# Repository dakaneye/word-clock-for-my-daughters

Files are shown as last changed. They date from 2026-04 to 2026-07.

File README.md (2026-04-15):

# word-clock-for-my-daughters

Two word clocks, one for each daughter, to be delivered around their 7th birthdays.

- **Emory** — Oct 6, 2030
- **Nora** — Mar 19, 2032

Shared ESP32 + WS2812B platform, per-kid configuration (name, birthday, wood species, lullaby, hidden birthdate acrostic).

See [`docs/superpowers/specs/2026-04-14-daughters-clocks-design.md`](docs/superpowers/specs/2026-04-14-daughters-clocks-design.md) for the full design.

## Lineage

Follows the original word clock for my wife Chelsea, built 2015 and revived 2026, at [`dakaneye/word-clock`](https://github.com/dakaneye/word-clock). Same family, newer generation.

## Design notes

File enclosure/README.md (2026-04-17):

# Enclosure

Laser-cut SVG files for the daughters' word clocks (Ponoko-ready) plus the
generators that produce them. See `docs/superpowers/specs/2026-04-15-laser-cut-face-design.md`
for the design spec.

## Files

| File | Description | Material |
|---|---|---|
| `emory-face.svg` | Emory's face — 192×192 mm, Jost Bold letters | Maple Hardwood 3.20 mm |
| `nora-face.svg` | Nora's face — 192×192 mm, Fraunces Medium letters | Walnut Hardwood 3.20 mm |
| `frame.svg` | 4 frame strips with box joints (geometry is kid-agnostic — same file used for both clocks, different material) | Maple 6.40 mm (Emory) or Walnut 6.40 mm (Nora) |

## Regenerating

```bash
cd enclosure/scripts
pip install -r requirements.txt
python build.py
```

Outputs all SVGs to `enclosure/`. Idempotent.

## Tests

```bash
cd enclosure/scripts
pytest
```

---

## Current state (continuing later)

Last commit: `fix(enclosure): aspect filter for Jost B + simplify for Fraunces serifs`

**What's working:**
- 43 pytest tests passing
- Build script generates clean `emory-face.svg`, `nora-face.svg`, `frame.svg`
- `frame.svg` already verified in Ponoko's design checker, dimensions correct (192 × 207 mm)
- Both face SVGs include closed-counter struts (1mm width, asymmetric bridges)
- Self-review workflow: cairosvg-based rendering of SVGs to PNG at `/tmp/svg_review/` for visual inspection without round-tripping through Ponoko

**Latest renders** (saved locally — reviewed before committing):
- `/tmp/svg_review/zoom_jost_v21.png` — Jost Bold closed letters with struts, zoom
- `/tmp/svg_review/zoom_fraunces_v21.png` — Fraunces Medium closed letters, zoom
- `/tmp/svg_review/full_emory_v21.png` — full Emory face
- `/tmp/svg_review/full_nora_v21.png` — full Nora face

**Strut rules** (in `enclosure/scripts/path_ops.py::BRIDGE_RULES`):
- `O Q 0`: 2 vertical struts at 12 + 6 o'clock
- `R P D B`: 1 horizontal strut on left stem (B: per counter = 2 total)
- `A`: 1 horizontal strut on left diagonal
- `G 6 9`: 1 horizontal strut on left

**Strut geometry** (`path_ops.py::_apply_bridges`):
- Width: 1 mm (Chelsea's clock precedent — below Ponoko's published 3mm min; user confirmed 1mm works on their laser)
- Asymmetric bridge: `body_margin = 3mm` (punches through thick strokes) + `counter_margin = 1.5mm` (just visible inside counter, avoids hitting interior features)
- Filters: skip holes where `min(w,h) < strut_width` OR aspect > 2.0 (sliver/crossbar artifacts from overlapping primitives)
- Post-union cleanup: `buffer(0)` + `simplify(0.05 × strut_width)` to remove sub-laser-precision spikes

## Known remaining issues / open questions

1. **Fraunces letters at full-face scale may still show fine artifacts.** User reported "splash effect on almost every letter" on Fraunces non-strut letters in earlier renders. Changes since then:
   - `opsz` 14 → 72 (display variant, cleaner outlines)
   - Bezier flattening 16 → 64 steps
   - `simplify()` pass after union
   
   Still needs user confirmation that current render (v21) actually resolves the splash on non-strut Fraunces letters (T, I, H, etc.). If splash persists:
   - Try different weight (500 → 700 Bold → might render cleaner)
   - Tune `simplify` tolerance larger (trade: more smoothing vs letter fidelity)
   - Investigate if specific Fraunces axes (SOFT, WONK) need different settings despite being set to 0

2. **Jost B visual density.** B with 2 horizontal struts on left stem looks like "E with a bowl" at zoom. At actual face scale (10mm letter), the 1mm notches are only ~10% of letter height each → 2 struts = 20% notched → acceptable. User can confirm when reviewing full-face render.

3. **Ponoko design-checker verification for face SVGs.** Frame.svg is verified. Face SVGs haven't been re-uploaded since the strut fixes started. Once v21 passes user review, re-upload for final geometry check before ordering.

## How to pick up

1. `git log --oneline -20` for recent changes.
2. `cd enclosure/scripts && pytest` — should be 43/43.
3. Review latest renders:
   ```bash
   PY=/Library/Developer/CommandLineTools/usr/bin/python3
   DYLD_FALLBACK_LIBRARY_PATH=/opt/homebrew/lib $PY <<'PYEOF'
   import re, sys, shutil
   sys.path.insert(0, '.')
   import cairosvg
   from pathlib import Path
   OUT = Path("/tmp/svg_review")
   OUT.mkdir(exist_ok=True)
   for name, src, fill, bg in [
       ("emory", Path("enclosure/emory-face.svg"), "#1a1208", "#dcc09a"),
       ("nora", Path("enclosure/nora-face.svg"), "#f0e0c0", "#3d2817"),
   ]:
       txt = src.read_text()
       txt = txt.replace('fill="none" stroke="#0000FF" stroke-width="0.01"', f'fill="{fill}"')
       txt = re.sub(r'(<svg [^>]*>)', lambda m: m.group(1) + f'<rect width="192" height="192" fill="{bg}"/>', txt, count=1)
       tmp = OUT / f"{name}_preview.svg"
       tmp.write_text(txt)
       cairosvg.svg2png(url=str(tmp), write_to=str(OUT / f"{name}_preview.png"), output_width=2000)
       print(f"Rendered {OUT / f'{name}_preview.png'}")
   PYEOF
   ```
4. Open `/tmp/svg_review/*.png` to review.
5. If struts or letter shapes still wrong: edit `enclosure/scripts/path_ops.py` (strut logic) or `enclosure/scripts/render_face.py` (font config, letter sizing).

## Relevant files

- Spec: `docs/superpowers/specs/2026-04-15-laser-cut-face-design.md`
- Implementation plan: `docs/archive/plans/2026-04-15-laser-cut-face-implementation.md` (archived — SVGs shipped)
- Grid source of truth: `firmware/lib/core/src/grid.cpp`
- PCB (for LED positions): `hardware/word-clock.kicad_pcb`
- Brainstorm session with visual history: `.superpowers/brainstorm/5705-1776357082/`

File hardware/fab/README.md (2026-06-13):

# As-ordered fabrication package — 63-LED board

Exact JLCPCB submission for the word-clock main board. This directory is the
immutable as-fabricated record for the 40-year build.

- **Ordered:** 2026-06-07 — JLCPCB, 5 boards, full PCBA (top-side, Economic).
- **Contents:** `word-clock-gerbers.zip` (gerbers + drill), `word-clock-cpl.csv`
  (component placement), `word-clock-bom.csv` (bill of materials). The unzipped
  `gerbers/` directory is gitignored — the `.zip` is the canonical artifact.
- **LED substitution (as-built ≠ as-listed):** `word-clock-bom.csv` lists the
  LED as **WS2812B-B/W (LCSC C114586)**, but the board was ordered with
  **WS2812B-V6 (LCSC C52917433)** — the only in-stock option at order time. The
  swap is a benign revision (standard 5050-4P pinout, 800 kHz GRB); the V6's
  longer (>280 µs) reset is irrelevant at word-clock update rates. Full
  rationale: `docs/hardware/pre-fab-review.md`.
- **LED count:** 63 (designators D1–D64, with D7 unused).

Re-exports from KiCad go to `hardware/regen/` (gitignored); do not regenerate
this package in place.

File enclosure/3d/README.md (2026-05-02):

# 3D-printed internals

Scripts that generate STL files for the parts inside the clock case:
PCB standoff posts, button actuator caps, light channel. Each script is
parametric Python via [build123d](https://build123d.readthedocs.io/) —
edit a dimension at the top, re-run, get a new STL.

(A 3D-printed speaker cradle was originally planned but dropped 2026-04-21
once the speaker was found to have integral M3-compatible mounting flanges.
Speaker mounts to 2× M3 hex spacers epoxied to the back-panel interior.)

## First-time setup

```bash
cd enclosure/3d
python3 -m venv .venv
.venv/bin/pip install --upgrade pip
.venv/bin/pip install -r requirements.txt
```

(The `.venv/` directory is gitignored — it's ~500 MB of cached
OpenCascade CAD geometry, rebuilt locally on demand.)

## Generate STLs

Generate one part:
```bash
enclosure/3d/.venv/bin/python enclosure/3d/pcb_standoff.py
```

Generate every part at once:
```bash
enclosure/3d/.venv/bin/python enclosure/3d/build_all.py
```

Outputs go to `enclosure/3d/out/*.stl` (gitignored — regenerate any time).

## Printer workflow

See `docs/hardware/3d-printing-setup.md` — Bambu Studio setup, A1
onboarding, per-part slicer settings, VS Code live-preview workflow.

## Printing one of these

1. Open Bambu Studio (the slicer that ships with the A1).
2. `File → Import → Import 3MF/STL` → pick the `.stl` from `out/`.
3. Orient the part on the build plate. For the standoff: flange down so
   the glue surface prints flat against the bed; no support needed.
4. Choose a filament profile (PLA is fine for every internal part).
5. Click *Slice → Send* to the printer.

## Parts in this directory

| Script | Part | Qty per clock | Design source |
|---|---|---|---|
| `pcb_standoff.py` | PCB standoff post | 4 | `docs/hardware/pinout.md` §standoff |
| `button_cap.py` | Button actuator cap | 3 | `TODO.md` 3D-printed internals |
| (future) `light_channel.py` | Honeycomb LED isolator | 1 | `TODO.md` + `docs/superpowers/specs/2026-04-15-laser-cut-face-design.md` §Track 5; design deferred until frame interior + PCB outline are measured |

## Authoring a new part — the quick shape

Every script in this directory follows the same three sections:

```python
"""Explain the part in plain English at the top."""
from build123d import *
from pathlib import Path

# ─── Parameters ──
# All dimensions in mm. Source of numbers in comments.
MY_DIAMETER = 10.0

# ─── Geometry ──
# Primitive shapes combined with +, -, &.
# `align=(CENTER, CENTER, MIN)` = bottom of shape at Z=0, centered in XY.
BOTTOM = (Align.CENTER, Align.CENTER, Align.MIN)
part = Cylinder(MY_DIAMETER / 2, 10, align=BOTTOM)

# ─── Export ──
out_dir = Path(__file__).parent / "out"
out_dir.mkdir(exist_ok=True)
export_stl(part, str(out_dir / "my_part.stl"))
```

## build123d quick reference

Primitive shapes:
```python
Cylinder(radius, height, align=...)
Box(length, width, height, align=...)
Sphere(radius, align=...)
```

Boolean combine:
```python
part = a + b      # union
part = a - b      # subtract
part = a & b      # intersect
```

Transforms (apply with `*`):
```python
moved  = Pos(x, y, z) * shape
rotated = Rot(rx, ry, rz) * shape   # degrees
```

More complex shapes via 2D sketches then `extrude()`:
```python
profile = Polygon((0,0), (10,0), (10,5), (0,5))
part = extrude(profile, amount=3)
```

Docs: https://build123d.readthedocs.io/en/latest/

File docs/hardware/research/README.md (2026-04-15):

# Hardware research notes

Per-component research for the daughters' clocks hardware. Each file cites its source and captures the specific facts that inform `docs/hardware/pinout.md` and future PCB design.

When a spec is challenged ("are you sure GPIO 0 must be HIGH?"), the chain of evidence is: pinout.md → this directory → original manufacturer doc.

## Components researched

| Component / topic | File | Last verified |
|---|---|---|
| MAX98357A (I²S amp) | [max98357a.md](max98357a.md) | 2026-04-15 |
| WS2812B (addressable RGB LED) | [ws2812b.md](ws2812b.md) | 2026-04-15 |
| DS3231 ZS-042 (RTC breakout module) | [ds3231-zs042.md](ds3231-zs042.md) | 2026-04-15 |
| HW-125 (microSD SPI breakout) | [hw125-microsd.md](hw125-microsd.md) | 2026-04-15 |
| ESP32-WROOM-32 GPIO boot behavior | [esp32-gpio-boot-behavior.md](esp32-gpio-boot-behavior.md) | 2026-04-15 |
| USB-C CC resistors without PD | [usb-c-cc-resistors.md](usb-c-cc-resistors.md) | 2026-04-15 |
| FastLED on ESP32 — peripheral choice + WiFi | [fastled-esp32.md](fastled-esp32.md) | 2026-04-15 |

## Deferred until Phase 2 bring-up reveals questions

Nothing currently blocking schematic or PCB work. Add here as new questions emerge.

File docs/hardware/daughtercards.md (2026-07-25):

# Daughtercard Mechanical Measurements

**Status:** v1 — measurements complete, custom footprints generated at
`hardware/word-clock.pretty/`. Combines the 1×N pin socket/header with
NPTH mounting holes locked relative to pin 1.

All three daughtercards plug into the main PCB on **B.Cu (back side)**. The
"top" orientation in the tables below is the user's caliper-measurement
orientation: pin row up, looking at the *component* side of the daughtercard.

## Erratum — NPTH holes mirrored on fabbed boards (observed 2026-07-25)

On the assembled boards the daughtercard mounting NPTHs land mirrored
relative to the cards' actual holes — only **one hole per card** lines up.
Both clocks' boards are affected (same fab batch). Likely cause: the hole
coordinates below were measured looking at the card's component side, but
the cards mount on B.Cu, where that view is mirrored (unverified against
the layout).

Field fix: secure each card with a single screw + nylon nut through the
one aligned hole — SD takes **M2** (⌀2.0 mm holes), RTC takes **M2.5**
(⌀3.0 mm holes; M3 is a press fit, don't use). One screw plus the header
socket is mechanically sufficient; the cards carry no load. Keep the RTC
screw clear of CR2032 access. If the boards are ever respun, mirror the
hole coordinates across the pin-row axis and verify against a physical
card held to the back side.

## SD card breakout (Stemedu / Catalex-style microSD)

| Property | Value |
|---|---|
| PCB length (long axis, perpendicular to pin row) | **42.0 mm** |
| PCB width (short axis, along pin row) | **24.3 mm** |
| Pin-to-pin overall (PCB top → tip of pins) | 46.2 mm |
| Pin row offset, pin 1 → nearest long edge | ~5.5 mm (pins centered along short edge) |
| Mounting holes | 4 — one in each corner |
| Each corner hole, distance from each adjacent edge | **~2.0 mm** (1.9–2.0 mm both directions) |
| Hole diameter | **2.0 mm** (M2 clearance) |

**Hole positions in local footprint coordinates** (anchor = pin 1 at
`(0, 0)`, pins along +Y, card body extending in -X):

| Hole | Local X | Local Y |
|---|---:|---:|
| Top-left (near pin 1) | -2.0 | -3.8 |
| Top-right (near pin 6) | -2.0 | 16.5 |
| Bottom-left | -40.0 | -3.8 |
| Bottom-right | -40.0 | 16.5 |

(Y range derived from card width 24.3 mm centered on pin row midpoint
Y=6.35: card Y = -5.8 to 18.5; holes 2 mm in from each long edge.)

## RTC module (DS3231 ZS-042, GODIYMODULES variant)

| Property | Value |
|---|---|
| PCB length (long axis, perpendicular to pin row) | **38.2 mm** (web spec: 38 mm, matches) |
| PCB width (short axis, along pin row) | **22.0 mm** |
| Pin-to-pin overall (PCB top → tip of pins) | 44.0 mm |
| Pin 1 offset from one long edge | 3.4 mm |
| Pin 6 offset from other long edge | ~4.5 mm |
| Pin row position | offset (not centered); pins shifted toward pin-1 long edge |
| Mounting holes | 3 |
| Hole diameter | **3.0 mm** |

**Mounting hole positions** (user-orientation, pin row at top):

| Hole | From left edge | From right edge | From top edge | From bottom edge |
|---|---:|---:|---:|---:|
| Top-left | 3 mm | — | 8 mm | — |
| Top-right | — | 2 mm | 8 mm | — |
| Bottom-right | — | 2 mm | — | 4 mm |

**Local footprint coordinates** (anchor = pin 1 at `(0, 0)`, pins along +Y,
card body extending in -X, "left edge" = the long edge near pin 1):

| Hole | Local X | Local Y |
|---|---:|---:|
| Top-left | -8.0 | -0.4 |
| Top-right | -8.0 | 16.6 |
| Bottom-right | -34.2 | 16.6 |

## Audio amp (MAX98357A breakout, GODIYMODULES variant)

Adafruit-style MAX98357A clone. Adafruit's published dims are 17.78 × 18.42 mm
which matches user's measurement of 17.7 × 19 mm closely.

| Property | Value |
|---|---|
| PCB long axis | **19.0 mm** |
| PCB short axis (pin row sits on this edge) | **17.7 mm** |
| Pin row | centered on short edge; ~1.23 mm margin each side (15.24 mm pin span) |
| Mounting holes | 2 — at the corners of the *far* short edge (opposite pin row), confirmed by user |
| Each mounting hole, distance from each adjacent edge | **~2.3 mm** |
| Hole diameter | **2.6 mm** |
| Card-body extension direction relative to our PCB pin row | **+X** (pins on left, body on right of pin column) |

**Hole positions in local footprint coordinates** (anchor = pin 1 at
`(0, 0)`, pins along +Y, card body extending +X):

| Hole | Local X | Local Y |
|---|---:|---:|
| Far-edge-near-pin-1 corner | +16.7 | 1.07 |
| Far-edge-far-from-pin-1 corner | +16.7 | 14.17 |

(Y range derived from card width 17.7 mm centered on pin row midpoint
Y=7.62: card Y = -1.23 to 16.47; holes 2.3 mm in.)

## Custom footprints

Generated and checked into `hardware/word-clock.pretty/`:

- `Daughtercard_SD_HW125.kicad_mod` — 1×6 horizontal pin socket + 4× ⌀2.0 mm NPTH at corners
- `Daughtercard_RTC_DS3231.kicad_mod` — 1×6 horizontal pin socket + 3× ⌀3.0 mm NPTH
- `Daughtercard_AMP_MAX98357A.kicad_mod` — 1×7 vertical pin header + 2× ⌀2.6 mm NPTH at far short edge

The library is registered as `word-clock` in `hardware/fp-lib-table`. To
swap a daughtercard's footprint in eeschema, edit the symbol's Footprint
property to e.g. `word-clock:Daughtercard_SD_HW125`, then push the change
to PCB via Tools → Update PCB from Schematic. The new footprint replaces
the old socket and the mounting holes appear locked to pin 1 — drag the
connector and the holes follow.

Generated by `/tmp/gen_daughtercard_footprints.py` (which can be re-run if
measurements change).

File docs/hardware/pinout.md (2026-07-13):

# ESP32 Pinout — Daughters' Clocks

**Status:** v0 — source of truth for KiCad schematic (activity B), firmware config (Phase 2), and PCB layout (activity D). Subject to minor revisions if breadboard bring-up reveals pin conflicts or noise issues.

**Target module:** ESP32-WROOM-32 (classic ESP32, not S2/S3/C3). AITRIP 3-pack dev board from the Phase 2 parts order.

## ESP32 GPIO rules (for reference while reading this)

- **GPIO 6-11:** reserved for internal SPI flash. NEVER use.
- **GPIO 0, 2, 5, 12, 15:** strapping pins — have constraints at boot. Usable but with care.
- **GPIO 1, 3:** UART0 TX/RX — keep free for USB serial logging/flashing.
- **GPIO 34-39:** input-only, no internal pullup/pulldown.
- **GPIO 25, 26:** DAC-capable (unused here — we use I²S digital audio instead).

## Signal assignments

| GPIO | Direction | Signal | Subsystem | Notes |
|---:|---|---|---|---|
| 0 | — | (strapping, unused) | — | Must be HIGH at boot for run mode. Dev board has built-in pullup + BOOT button. On PCB: 10kΩ pullup to 3.3V. **Do not leave floating.** |
| 1 | TX | UART0 TX | Debug | USB serial console — reserved |
| 2 | — | (strapping, unused) | — | On-board LED on many dev boards; leave unused to avoid conflicts |
| 3 | RX | UART0 RX | Debug | USB serial console — reserved |
| 4 | — | (reserved) | — | Free for future use |
| 5 | OUT | SD CS | microSD | VSPI CS. Strapping pin — pull HIGH at boot to prevent boot loop |
| 12 | — | (strapping, unused) | — | Controls flash voltage (must be LOW at boot for 3.3V flash). Default pulldown is correct. Reserved — don't drive HIGH during boot. |
| 13 | OUT | LED_DATA | WS2812B | Data line into the LED strip. 3.3V→5V level may need a 74HCT245 or similar on PCB; test on breadboard first. |
| 14 | IN | BUTTON_AUDIO | Buttons | Play/stop audio. INPUT_PULLUP in firmware. |
| 15 | — | (strapping, unused) | — | HSPI CS default. Leave unused — HSPI not used here. |
| 16 | — | (reserved) | — | Free for future use |
| 17 | — | (reserved) | — | Free for future use |
| 18 | OUT | SD CLK | microSD | VSPI SCLK |
| 19 | IN | SD MISO | microSD | VSPI MISO |
| 21 | I/O | I²C SDA | RTC | Default I²C bus for DS3231. 4.7kΩ pullup — see Power section caveat. |
| 22 | OUT | I²C SCL | RTC | Default I²C bus for DS3231. 4.7kΩ pullup — see Power section caveat. |
| 23 | OUT | SD MOSI | microSD | VSPI MOSI |
| 25 | OUT | I²S LRC (WS) | Audio | MAX98357A word-select (LRCLK) |
| 26 | OUT | I²S BCLK | Audio | MAX98357A bit clock |
| 27 | OUT | I²S DIN | Audio | MAX98357A serial data in |
| 32 | IN | BUTTON_HOUR | Buttons | Hour-set button. INPUT_PULLUP. |
| 33 | IN | BUTTON_MINUTE | Buttons | Minute-set button. INPUT_PULLUP. |
| 34 | — | (reserved) | — | Input-only; free for future use |
| 35 | — | (reserved) | — | Input-only; free for future use |
| 36 | — | (reserved) | — | Input-only; free for future use |
| 39 | — | (reserved) | — | Input-only; free for future use |

## Subsystem summary

| Bus | Pins | Peripheral(s) |
|---|---|---|
| UART0 | 1 (TX), 3 (RX) | USB-serial debug |
| I²C | 21 (SDA), 22 (SCL) | DS3231 RTC |
| VSPI | 18 (CLK), 19 (MISO), 23 (MOSI), 5 (CS) | microSD card breakout |
| I²S | 25 (LRC), 26 (BCLK), 27 (DIN) | MAX98357A amplifier |
| GPIO | 13 (LED DATA), 14/32/33 (3 buttons) | WS2812B, tact switches |

## Power

- **Input:** USB-C from the back panel via a captive USB-C-to-USB-C cable (3-6 ft) permanently plugged into the ESP32 module's on-board USB-C port (the delivered AITRIP modules are USB-C, not the micro-USB assumed pre-delivery); the USB-C end exits through a back-panel cable hole at the bottom-right. The hole is 16 mm (drilled out from the as-cut 6 mm during assembly) so the USB connector overmold can thread through; strain relief comes from an internal cable P-clip screwed to the back-panel interior 2-3 cm in from the hole, not the grommet. No panel-mount adapter, no pigtail, no breakout board. The CP2102 bridge on the module handles enumeration for firmware flashing; the module's 5V pin feeds the main +5V rail. The Cermant USB-C breakout that originally appeared on the schematic was removed before submission; the rework record is archived at `docs/archive/hardware/2026-04-17-usb-c-breakout-removal.md`. Power negotiation is now whatever the module's USB-C input does (no PD chip anywhere; relies on the 5V/2A charger delivering full rated current).
- **Power budget (worst case):**
  - WS2812B 63 LEDs full white: ~3.8A @ 5V unconstrained — but firmware caps total LED draw at 1700 mA via `FastLED.setMaxPowerInVoltsAndMilliamps(5, 1700)` (sized for a 3 A USB-C supply, leaving headroom for the ESP32 + amp).
  - ESP32 WiFi active peak: ~500 mA @ 5V (after 3.3V reg) = 2.5W
  - MAX98357A at full 3W audio: ~600 mA @ 5V = 3W
  - **Combined peak with the 1700 mA LED cap: ~2.8A / 14W** — within a 3 A USB-C supply.
- **Mitigation:** the FastLED power cap auto-scales global brightness so the strip never exceeds 1700 mA no matter how many words are lit; bedtime dim plus rare audio keep typical draw well below peak (<700 mA).
- **5V rail:** powers WS2812B strip directly, plus MAX98357A.
- **3.3V rail:** from ESP32 dev board's onboard regulator (AMS1117-3.3). Powers DS3231, microSD breakout, MAX98357A logic, button pullups.
- **Decoupling:** 100nF ceramic on every IC's Vcc pin (added on PCB, not breadboard).
- **Bulk cap:** 1000µF electrolytic near the LED strip's 5V input (smooths WS2812B current spikes).
- **LED data line:** 300Ω series resistor in-line with DIN recommended (protects the first LED from voltage spikes on startup).
- **I²C pullups:** 4.7kΩ SDA + SCL — **verify the DS3231 breakout doesn't already have pullups** before adding them on the PCB. Stacking pullups drives the bus too hard. Adafruit DS3231 boards include pullups; cheaper clones vary.

## Mechanical — bottom-side component heights

Measured from the bottom face of the PCB outward. Drives the back-panel standoff
height (≥ tallest feature) and the total enclosure-depth budget.

| Ref | Part | Package | Est. height (mm) | Source |
|---|---|---|---:|---|
| C2 | 1000µF / 10V electrolytic | `CP_Radial_D10.0mm_P5.00mm` | **16** | common D10 radial cap spec; spec already cites this |
| U1 | ESP32-WROOM-32 dev module (52.16×28.47 mm PCB, 1.14 mm thick) | `ESP32_38Pin` on 2.54 mm headers | **12.26 (measured)** | Full stack end-to-end caliper-measured 2026-04-20. Slightly under the 13 mm estimate. |
| J_AMP1 | 1×7 header + MAX98357A breakout (GODIYMODULES clone, 17.66×18.73 mm PCB) | `PinHeader_1x07_P2.54mm_Vertical` + daughter | **~11.3** (no terminal, measured) / **~19** (screw-terminal) | 8.5 mm header + 1.6 mm breakout PCB + 1.23 mm chip side *(caliper-measured 2026-04-20; total breakout + component = 2.83 mm)*. **+8 mm if using screw-terminal variant** — decision: **skip the terminal**, solder JST-PH2.0 speaker leads direct to `+` / `−` pads. |
| J_RTC1 | 1×6 header + DS3231 ZS-042 (21.83×38.28 mm PCB, 1.09 mm thick) | `PinHeader_1x06_P2.54mm_Vertical` + daughter | **12.6 (measured)** | Full stack end-to-end (male pin tip through PCB to top of CR2032 holder) caliper-measured 2026-04-20. Module ships with 1×6 male header pre-soldered — no header to install. ~2.4 mm shorter than original 15 mm estimate. |
| J_SD1 | 1×6 header + HW-125 microSD breakout (24.22×42.03 mm PCB, 1.54 mm thick) | `PinHeader_1x06_P2.54mm_Vertical` + daughter | **7.27 (measured)** | Caliper-measured 2026-04-20; the pre-soldered 1×6 pin connector is the tallest feature (taller than the SD-card slot). ~5.7 mm shorter than original 13 mm estimate. Module ships with pin header pre-soldered — no header to install. |
| SW1-3 | 6 mm tact switches | `SW_PUSH_6mm` | **~8** | 5 mm body + 3 mm plunger |
| C1, C3-C6 | 100 nF ceramic disc | `C_Disc_D5.0mm_W2.5mm_P5.00mm` | **~7** | 5 mm disc + leads |
| U2 | 74HC245 DIP-20 | `DIP-20_W7.62mm` | **~4** | direct solder; add ~5 mm if using a socket |
| R1 | 300Ω 0207 axial (horizontal) | `R_Axial_DIN0207` | **~3** | horizontal orientation |

**Tallest feature (all caliper-measured 2026-04-20):** DS3231 at 12.6 mm and ESP32 module at 12.26 mm tie as the tallest installed daughterboards. All four measured under their original estimates — ESP32 12.26 mm (−0.74), MAX98357A 11.33 mm (−0.67), DS3231 12.6 mm (−2.4), HW-125 7.27 mm (−5.73). The screw-terminal-equipped MAX98357A variant would still be ~19 mm but we're skipping the screw terminal.

**Confidence:** [HIGH] for all four daughterboards — caliper-verified 2026-04-20.

**Headroom in standoff budget:** with all daughterboards measured, the 20 mm standoff recommendation has ~7.4 mm of headroom against the tallest (DS3231 at 12.6 mm). **Decision window open:** the standoff could drop from 20 mm to 15 mm and grow the light channel from 18 mm to ~23 mm for measurably better LED diffusion. Trade-off: tighter depth tolerance (2.4 mm margin vs 7.4 mm) and no assembly slack for thicker-than-expected components. Re-decide after diffuser-stack validation on the breadboard (Step 5 outcome).

**Back-panel standoff recommendation:** **20 mm** (off-the-shelf brass M3 standoff size; clears the MAX98357A screw-terminal variant with ~1 mm margin; clears all other components with 5+ mm margin).

**Enclosure-depth budget** (48 mm frame, per `enclosure/scripts/render_frame.py`):

| Layer | Thickness (mm) |
|---|---:|
| Face (wood, glued to top of frame) | 3.2 |
| Diffuser (paper or frosted PETG) | ~0.5 |
| Light channel | ~18 (remainder — see below) |
| PCB | 1.6 |
| Standoff (air gap for bottom-side components) | 20 |
| Back panel (wood) | 3.2 |
| Sum + ~1.5 mm assembly slack | 48 |

Light-channel depth of ~18 mm is well above the minimum for WS2812B diffusion (roughly 1× LED spacing ≈ 14 mm), so pockets will mix to uniform light before reaching the diffuser. If the MAX98357A variant turns out to be the 12 mm non-screw-terminal kind, the standoff can drop to 15 mm and the light channel can grow to ~23 mm for even better diffusion — decide after caliper pass.

## Firmware constants

When Phase 2 firmware modules land, these macros should be defined in a shared header (e.g., `firmware/configs/pinmap.h`) and imported by every module that touches hardware:

```cpp
#pragma once

// WS2812B LED strip
#define PIN_LED_DATA     13

// DS3231 RTC (I²C default pins)
#define PIN_I2C_SDA      21
#define PIN_I2C_SCL      22

// microSD card (VSPI)
#define PIN_SD_CS         5
#define PIN_SD_MOSI      23
#define PIN_SD_MISO      19
#define PIN_SD_CLK       18

// MAX98357A I²S amplifier
#define PIN_I2S_BCLK     26
#define PIN_I2S_LRC      25
#define PIN_I2S_DIN      27

// Tact switches (INPUT_PULLUP)
#define PIN_BUTTON_HOUR   32
#define PIN_BUTTON_MINUTE 33
#define PIN_BUTTON_AUDIO  14
```

## Datasheet-verified peripheral compatibility

Cross-checked 2026-04-15 against Adafruit NeoPixel Überguide, MAX98357A datasheet, DS3231 ZS-042 docs, and HW-125 microSD module docs.

| Peripheral | Vin range | 3.3V logic compatible? | Notes |
|---|---|---|---|
| **MAX98357A** | 2.5-5.5V (use 5V for full output) | ✅ yes — I²S tolerates 3.3-5V | Default GAIN = 9dB (floating). SD pin has internal 100kΩ pulldown; Adafruit breakout adds 1MΩ pullup to Vin → stereo-averaged output. Leave SD unconnected. |
| **DS3231 (ZS-042 module)** | 2.3-5.5V | ✅ yes — I²C is open-drain | **⚠️ Charging-circuit bomb — see Critical issues below.** Most ZS-042 clones have 4.7k-10k pullups onboard; verify with a multimeter before adding duplicates. |
| **MicroSD breakout (HW-125 style)** | 5V input OK | ✅ yes — onboard 3.3V regulator + 74LVC125A level shifter | Wire VCC to 5V, not 3.3V — the onboard regulator and level shifter need the higher input to work as designed. |
| **WS2812B LED strip** | 5V strict | **❌ no — needs level shifter** — see Critical issues below. | 60 mA / LED max; use 20 mA average for budgeting. |

## Critical issues to resolve BEFORE powering anything up

These are hardware modifications or additions required for safe operation. Do them in this order.

### ⚠️ 1. DS3231 ZS-042 trickle-charge circuit — skip the removal, mitigate with battery-swap cadence

**Decision (2026-04-20): we are NOT removing the 200Ω + 1N4148 trickle-charge resistor.** See `docs/hardware/assembly-plan.md` §Long-term maintenance for the CR2032 replacement cadence that makes this safe.

**The FUD-free picture:** The ZS-042 module has a 200Ω + 1N4148 trickle-charge circuit intended for rechargeable LIR2032 cells. We run a non-rechargeable CR2032 instead. The circuit only attempts to charge the battery when Vbat drops below (Vcc − 0.7V) — because the 1N4148 is reverse-biased otherwise.

At the design's **3.3V VCC** (DS3231 ties to the ESP32 module's 3V3 pin, not the 5V rail), the effective charge voltage is 3.3 − 0.7 = **2.6V**. A fresh CR2032 sits at 3.0V. The diode is reverse-biased → **zero charge current flows**. The circuit is functionally inert as long as the battery is above end-of-life voltage.

**What actually creates risk:** letting the CR2032 discharge below ~2.6V before replacement (it would then start charging, with leak/vent potential over years). Mitigation is replacement schedule, not hardware modification — see assembly-plan.md.

**Do NOT wire VCC to 5V.** On 5V the math inverts: 5.0 − 0.7 = 4.3V applied to the CR2032 (above its 3.0V) → active charging while powered → trickle-charge circuit engages → real risk. Our `pinmap.h` / pinout table ties DS3231 VCC to 3V3 intentionally.

### 🔴 2. WS2812B: level shifter is required, not optional

Adafruit's NeoPixel Überguide explicitly warns: **"a 3.3V signal may not work reliably."** The WS2812B logic HIGH threshold is 0.7 × Vdd = 3.5V at 5V supply. ESP32 outputs 3.3V max — 200 mV below threshold.

**Sometimes it works** (strip length, ambient temperature, LED batch tolerance all affect it). Sometimes only the first 10 LEDs light correctly. Sometimes colors drift. Relying on it is a bad idea for a keeper clock that must work for decades.

**Action:** include a **74HCT245** octal bus transceiver (or 74HCT125 quad buffer, same thing for this purpose) on the data line, powered from 5V, input from ESP32 GPIO13. The HCT family has TTL-compatible input thresholds — reliably reads 3.3V as HIGH and outputs 5V HIGH. Cost: ~$1. Not on the current wishlist; add to next order or rob from another project.

Alternative workaround (lower quality): single diode in series on Vdd to drop NeoPixel supply to ~4.3V, lowering the HIGH threshold to ~3.0V. Works but adds heat and reduces brightness. Not recommended for production.

### 🔴 3. WS2812B bulk capacitor is REQUIRED before power

Adafruit: "connect capacitor before applying power." A 1000µF electrolytic across the LED strip's +5V and GND inputs absorbs the inrush when all LEDs power up white. Already listed in the Power section — calling it out again here because skipping it can fry individual LEDs on first power-up.

## Pre-power smoke test (breadboard-bring-up protocol)

Follow this sequence when the parts arrive. **Do not skip steps.** Each check takes ~1 minute; total ~15 minutes before first power-on.

1. **Visual inspection.** Every breakout on a clean table. Verify no shipping damage, no bent pins, no foreign material.
2. **Multimeter: USB-C breakout.** Plug USB-C, verify 5.0V ±0.25V between 5V pad and GND pad. Verify CC1 and CC2 pads each show ~5.1kΩ to GND (unplugged). If either reading is wildly off — different board batch. Stop.
3. **Multimeter: DS3231 module.** With no battery installed:
   - Do **NOT** remove the 200Ω trickle-charge resistor (decision 2026-04-20, §1 above): at 3.3V VCC the 1N4148 is reverse-biased so it's inert with a fresh cell. The CR2032 is protected by the 5-year replacement cadence, not a desolder.
   - Verify SDA-to-Vcc and SCL-to-Vcc pullup resistance — typically 4.7k-10k. Note value for later; if present, **do not add external pullups to the PCB**.
   - Install a fresh CR2032 (+ side up).
4. **Multimeter: MAX98357A.** Verify GAIN pad (center) is not shorted to anything by default (floating → 9dB). Verify SD pad has a weak pulldown to GND (~100k) or weak pullup to Vin (1MΩ on Adafruit).
5. **ESP32 alone, no peripherals:**
   - Connect USB-C breakout to the ESP32's 5V and GND rails.
   - Apply USB-C. Measure 3.3V rail on the ESP32 — should read 3.30V ±0.1V.
   - Flash a blink sketch. Confirm the ESP32 runs. Disconnect power.
6. **Add RTC:**
   - Wire SDA, SCL, Vcc (3.3V), GND.
   - Flash an I²C scanner sketch. Expect to see address `0x68` (DS3231). Disconnect power.
7. **Add microSD breakout:**
   - Wire VSPI pins (CLK, MOSI, MISO, CS) and VCC to 5V, GND.
   - Insert a formatted FAT32 card.
   - Flash an SD read-test sketch. Confirm file listing. Disconnect power.
8. **Add MAX98357A:**
   - Wire I²S pins (BCLK, LRC, DIN), Vcc to 5V, GND, speaker via the JST-PH2.0 pigtail.
   - Flash a 440 Hz tone test. Confirm audible tone. Disconnect power.
9. **Add WS2812B (after level shifter):**
   - Wire 74HCT245: Vcc to 5V, GND to GND, A-input from GPIO13, B-output to strip DIN, OE/DIR tied for unidirectional.
   - Add 1000µF cap across strip +5V and GND, installed first.
   - Wire strip Vdd to 5V (short run, 18 AWG or better), GND to breadboard GND.
   - Flash a single-LED test at low brightness (e.g., 10/255). Confirm first LED lights the correct color. Then test 5 LEDs. Then the full 25.
10. **Full integration:** only after steps 1-9 pass independently, flash the Phase 2 firmware and run the full rig.

If any step fails, stop and debug **that step** before adding another peripheral.

## Revision log

- **v0 (2026-04-15):** Initial assignment based on ESP32-WROOM-32 standard pin conventions, Adafruit ESP32 Feather + MAX98357A reference designs, and the parts in the Phase 2 order. Locked pending breadboard validation (Phase 2 activity R).
- **v0.1 (2026-04-15, same day review):** Corrected GPIO 0 advice (was misleadingly said "leave floating"). Added power-budget analysis (worst case ~2.6A exceeds USB-C-without-PD spec). Added 300Ω series on LED data, I²C pullup-stacking caveat. Removed stale "Audio BFF" reference (that product is for QT Py, not classic ESP32).
- **v0.2 (2026-04-15, after datasheet review):** Added datasheet-verified compatibility table. **Critical findings:** (1) DS3231 ZS-042 module has a battery-charging circuit that must be disabled before installing a non-rechargeable CR2032 — risk of battery leak/explosion. (2) WS2812B level shifter (74HCT245) is REQUIRED, not optional — Adafruit explicitly warns 3.3V signals are unreliable. Added full pre-power smoke-test protocol. Raw research saved to `docs/hardware/research/`.

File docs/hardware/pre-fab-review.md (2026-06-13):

<!-- docs/hardware/pre-fab-review.md -->
# Pre-fab review — 63-LED board

> **ORDERED 2026-06-07** — JLCPCB, 5 boards, full PCBA (all 5 assembled, top-side
> Economic). Files: `hardware/fab/` (gerbers zip + CPL + BOM). LED substituted to
> **WS2812B-V6 (LCSC C52917433)** — only in-stock option; benign revision swap
> (standard 5050-4P pinout, 800 kHz GRB, V_IH handled by U2; V6's >280 µs reset is
> irrelevant at word-clock update rates). Confirm Production File + Confirm Parts
> Placement both set to Yes. On delivery: JLC placed only the 63 SMD LEDs — hand-
> solder all THT (ESP32 module, RTC/SD/amp headers, U2, R1, C2 + 100 nF caps,
> buttons), then run `firmware/test/hardware_checks/display_checks.md` (esp. the
> D1-glows-RED / GRB color-order check).

Findings from the full design audit (connectivity, power integrity, firmware
parity, ERC/DFM) and the actions to take before fabrication. The board is
electrically complete (0 unconnected, 0 DRC/ERC errors) and verified to light
evenly (worst-case +5V droop ~3 mV, <0.1%). Items below are correctness fixes
and good-practice hardening, in priority order.

## Verification (kicad-mcp-pro, 2026-06-05)

Full MCP validation suite run against the canonical board. **0 DRC errors,
0 unconnected** (confirmed by three independent tools), **0 ERC errors**. The
34 warnings are all benign and individually classified:

- 21 × silkscreen clipped by soldermask — cosmetic.
- 2 × daughtercard footprint ≠ library copy (SD HW-125, RTC DS3231) — cosmetic;
  the board's embedded footprint is authoritative for fab.
- 3 × connector symbol ≠ library (`Conn_01x06/07`) — cosmetic, pre-existing.
- 7 × "tri-state and power input connected" — U2's 7 unused inputs (A2–A8)
  correctly tied to GND. ERC pin-matrix false positive, not a defect.
- 1 × "74HCT245 not found in 74xx" — the 74HC→74HCT rename; the schematic's
  embedded symbol copy is electrically valid (this KiCad's `74xx` lib ships HC,
  not HCT). Optional cleanup: point the `lib_id` at `74xx:74HC245` (pin-identical)
  and keep `Value`=74HCT245 to silence the warning.

DFM "FAIL" lines are tool artifacts: "via drill -0.000 mm" is a parse bug
(`get_board_stats` shows real via drills at 0.300 mm); "DRC violations: 23"
re-counts the warnings above. Footprint-vs-schematic "FAIL" is only H1–H4
(NPTH mounting holes, no schematic symbol by design).

**Level shifter U2 (74HCT245) wiring verified from the board netlist:**
DIR=+5V (A→B), OE#=GND (enabled), A1=/LED_DATA_3V3 in, B1=/LED_DATA_5V out
(matched channel), unused inputs→GND, unused outputs floating. Data path:
`ESP32 GPIO13 → A1(3.3V) → B1(5V) → R1 300Ω → D1 DIN`.

**Firmware↔PCB parity verified:** the 35 per-word LED counts in
`firmware/lib/display/src/led_map.cpp` match the PCB's LED `Value` fields
exactly (35 words / 63 LEDs), and the spans tile the chain [0,63) with no gaps
or overlaps.

**LED grid + chain fully verified (2026-06-06):**
- Every LED is on a clean 13.68 mm row lattice; all **63/63 sit on the correct
  grid row** for their word, and **63/63 fall within the correct word's column
  span** (checked against `firmware/lib/core/src/grid.cpp`).
- The **physical daisy-chain (DOUT→DIN) order exactly matches the firmware
  `led_map` index order** (0 mismatches): data enters at D1 (IT, ← R1), exits at
  D63 (tail, DOUT open). So firmware index i lights the correct physical letter.
- CPL placement positions match the PCB footprint positions for all 63 LEDs.

Remaining parity is physical-only — **GRB color order** and face-overlay
registration — bench checks in
`firmware/test/hardware_checks/display_checks.md` (§2–§3).

## Already done (in this change)

- **Reconciled the rerouted board into canonical** `hardware/word-clock.kicad_pcb`
  (it was the old 15-unconnected hand-routed board; now it's the rerouted
  0-unconnected one, 187 vias). Verified by kicad-cli: **0 DRC violations,
  0 unconnected, 0 ERC errors.** Pre-reconcile board saved as
  `.pre-reconcile-*` if you need to compare.
- **74HC245 → 74HCT245** (U2 level shifter): the ESP32 drives the LED-data
  input at 3.3 V, below the 74HC high threshold (~3.5 V at 5 V VCC). 74HCT's
  threshold (~2.0 V) is in spec. Updated in the schematic, **PCB silk**, master
  BOM (`hardware/word-clock.csv`), and datasheet link.
- **Regenerated all fab exports for 63 LEDs** (the old ones were stale at 35),
  in `hardware/regen/`:
  - `word-clock-cpl.csv` — JLCPCB placement, 63 LEDs. **Verified:** transform
    reverse-engineered from the known-good 35-LED CPL and confirmed (D1 matches
    exactly). All 63 LEDs are **rotation 0, layer Top (F.Cu)** — uniform, no
    finicky rotations.
  - `word-clock-pcba-bom.csv` — 63 designators, LCSC C114586.
  - `word-clock-bom.csv` / `word-clock-pos.csv` — full BOM / raw KiCad pos
    (reference). NB: the raw KiCad `pos` export labels the LEDs "bottom" — that
    is a CLI artifact; the LEDs are on **F.Cu = Top** (the CPL is authoritative).
  Replace the stale `word-clock-*-pos.csv` / `word-clock-pcba-bom.csv` with
  these after the board reconciliation (step 1) and re-export the pos from the
  reconciled board so positions are sourced from the canonical file.
- **Firmware reconciled to 63 LEDs** (separate change): `LED_COUNT=63`,
  per-word LED spans derived from the PCB. Words now light fully and evenly.

### Decouple U2 — C1 moved +3V3 → +5V  (DONE 2026-06-06)
C1 (100 nF) sits **3.8 mm from U2** but was wired to **+3V3**, while U2 is a
**+5V** part and the ESP32 (the only +3V3 IC) is 80 mm away — a mis-railed
decoupling cap for U2. **Fixed and verified** (0 ERC errors, 0 DRC errors,
0 unconnected):
- Schematic: C1's `+3V3` pin detached and connected to a new `+5V` symbol.
  The +3V3 PWR_FLAG (`#FLG01`) was left in place on the remaining +3V3 stub,
  so +3V3 stays driven/flagged — the failure mode that broke an earlier
  by-hand swap (FLG short + `#PWR021` undriven) is avoided.
- PCB: C1 pad 1 re-netted to +5V and connected by a short F.Cu track straight
  to U2 pin 1 (+5V), 3.8 mm away — a low-inductance decap tie at U2's power
  pin. C1's orphan +3V3 branch (3 segments) was removed, each DRC-confirmed
  dangling; J_RTC1, C4, and the ESP32 stayed connected throughout. Zones
  refilled.

## Must do before fab

(none — the items below are resolved or judgment calls.)

### 3. Confirm daughtercard onboard pull-ups (assembly-time)
The main PCB has **no** I²C pull-ups and does not tie the MAX98357A SD_MODE —
both rely on the breakout modules:
- **RTC (ZS-042 / DS3231):** confirm it populates the onboard 4.7 k SDA/SCL
  pull-ups (most do). Without them, I²C floats and the RTC is unreadable.
- **Amp (MAX98357A breakout):** SD pin (shutdown + L/R select) and GAIN are
  left open, relying on the breakout's onboard pull-ups (SD pulled up =
  enabled, (L+R)/2 mono). Confirm the specific breakout populates them, or
  tie SD to a defined level — it doubles as a useful software-mute line.

Buttons need no external pull-ups: firmware sets `INPUT_PULLUP` on
GPIO32/33/14 (verified in `firmware/lib/buttons`).

## Optional / judgment calls

### 4. Input protection — optional, low marginal value
The audit flagged no fuse / reverse-polarity at the +5 V entry (back-fed
through the ESP32 dev-board VIN pin). In practice this is largely covered by
the USB-C supply's own limiting and the dev-board's USB protection, and
reverse polarity is not possible with USB-C. If you want belt-and-suspenders
on a 40-year keepsake, add a **polyfuse (~2 A)** in series at the +5 V entry
(a series Schottky / ideal-diode P-FET would add reverse-polarity protection
but costs ~0.3 V and board space). This adds parts + routing on a full
board — do it deliberately in KiCad, not as a quick patch.

### 5. Solid +5 V plane re-pour — not recommended
CLAUDE.md's intent was a solid B.Cu +5 V plane; the autoroute carved it into
one large island + a few bridged fragments. **This is already verified
electrically fine** (even-lighting droop ~3 mV; 54/63 LEDs on the main plane,
the rest behind low-current bridges). Re-routing a verified-working board to
chase a prettier plane risks regression for no functional gain. Skip unless
there's a specific reason.

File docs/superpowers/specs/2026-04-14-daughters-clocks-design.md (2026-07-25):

# Daughters' Word Clocks — Design Spec

Date: 2026-04-14
Status: Design locked, ready for implementation planning

## Overview

Two word clocks, one for each daughter, delivered around age 7. Same hardware platform, same firmware, per-clock configuration for name, birthday, acrostic, wood species, and lullaby. Intended to last 40+ years and feel handmade like Chelsea's — same DNA, newer generation.

- **Emory** — born 2023-10-06 — target delivery 2030
- **Nora** — born 2025-03-19 — target delivery 2032

## Scope

One design spec covers both clocks. Differences are configuration values, not design variants.

| Attribute | Emory | Nora |
|---|---|---|
| Face material | birch plywood | walnut |
| Name in grid (row 9) | EMORY | NORA |
| Birthday date | Oct 6 | Mar 19 |
| Hidden acrostic | `EMORY 10 6 2023` (12 chars / fillers) | `NORA MAR 19 2025` (13 chars / fillers) |
| Voice memo at birth minute | 6:10 PM, Dad's voice | 9:17 AM, Dad's voice |
| Lullaby (on-demand button) | one song recorded by Dad | one song recorded by Dad |
| Signature everyday color | warm white | warm white |

## Hardware Platform

- **MCU:** ESP32 (Arduino-core compatible). Picked for WiFi, I2S audio, mature libraries.
- **Time source:** NTP over WiFi; DS3231 RTC as offline fallback.
- **WiFi provisioning:** captive portal on first boot (phone connects to temporary AP, enters SSID + password in browser form). USB-C available as debug + firmware update path.
- **LEDs:** WS2812B RGB, one per word group (~25 per clock).
- **Audio:** MAX98357A I2S DAC + amp, small speaker (~2-3W), microSD card for 16-bit PCM WAV files (44.1 kHz mono). Format was flipped from MP3 during audio-module spec (`docs/superpowers/specs/2026-04-18-audio-design.md`) — eliminates the MP3 decoder dependency.
- **Power:** USB-C only. Any standard 5V/2A source drives the full system. No wall adapter specific to the clock.
- **Buttons:** three tact switches on the right side — hour set, minute set, audio play/stop.
- **No power button.** Always on when plugged in.

## PCB

Single board, ~150mm × 150mm, matching face dimensions. JLCPCB PCBA service assembles both sides.

- **Top side:** WS2812B LEDs placed under each word group on the face.
- **Bottom side:** ESP32 module, I2S amp, microSD slot, USB-C, buttons, DS3231, passives.
- **Connector to speaker:** 2-pin JST.

## Enclosure

Shadow-box construction. All visible exterior is wood. Plastic is hidden inside.

- **Face:** laser-cut wood (cut-through letters, not etched — the diffuser paper backing glows through the openings). Birch for Emory, walnut for Nora.
- **Side frames (4 pieces):** matching wood species, glued to form the box depth.
- **Back panel:** matching wood, engraved with dedication ("For Emory / love Dad" etc.). Carries 3 button access holes with "Hour / Min / Audio" labels next to each, a speaker vent grid, and one cable exit hole (~16 mm — drilled out from the as-cut 6 mm with a 5/8" step bit at assembly so the USB connector overmold can pass through). A permanently-installed Micro-USB-to-USB-C cable connects the ESP32 module's micro-USB port to the outside world; strain relief is provided by an internal cable P-clip screwed to the back-panel interior 2-3 cm in from the hole (the enlarged hole is too loose for a grommet to grip the cable). **Must be fully removable without damaging the wood, repeatably over 40+ years** — the DS3231 CR2032 coin cell needs replacement every 5-10 years. Attachment: 4 × M3 × 1/2"–5/8" wood screws threaded directly into the 6.4 mm hardwood frame wall at the existing 4 mm-inset corner positions, into pre-drilled ~2 mm pilot holes. The 4 mm panel inset puts the screw centers inside the wall thickness so screws bite into wood. (Original plan — M3 hex spacers epoxied into interior corners + machine screws — abandoned 2026-04-25 after the 4 mm-inset panel geometry was found to make spacer-in-corner placement impossible; the bug became a feature once we switched to wood-screws-into-wall.) Speaker mounts to 2 × M3 hex spacers epoxied to the back-panel interior 37 mm apart behind the vent — no 3D-printed cradle, the speaker has integral M3-compatible mounting flanges. The DS3231 and HW-125 daughterboards install with their battery holder / card slot facing the back panel (right-angle 1×6 sockets on B.Cu enforce this geometrically) so the CR2032 and SD card remain accessible after removing the panel.
- **Internal:** 3D-printed in white PLA — light channel honeycomb (isolates each LED to its word), PCB standoffs, speaker mount, button housings. Never seen.
- **Diffuser:** Selens self-adhesive diffusion film (0.16 mm) bonded to the back of the face. Single-layer stack — the original two-layer spec (film + 3.2 mm opal acrylic) was reduced to film-only on 2026-04-26 after bench testing showed the film alone provides adequate hot-spot suppression at the planned LED-to-film distance, and the opal acrylic introduced ~5 mm of lateral light bleed (its bead-scattered transmission spreads light laterally inside the 3.2 mm sheet). The two acrylic sheets ($37) are shelved as backup if hot spots emerge during full-clock first-light testing — the recovery design would be per-pocket acrylic cuts + light-channel walls extending through the acrylic level.

Dimensions: **7" × 7" face**, depth TBD during build (probably 1-1.5" to fit PCB + speaker + light channels).

## Letter Grid

13 columns × 13 rows. Dense QLOCKTWO style, same density as Chelsea's clock. 12 filler letters spell a hidden acrostic (name + birthdate).

### Emory's grid (reference — lit example: IT IS TWENTY PAST THREE IN THE AFTERNOON)

```
I T E I S M T E N H A L F       ← IT, IS, TEN, HALF · fillers: E, M
Q U A R T E R T W E N T Y       ← QUARTER, TWENTY
F I V E O M I N U T E S R       ← FIVE-min, MINUTES · fillers: O, R
Y H A P P Y P A S T T O 1       ← HAPPY, PAST, TO · fillers: Y, 1
O N E B I R T H T H R E E       ← ONE, BIRTH, THREE
E L E V E N F O U R D A Y       ← ELEVEN, FOUR, DAY
T W O E I G H T S E V E N       ← TWO, EIGHT, SEVEN
N I N E S I X T W E L V E       ← NINE, SIX, TWELVE
E M O R Y 0 A T F I V E 6       ← EMORY, AT, FIVE-hr · fillers: 0, 6
T E N O C L O C K N O O N       ← TEN-hr, OCLOCK, NOON
2 I N T H E M O R N I N G       ← IN, THE, MORNING · filler: 2
A F T E R N O O N 0 A T 2       ← AFTERNOON, AT · fillers: 0, 2
E V E N I N G 3 N I G H T       ← EVENING, NIGHT · filler: 3
```

Filler letters read in order: `E M O R Y 1 0 6 2 0 2 3` = **EMORY 10/6/2023**.

### Nora's grid

Identical to Emory's except row 9. NORA is 4 letters (vs EMORY's 5), so row 9 has one extra filler cell. Nora's grid therefore has 13 filler cells total (vs Emory's 12), and the acrostic is one char longer.

```
N O R A R 1 A T F I V E 9       ← NORA, AT, FIVE-hr · fillers: R, 1, 9
```

Filler letters in reading order across the full grid: `N O R A M A R 1 9 2 0 2 5` = **NORA MAR 19 2025** (13 chars).

### Word inventory (24 clock words + 4 birthday + 12 fillers)

Time-tellers: IT, IS, FIVE-min, TEN-min, QUARTER, TWENTY, HALF, MINUTES, PAST, TO, ONE, TWO, THREE, FOUR, FIVE-hr, SIX, SEVEN, EIGHT, NINE, TEN-hr, ELEVEN, TWELVE, OCLOCK, NOON, IN, THE, AT, MORNING, AFTERNOON, EVENING, NIGHT.

Birthday message: HAPPY, BIRTH, DAY, NAME. Woven across rows 4, 5, 6, 9.

Time phrasing uses "IT IS [minutes] PAST/TO [hour] IN THE MORNING/AFTERNOON/EVENING / AT NIGHT". The period suffix describes the **announced** hour, not the current one: in "TO" phrasing the suffix follows the upcoming hour (11:40 AM → "TO TWELVE NOON", 4:40 PM → "TO FIVE IN THE EVENING", 8:40 PM → "TO NINE AT NIGHT", 11:40 PM → "TO TWELVE AT NIGHT"). Special case: "IT IS TWELVE NOON" at 12:00 PM; midnight uses "IT IS TWELVE AT NIGHT".

## Firmware Behaviors

### Clock face

- **Default everyday color:** warm white. Same for both clocks.
- **Update cadence:** words refresh every 5 minutes (same as Chelsea's). Rounding is floor, matches QLOCKTWO convention.

### Bedtime dim

- **Trigger:** local time between 7:00 PM and 8:00 AM.
- **Behavior:** LEDs drop to ~10% brightness. Clock stays on, still shows time. No words blank out.

### Birthday mode

- **Trigger:** on the kid's birthday (Oct 6 for Emory, Mar 19 for Nora), all day.
- **Behavior:** HAPPY + BIRTH + DAY + NAME light up in rainbow cycle alongside the time words.
- **Birth-minute easter egg:** at the exact birth time on birthday (6:10 PM for Emory, 9:17 AM for Nora), plays Dad's voice memo through the speaker once.

### Holiday modes

Single-day color shifts. Clock displays time normally, but word colors use the holiday palette instead of warm white.

| Holiday | Date | Palette |
|---|---|---|
| MLK Day | 3rd Monday of January | purple |
| Valentine's Day | Feb 14 | red/pink |
| International Women's Day | Mar 8 | purple |
| Earth Day | Apr 22 | green/blue |
| Easter | computed (first Sunday after first full moon after Mar 21) | pastels |
| Juneteenth | Jun 19 | red/black/green (Pan-African) |
| Indigenous Peoples' Day | 2nd Monday of October | earth tones |
| Halloween | Oct 31 | orange/purple |
| Christmas | Dec 25 | red/green |

### Audio button

- **Button press:** plays the lullaby (pre-recorded by Dad) once, then stops.
- **Press during playback:** stops immediately.
- **Volume:** fixed in firmware, tuned by Dad during assembly. Not user-adjustable.

### Time sync

- **On WiFi:** NTP sync on boot and every 24 hours (±30 min jitter). Updates RTC.
- **No WiFi:** free-runs on DS3231. Drift is low (seconds per week) — acceptable.

## Per-Clock Configuration

Single source file (e.g., `config.h`) per clock selects the identity at compile time:

- Name string → drives row 9 letter layout
- Birthday month/day → drives birthday-mode trigger
- Birth time (hour:minute) → drives voice-memo trigger
- Acrostic string → drives filler-cell contents
- Wood species label → for the dedication engraving, no firmware impact

Same PCB, same firmware source, different compile-time flag.

## Delivery Timeline

- **Emory** — delivery window: around her 7th birthday, Oct 2030. Working backwards, prototype and iterate 2027-2029, lock design 2030.
- **Nora** — delivery window: around her 7th birthday, Mar 2032. Emory's clock is the prototype; Nora's is the second unit with any fixes baked in.

## Budget Estimate

Per clock:
- PCBA from JLCPCB (5 boards, since MOQ) — amortized ~$50 per clock
- Laser-cut wood face + frames — ~$40
- ESP32 module, speaker, microSD, buttons, USB-C — ~$30
- 3D-printed internals — ~$10 material
- Misc (paper diffuser, wire, glue, finish) — ~$20

**~$150-180 per clock**, not counting the 3D printer itself if you buy one.

## Open Items for Planning Phase

Deferred to `writing-plans` — not blocking the spec:

- KiCad schematic + layout details (pin budget, specific footprints, DRC)
- Firmware module breakdown (how time/color/animation/audio modules compose)
- Light-channel 3D model dimensions (wall thickness, depth, alignment to PCB LED pads)
- Laser-cut file format (SVG? DXF?) and vendor choice (SendCutSend vs Ponoko vs local)
- Audio file format/encoding, bitrate, SD card filesystem layout
- Captive portal UI design and WiFi credentials storage
- Testing strategy (unit tests for grid logic, hardware test sketches for audio/LEDs)

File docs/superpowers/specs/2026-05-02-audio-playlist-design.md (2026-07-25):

# Audio Playlist — Two-Lullaby Playback Design

**Status:** Design
**Author:** Sam
**Date:** 2026-05-02
**Supersedes / extends:** `docs/superpowers/specs/2026-04-18-audio-design.md`

## Summary

Replace single-file lullaby playback with a fixed two-file playlist
(`lullaby1.wav` → `lullaby2.wav`), played in sequence on a single Audio
button press. Birthday auto-fire (`birth.wav`) is preserved as a
separate single-file path with one behavior change: **birthday now
interrupts an in-progress lullaby** rather than being suppressed for the
year.

On the kid's birthday (month+day match, time synced at least once), the
Audio button plays `birth.wav` instead of the lullaby playlist — any
time that day. This routing (`PlayBirthdayRequested`, Idle-gated like
the lullaby request) is independent of the birth-minute auto-fire and
never touches the NVS year stamp, so button plays neither burn nor
block the 6:10 PM fire. With time never synced, the button falls back
to lullabies — an unsynced RTC must not false-fire on a garbage date.

## Motivation

The original audio design supported one button-triggered song. Sam's
bedtime routine for both daughters is a two-song sequence:

- **Lullaby 1** — "I Am Kind" by Raffi & Lindsay Munroe (shared across
  both clocks).
- **Lullaby 2** — per-kid: Emory gets "Three Little Birds", Nora gets
  "Take on Me".

A single button press should play both songs back to back, matching the
real bedtime routine. A second press at any point during playback stops
everything and returns to Idle.

## Behavior changes

Three decisions, captured here so future maintainers (or Sam in five
years swapping a CR2032 battery) understand the trade-offs:

### 1. Birthday interrupts lullaby (was: suppress)

The original design ran the birthday auto-fire guard only when the
state machine was `Idle`, so a lullaby playing at the exact birth
minute would suppress `birth.wav` for the entire year (NVS-gated to
once per year regardless). With lullaby playtime growing from ~3 min
to ~5-7 min in the new design, the suppression window also grows —
making "kid happens to be playing the lullaby at her birth minute"
increasingly likely.

New behavior: birthday auto-fire runs every tick regardless of state.
If the guard fires while a lullaby is playing, the lullaby is closed
and `birth.wav` opens immediately. After `birth.wav` ends, the state
machine returns to Idle (the lullaby does NOT resume — explicit
choice; resuming would require tracking position state).

### 2. Always restart from lullaby1 on press-after-stop

Stopping mid-playlist (e.g. kid fell asleep during lullaby2) and
pressing Audio again later **always restarts from lullaby1**, never
resumes from the stopped position.

Rejected: tracking last-played position across stops. Adds NVS writes
or RAM-only state, more code paths in the state machine, and the user
experience of "sometimes it picks up mid-song" is jarring without
clear visual feedback.

### 3. Missing files: log error, transition to Idle

If `lullaby1.wav` is missing on a press, OR `lullaby2.wav` is missing
when the playlist tries to advance from lullaby1's EOF, the audio
module logs an error to serial and transitions to Idle. No fallback
to the other file, no backward-compat with old `lullaby.wav` filename.

Same defense as the current single-file design. SD card content is
verified at assembly time; missing files indicate a card prep error
that should be loud, not silent.

`birth.wav` missing at auto-fire is also a log-error-and-stay-Idle
case, with one important wrinkle: the NVS year stamp is written
**before** the file is opened. If NVS stamps but `birth.wav` is
missing, the year is recorded as fired and birth.wav will not retry
this year. This matches the original spec's intent — once the system
"decides" to fire, it doesn't double-up later in the year, even if
the actual playback failed.

## Architecture

The new design extracts a pure-logic playback state machine into a
testable header (`audio/playback.h`) and wires it into the ESP32
adapter (`audio.cpp`). This pattern matches `audio/fire_guard.h` —
keep firmware-platform-independent logic native-testable, keep
SD/I²S/NVS calls in the adapter.

### State + track tags

```cpp
namespace wc::audio {

enum class State : uint8_t { Idle, Playing };
enum class Track : uint8_t { None, LullabyOne, LullabyTwo, Birth };

}
```

`State` keeps the existing two-state shape. `Track` tags which file is
currently open during Playing — necessary so EOF handling can branch
(advance lullaby1 → lullaby2, vs. terminate at lullaby2 EOF, vs.
terminate at birth EOF without auto-resume).

When `State == Idle`, `Track == None`. Otherwise `Track` matches the
file open in `current_file_`.

### Playback state machine

Pure-logic functions in `audio/playback.h`:

```cpp
struct PlaybackEvent {
    enum class Kind {
        PlayLullabyRequested,
        StopRequested,
        FileEnded,
        BirthdayFired,
    } kind;
};

struct PlaybackTransition {
    enum class Action {
        None,                 // no-op
        OpenFile,             // open path, start I²S
        CloseFile,            // stop I²S, close current file
        SwitchFile,           // close current, open new path
    } action;
    const char* path;         // valid when action is OpenFile / SwitchFile
    State next_state;
    Track next_track;
};

PlaybackTransition next_transition(State, Track, PlaybackEvent);
```

Native tests cover the transition table:

| Current state | Event | Action | Next state | Next track |
|---|---|---|---|---|
| Idle | PlayLullabyRequested | OpenFile | Playing | LullabyOne |
| Playing/LullabyOne | FileEnded | SwitchFile | Playing | LullabyTwo |
| Playing/LullabyTwo | FileEnded | CloseFile | Idle | None |
| Playing/Birth | FileEnded | CloseFile | Idle | None |
| Playing/* | StopRequested | CloseFile | Idle | None |
| Idle | StopRequested | None | Idle | None |
| Playing/* | PlayLullabyRequested | None | (unchanged)| (unchanged) |
| Idle | BirthdayFired | OpenFile | Playing | Birth |
| Playing/* | BirthdayFired | SwitchFile | Playing | Birth |

Note: `Playing/Birth + BirthdayFired` returns `SwitchFile` to re-open
`birth.wav` from the start. The NVS year-stamp gate ensures the
auto-fire guard doesn't return true a second time within the same
calendar year, so this row is unreachable in practice; the SwitchFile
behavior is benign defense-in-depth.

### Adapter responsibilities (`audio.cpp`)

The ESP32 adapter:

1. Calls `next_transition(state_, track_, event)` per relevant tick or
   button event.
2. Executes the returned `Action` via SD / I²S calls.
3. Updates `state_` and `track_` from the returned values.

The auto-fire guard runs every tick (not just when Idle). If the
guard fires:

- Pass `BirthdayFired` to `next_transition`.
- Stamp NVS year **before** executing OpenFile/SwitchFile (preserves
  fire-once semantics across power loss).

The button press handler in `main.cpp` calls `audio::play()` and
`audio::stop()`. `play()` routes internally: `PlayBirthdayRequested`
when `is_birthday()` (fire_guard) says today is the birthday and time
is known, `PlayLullabyRequested` otherwise.

## SD card content

Each kid's SD card holds three WAV files at the root, all 16-bit PCM
44.1 kHz mono little-endian:

| File | Emory | Nora |
|---|---|---|
| `/lullaby1.wav` | "I Am Kind" | "I Am Kind" |
| `/lullaby2.wav` | "Three Little Birds" | "Take on Me" |
| `/birth.wav` | birth-minute voice memo | birth-minute voice memo |

The old `/lullaby.wav` filename is **deprecated** and will not be
read by the new firmware. SD card prep procedure (in
`docs/hardware/assembly-plan.md` parallel-tracks) updates accordingly.

Per-clock total ~25-30 MB across all three files. Any microSD ≥1 GB
suffices; class 10 or better recommended for read latency margin.

## Public API

The audio module's external API is unchanged in shape:

```cpp
void begin(const BirthConfig& birth);
void loop();
void play_lullaby();   // semantics: starts the 2-song playlist
void stop();           // semantics: stops everything, no resume
bool is_playing();
```

Only `play_lullaby()`'s semantics change (it now starts a playlist
rather than a single file). `main.cpp` and the buttons / wifi_provision
modules require no changes.

## Failure handling

| Condition | Behavior | Log line |
|---|---|---|
| `lullaby1.wav` missing on press | Stay Idle | `[audio] error: file /lullaby1.wav not found` |
| `lullaby2.wav` missing after lullaby1 EOF | Transition to Idle | `[audio] error: file /lullaby2.wav not found` |
| `birth.wav` missing on auto-fire | Transition to Idle; NVS stamp persists; no retry this year | `[audio] error: file /birth.wav not found` |
| Any file's WAV header invalid | Transition to Idle | Existing `parse_wav_header` error code logged |
| `i2s_write` returns non-OK error | Dispatched as FileEnded (graceful degrade): on lullaby1 advances to lullaby2; on lullaby2 / birth.wav transitions to Idle | Existing `[audio] error: i2s_write err=...` line |
| SD card removed mid-playback | `current_file_.read` returns ≤0 → treated as EOF → transitions per state machine | Existing `finished` log line |

## Test plan

### New: `firmware/test/test_audio_playback/`

Native Unity tests of the pure-logic `next_transition()` function. One
test case per row of the transition table above. ~12-15 individual
assertions.

### Updated: `firmware/test/test_audio_fire_guard/`

No logic changes to the guard itself. Add coverage that confirms the
guard returns `true` independent of `already_playing` value when:
- Year not yet recorded
- Time is known
- Minute matches

This documents the new "interrupt during playing" intent.

### Hardware checks: `firmware/test/hardware_checks/audio_checks.md`

Add manual test steps:

1. **Playlist progression** — press Audio at Idle. Verify lullaby1
   plays, then lullaby2 plays automatically without further input,
   then state returns to Idle (silence).
2. **Stop during lullaby1** — press Audio during lullaby1 → silence
   immediately. Press again → restart from lullaby1, NOT lullaby2.
3. **Stop during lullaby2** — press Audio during lullaby2 → silence
   immediately. Press again → restart from lullaby1.
4. **Birthday interrupt** — set RTC to birthday minute via temporary
   firmware bypass, press Audio, wait for lullaby to start, then
   advance RTC by 1 second past the birth minute. Verify lullaby
   stops and `birth.wav` plays. After birth.wav ends, lullaby does
   NOT resume.

## Migration notes for in-progress build

Sam's current build (Emory and Nora's clocks, frames glued, faces
glued, light channels printed, PCBs in JLCPCB transit as of 2026-05-02)
is unaffected by this firmware change at the hardware level. Changes
required:

1. Rename / re-record audio assets on each kid's SD card to use the
   new file names.
2. Re-flash both clocks once new firmware is on `main`. Flash happens
   anyway during PCB bench-bring-up, so this is a single re-flash, not
   an extra step.
3. Update `firmware/test-sketches/` is NOT required — the playlist
   logic lives in `firmware/lib/audio/`, not in the test sketches.

## Risks

- **Lullaby2 missing scenario** is more likely than missing-lullaby in
  the original design (more files, more places to mess up SD prep).
  Mitigation: documented log line, hardware-checks step that catches
  it during initial bench bring-up.
- **Birthday-interrupts behavior** is a behavior change vs. the
  original spec. Documented above; the `should_auto_fire` guard's
  `already_playing` parameter is no longer used by the audio module
  (always called with `false`), but the parameter is preserved in the
  pure-logic API for future extensibility.
- **NVS stamp racing with file open** — if NVS write succeeds but the
  filesystem operation to open `birth.wav` fails, the year is
  recorded fired without playback. Documented as intentional in
  Failure Handling above. This matches existing single-file behavior.

## Out of scope

- **Per-song volume control.** Volume is fixed at compile-time per
  `CLOCK_AUDIO_GAIN_Q8`. If lullaby1 and lullaby2 have different
  loudness, the user normalizes them at the audio-prep step before
  copying to SD. Firmware does not normalize.
- **More than two songs.** Playlist is hard-coded at exactly two
  files. Generalizing would require SD-directory enumeration or a
  manifest file; both add complexity without current demand.
- **Crossfade / gap timing between lullaby1 and lullaby2.** The
  transition is whatever the SD/I²S latency happens to be (sub-100ms
  in practice). No designed silence period.
- **Resuming on power-on if power was lost mid-lullaby.** Power-on
  always starts in Idle state; no replay of in-progress lullaby.

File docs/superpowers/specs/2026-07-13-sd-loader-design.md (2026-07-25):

# SD Loader — Design

Load or update the firmware-expected audio files (`lullaby1.wav`,
`lullaby2.wav`, `birth.wav`) on the SD card inside a **closed** clock,
through the captive USB cable, then restore the clock to exactly the
firmware it was running. No screws.

Motivation: the clocks are sealed for years at a time, but the audio
content is meant to be re-recordable up to delivery (2030/2032) and beyond.
The SD card is wired to the ESP32; the ESP32 is reachable over the captive
cable; therefore SD contents are cable-serviceable — this tool makes that a
one-command operation for the next 40 years. Immediate driver: Emory's
clock is live and `birth.wav` must be real before her birthday (Oct 6).

## Locked decisions (2026-07-13, with user)

| Decision | Choice |
|---|---|
| Firmware restore | **Dump & restore**: read the full 4 MB flash image before touching anything; write it back byte-identical afterwards. No toolchain, keychain flags, or git state needed at restore time — works in 2035. |
| Input handling | **Auto-convert**: accept raw recordings in any format `afconvert` reads (Voice Memos `.m4a`, MP3, …); tool converts to spec WAV and validates. |
| UX | **One command**: stage → backup → load → restore → boot-check, fully narrated, walk-away. |
| Transfer | **WiFi pull**: loader firmware joins the home WiFi and HTTP-GETs files from a temporary server on the Mac (~1–3 MB/s, TCP integrity). Serial is the control + progress channel only. Serial *transfer* rejected: 30+ min at 115200 through a clone CP2102 with a known replay bug. |

## Components

### 1. Loader firmware — `firmware/tools/sd_loader/`

Standalone PlatformIO project (the test-sketch pattern, but under `tools/`
because it is a permanent lifecycle tool). Pins `espressif32@6.8.0` and the
`build_unflags = -std=gnu++11` line exactly like the main env (both are
load-bearing; see CLAUDE.md), and uses the same default 4 MB partition
table so the NVS partition sits at the same offset — the loader reads the
clock's stored WiFi credentials from the `wifi` namespace directly
(`ssid`/`pw` keys, same schema as `nvs_store.cpp`). The loader never
writes NVS.

Boot sequence: mount SD (same SPI pins as the audio adapter — source them
from `pinmap.h` by including the main project's core include dir), join
WiFi from NVS creds if present, then print `READY sd=<ok|fail>
wifi=<ip|none|failed>` and serve line-based serial commands at 115200.
The host sends `W` iff `wifi` is not an IP:

| Command | Effect | Responses |
|---|---|---|
| `W <ssid>\t<pass>` | Join WiFi with explicit creds (unprovisioned board, e.g. Nora at bring-up). Tab-separated — passwords may contain spaces. | `OK wifi <ip>` / `ERR wifi <reason>` |
| `G <url>\t<name>\t<size>\t<crc32>` | Stream-download `url` to `/<name>.part` on the SD, computing CRC32 while writing; then re-read the file from the card and re-CRC; on match, delete any existing `/<name>` and rename `.part` over it. | `PROG <name> <pct>` every ~5%, then `OK got <name> <size> <crc32>` / `ERR get <reason>` |
| `L` | List SD root: name, size, CRC32 per file. | `FILE <name> <size> <crc32>` ×N, then `OK list` |
| `D <name>` | Delete a file (stale test audio, orphaned `.part`). | `OK del <name>` / `ERR del <reason>` |

CRC32 is zlib polynomial on both sides (small table implementation in the
loader; `zlib.crc32` on the host). All output is human-readable — the tool
parses it, a human can read it.

### 2. Host orchestrator — `firmware/tools/sd_load.py`

The one command:

```
python3 tools/sd_load.py --lullaby1 A.m4a --lullaby2 B.m4a --birth C.m4a
python3 tools/sd_load.py ~/recordings/emory/     # dir: files named lullaby1.*, lullaby2.*,
                                                 # birth.* — whichever are present (≥1 required)
python3 tools/sd_load.py --dry-run               # pipeline proof, no real slots touched
python3 tools/sd_load.py --restore-only <backup> # recover a clock left in loader state
```

Steps, each narrated and each a hard gate:

1. **Stage** — `afconvert -f WAVE -d LEI16@44100 -c 1` each input into a
   staging dir; **canonicalize** the result to the 44-byte-header layout
   (afconvert inserts a `FLLR` padding chunk between `fmt ` and `data`,
   which the firmware's strict parser in `lib/audio/src/wav.cpp` rejects
   as `BadDataMagic` — the 2026-07-25 silent-lullaby bug); then validate
   exactly as strictly as the firmware parser (RIFF/WAVE, PCM, mono,
   44100 Hz, 16-bit, `data` at offset 36); compute CRC32 + size. Any
   problem aborts here, before the clock is touched. Partial sets are
   allowed (update only `birth.wav`) — unspecified slots are left alone
   on the card.
2. **Backup** — `esptool read_flash 0 0x400000` to
   `tools/.flash_backups/<UTC-timestamp>.bin` (directory gitignored;
   backups never auto-deleted). Baud 921600, falling back 460800 → 115200
   on failure (clone CP2102).
3. **Load** — flash the loader (`pio run -d tools/sd_loader -t upload`),
   start `http.server` on the staging dir bound to the Mac's LAN IP on an
   ephemeral port, open serial with the replay-safe recipe (reset-hold →
   flush → release), wait for `READY`, send `W` if the loader reports no
   NVS creds, then one `G` per file; verify every `OK got` CRC. Finish
   with `L` and print the card's final contents. `--dry-run` instead
   transfers a generated 100 KB test WAV to `dryrun.tmp` and `D`s it.
4. **Restore** — `esptool write_flash 0x0 <backup>` (esptool 4.x reads
   back and verifies written data itself; the old `--verify` flag is
   superfluous), reset, then
   reuse the boot-capture pattern to confirm health markers (boot banner,
   setup-complete, no RTC error; a rendered frame or WiFi-Online line ends
   the capture early when visible but is not required). Only then declare
   success. The backup image itself is verified (exact flash size + ESP32
   bootloader magic at 0x1000) before anything is flashed over the
   original.

Failure posture: once the loader has been flashed, any error triggers an
automatic restore attempt (finally-block semantics). If even that fails,
the tool prints the exact `--restore-only` command with the backup path.
The clock is never silently left as a loader.

### 3. Audible verification (separate, post-restore)

The Audio button already plays `lullaby1.wav` — that is the human check
for the lullabies. For `birth.wav`, add a `'b'` serial command to the
existing TEMP bench-sim block in `main.cpp` that plays the birthday file
on demand. It lives and dies with the other TEMP commands (stripped before
production). CRC equality remains the formal proof; ears are the comfort.

## Error handling summary

| Failure | Behavior |
|---|---|
| Bad/missing input audio, afconvert error | Abort in step 1; clock untouched |
| read_flash fails at all baud rates | Abort; clock untouched (still running its firmware) |
| Loader can't join WiFi | Reported over serial; tool restores flash and exits nonzero |
| Download CRC mismatch | Retry ×3, then restore + fail |
| Power loss mid-transfer | Only `.part` on card; existing files intact. The final swap (remove + rename — FAT can't overwrite-rename) has a millisecond window that can leave a slot empty; re-run the load to fill it |
| Restore write fails | Retry at lower baud; if exhausted, print `--restore-only` recovery instructions |
| Post-restore boot check fails | Exit nonzero with the backup path and capture transcript; flash image is still on disk |

## Testing

- **pytest** (`firmware/tools/test_sd_load_core.py`, following the repo's
  existing pytest precedents): WAV header validation, CRC/staging, serial
  response parsing, command formatting — the pure-logic half of the host
  tool, structured so it imports without pyserial/esptool present.
- **Loader firmware**: compiles standalone; verified live via `--dry-run`
  against Emory's clock — that run is the acceptance test for the whole
  pipeline and is also the moment we finally list what is on Emory's card.
- **First real use**: Emory's actual recordings, before Oct 6.

## Out of scope

- Serial file transfer fallback (WiFi is a hard prerequisite; a clock
  without WiFi in reach gets `W`-supplied credentials to any AP/hotspot).
- Reading files *off* the card (add a `P <name>` dump command later if a
  need ever appears).
- Any GUI. One command, one transcript.

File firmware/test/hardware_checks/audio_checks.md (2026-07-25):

# Audio Module — Manual Hardware Checks

These checks exercise the ESP32 paths that the native test suite
cannot reach: real I²S DMA + MAX98357A + speaker output, real SD
card open / read / close via VSPI, real `Preferences`/NVS round-trip
for `last_birth_year`, real `rtc::now()` for the auto-fire guard.
Run during breadboard bring-up after the MAX98357A + microSD paths
have been wired (`docs/hardware/breadboard-bring-up-guide.md`
§MAX98357A + Speaker and §MicroSD) and the ntp
(`ntp_checks.md`) and rtc (`rtc_checks.md`) checklists are green.

Spec: `docs/superpowers/specs/2026-04-18-audio-design.md`.

## Prerequisites

- ESP32 flashed with the current emory or nora env build.
- Captive-portal flow completed at least once (NVS holds valid
  WiFi creds + TZ; `seconds_since_last_sync()` is non-UINT32_MAX).
- MicroSD prepared with canonical WAV files at the card root:
  - `/lullaby1.wav` — 44.1 kHz / 16-bit / mono / PCM, ~3 min.
    (Originally `/lullaby.wav`; renamed for the 2026-05-02 playlist refactor.)
  - `/lullaby2.wav` — same format, ~3 min (added by the 2026-05-02 playlist).
  - `/birth.wav`   — same format, ~30 s.
  - Authoring recipe: Audacity > File > Export > Export as WAV;
    Encoding = "Signed 16-bit PCM", Sample Rate = 44100 Hz,
    Channels = Mono.
- MAX98357A hardware gain jumper set at the assembly default
  (9 dB unless bench measurement says otherwise).
- `CLOCK_AUDIO_GAIN_Q8` left at the default 256 for the first
  bring-up pass.
- Speaker connected to MAX98357A output terminals.
- Serial monitor open at 115200 baud.

## Checks

1. **Boot path observable.** Power on. Expect
   `[audio] begin: SD ok, I2S ok` in serial. If `SD FAILED`
   appears, re-seat the card and re-check VSPI wiring per
   `docs/hardware/pinout.md`.

2. **Lullaby play.** Once the clock is Online, press the audio
   button. Expect `[audio] play /lullaby1.wav` in serial (now
   `lullaby1.wav` after the 2026-05-02 playlist refactor), followed
   by audible playback through the speaker. Wait for natural EOF;
   expect `[audio] finished (played <N> bytes)` within ~3 min.
   Confirm the clock display continues rendering the current time
   during playback (display cadence is independent of audio). For
   playlist progression behavior (lullaby1 → lullaby2 auto-advance),
   see check P1.

3. **Button-during-playback stops.** Start lullaby. After ~10 s,
   press the audio button again. Expect `[audio] stopped (played
   <N> bytes)` in serial and immediate silence from the speaker.
   Press once more; expect fresh playback from the start.

4. **Volume sanity.** Listen for distortion / clipping on the
   loudest passages. If present: either re-encode the WAV at
   lower peak level (authoring fix), or lower `CLOCK_AUDIO_GAIN_Q8`
   to 181 (−3 dB) / 128 (−6 dB) via `configs/config_<kid>.h` and
   rebuild. Hardware jumper change (lower-gain resistor on
   MAX98357A) is the alternative if software trim isn't enough.
   Document the setting that worked in `docs/hardware/assembly-plan.md`.

5. **SD card removed mid-playback.** Start lullaby. Pull the
   microSD card from the slot. Expect either
   `[audio] error: i2s_write err=...` OR
   `[audio] aborted (played <N> bytes)` in serial, followed by
   silence. Re-seat the card; press the button again → plays
   successfully (no reboot needed).

6. **Missing file graceful.** Rename `/lullaby1.wav` →
   `/xxx.wav` on the card, re-insert. Press audio button. Expect
   `[audio] error: file /lullaby1.wav not found`; no sound. Stay
   Idle. (Originally `/lullaby.wav`; renamed for the 2026-05-02
   playlist refactor.)

7. **Invalid WAV graceful.** Place a stereo 48 kHz WAV (or a
   renamed .mp3) at `/lullaby1.wav`. Press audio button. Expect
   `[audio] error: wav header invalid (code=<N>)`; no sound.
   (Originally `/lullaby.wav`; renamed for the 2026-05-02 playlist
   refactor.)

8. **Birth auto-fire (simulated).** Pre-set the DS3231 via a
   bring-up sketch to 6:09:50 PM on Oct 6 of the current year
   (adjust month/day/time for the active env's `CLOCK_BIRTH_*`).
   Reset `audio/last_birth_year` to 0 via a wipe sketch OR by
   flashing a one-shot debug build that calls `Preferences::clear()`
   on the `"audio"` namespace at boot. Wait through 6:10:00 PM.
   Expect `[audio] play birth.wav (year=<current year>)` within
   one `loop()` tick of the minute roll. Confirm audible playback;
   wait for `[audio] finished`.

9. **Birth auto-fire fires once per year.** After check 8 passes,
   stay powered and wait until the next minute (6:11 PM). Expect
   no additional `[audio] play` log. Power-cycle. Expect no
   `[audio] play birth.wav` on next boot (NVS `last_birth_year`
   now matches the current year).

10. **Unknown-time gate.** Wipe NVS (hold Hour + Audio 10 s →
    `reset_to_captive`). Captive portal comes up; do NOT submit
    credentials. Pre-set the DS3231 to 6:10 PM on Oct 6 via the
    bring-up sketch. Verify no auto-fire — `time_known` is false
    because `seconds_since_last_sync()` reads UINT32_MAX. No
    `[audio] play birth.wav` log should appear.

11. **Birthday button routing.** With the DS3231 pre-set to any
    daytime hour on the birthday (e.g. 9:00 AM Oct 6) and time
    synced, press the Audio button. Expect
    `[audio] birthday today — button plays birth.wav` then
    `[audio] play /birth.wav` — NOT lullaby1. Confirm the 6:10 PM
    auto-fire still occurs later that day (button plays do not
    stamp `last_birth_year`). On any other date the button must
    play `/lullaby1.wav` as in check 2.

11. **ntp deferral during playback.** Start lullaby playback. In
    serial, confirm no `[ntp] sync ok` / `[ntp] forceUpdate()`
    log lines fire during the ~3 min playback window, even if a
    deadline would otherwise fire. After the lullaby finishes,
    confirm ntp resumes its normal cadence.

12. **Underrun sanity.** During playback, stress the main loop by
    adding a temporary `Serial.println(millis());` every loop tick.
    Playback should remain clean. Audible glitches here would
    point to DMA ring sizing being too tight — rare at
    4 × 1024 buffers (~93 ms of audio).

## Pass criteria

Checks 1–7, 11, and P1–P5 must pass before considering the module
hardware-verified. P1–P5 are required (not optional) since the
2026-05-02 playlist + birthday-interrupts refactor changed the
module's runtime behavior. 8–10 require a controlled pre-set DS3231
and may be deferred until a real birthday during burn-in. 12 is
diagnostic-only.

## Playlist + birthday-interrupts checks (added 2026-05-02)

These checks supersede the original single-file lullaby check from the
2026-04-18 audio spec. Run them once on each clock during bench
bring-up, and again after any audio-module firmware change.

### Check P1 — Playlist progression
1. Idle clock, SD card present with `lullaby1.wav`, `lullaby2.wav`,
   `birth.wav` at root.
2. Press the **Audio** button (SW2).
3. Verify `lullaby1.wav` starts playing audibly.
4. Wait for `lullaby1.wav` to end without pressing anything.
5. Verify `lullaby2.wav` starts playing automatically (no input required)
   within ~1 second of `lullaby1.wav` ending.
6. Wait for `lullaby2.wav` to end.
7. Verify the clock returns to silence (Idle) — no further audio.

### Check P2 — Stop during lullaby1 + restart
1. Press **Audio** to start the playlist.
2. While `lullaby1.wav` is playing, press **Audio** again.
3. Verify audio stops immediately.
4. Press **Audio** again.
5. Verify `lullaby1.wav` starts playing **from the beginning**, NOT
   `lullaby2.wav`. (Always-restart-from-lullaby1, per spec design
   decision 2.)

### Check P3 — Stop during lullaby2 + restart
1. Press **Audio** to start the playlist; let `lullaby1.wav` finish.
2. While `lullaby2.wav` is playing, press **Audio**.
3. Verify audio stops immediately.
4. Press **Audio** again.
5. Verify `lullaby1.wav` (NOT `lullaby2.wav`) starts playing from the
   beginning.

### Check P4 — Birthday interrupts lullaby
1. Set the clock's RTC to 1 minute before the configured birth minute.
   (E.g. for Emory: set RTC to October 6, 18:09.) Use a temporary
   firmware bypass or `rtc::set(...)` from a serial-trigger debug build.
2. Press **Audio** to start the playlist.
3. While `lullaby1.wav` is playing, advance RTC to the birth minute
   (October 6, 18:10).
4. Verify within ~1 second: `lullaby1.wav` cuts off and `birth.wav`
   begins playing.
5. Wait for `birth.wav` to end.
6. Verify the clock returns to silence — `lullaby1.wav` does NOT resume
   automatically (per spec).
7. (Optional) Power-cycle the clock and verify that on the next tick at
   the birth minute, `birth.wav` does NOT play again — the NVS year
   stamp is honored across reboot.

### Check P5 — Missing lullaby2.wav graceful handling
1. Prepare a test SD card with `lullaby1.wav` and `birth.wav` only
   (no `lullaby2.wav`).
2. Insert into the clock, power on.
3. Press **Audio** to start the playlist.
4. Verify `lullaby1.wav` plays normally.
5. After `lullaby1.wav` ends, verify the clock returns to silence
   (Idle). Serial log should show `[audio] error: file /lullaby2.wav not found`.
6. The clock should NOT crash or hang. Subsequent presses of Audio
   should still attempt to start `lullaby1.wav`.

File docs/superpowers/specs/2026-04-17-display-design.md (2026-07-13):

# Display Firmware Module — Design Spec

Date: 2026-04-17

> **⚠ SUPERSEDED IN SPECIFICS — read with the 63-LED migration in mind.**
> This spec captures the original **35-LED**, **1.8 A**-capped design. The
> board and firmware have since moved on; the concepts here (renderer
> priority chain, holiday palette, birthday rainbow, amber stale-sync, dim
> multiplier) still hold, but these numbers do not:
> - **63 LEDs, not 35.** A word now maps to a `LedSpan{start,count}` (2–3
>   adjacent LEDs for long words), not one index. Source of truth:
>   `firmware/lib/display/src/led_map.cpp` + `include/display/rgb.h`
>   (`LED_COUNT = 63`).
> - **Runtime power cap is 1700 mA**, not 1.8 A —
>   `FastLED.setMaxPowerInVoltsAndMilliamps(5, 1700)` in `display.cpp`. The
>   `PALETTE_MAX_RGB_SUM = 700` figure is now a per-word color bound, not a
>   total-power guarantee (total current is the runtime cap's job).
> - **Amber stale-sync threshold is 48 h**, not 24 h —
>   `STALE_SYNC_THRESHOLD_S` in `include/display/renderer.h`.
>
> When in doubt, the code + its native tests are authoritative over this doc.

## Overview

The `display` module turns the running clock state into pixels on the
35-LED WS2812B strip. It's the only firmware module that touches the
LED chain. Given time-of-day, date, a monotonic millisecond counter,
and the seconds-since-last-NTP-sync value from `wifi_provision`, it
produces the exact RGB value for every LED — including the holiday
palette shift, birthday rainbow cycle on the four decor words, amber
tint when the clock hasn't synced in 24 h, and the bedtime dim
multiplier. The pure-logic renderer composes cleanly with the Phase 1
modules (`time_to_words`, `holidays`, `birthday`, `dim_schedule`);
the ESP32 adapter is a thin FastLED wrapper.

Parent spec: `docs/superpowers/specs/2026-04-14-daughters-clocks-design.md`
(display listed as the first Phase 2 firmware module in TODO.md §Phase 2).

## Scope

**In:**
- Pure-logic `renderer::render(input) → Frame` that returns the final
  35-entry RGB array (dim multiplier already applied; caller writes
  it verbatim to the strip)
- `wc::display::begin()` + `wc::display::show(frame)` FastLED adapter
  (WS2812B on `PIN_LED_DATA` = GPIO 13 via 74HCT245 level shifter)
- `WordId → LED-chain-index` mapping table matching
  `hardware/word-clock-all-pos.csv`
- Palette lookup `(Palette, WordId) → Rgb` for all 10 palettes
  (warm white + 9 holiday palettes from `holidays.h`)
- Birthday-rainbow hue generator
  `(WordId, now_ms) → Rgb` for the 4 decor words
- Amber stale-sync color + `>24 h since last sync` threshold
- Dim multiplier applied inside the renderer (not via
  `FastLED.setBrightness`) so the renderer's output is the final,
  complete frame
- Native-testable pure-logic modules with Unity tests
- `#ifdef ARDUINO` guard on the FastLED adapter (same pattern as
  wifi_provision and buttons adapters — PlatformIO LDF otherwise
  pulls library sources into the native build)

**Out:**
- Deciding *whether* to call `render()` in a given frame — `main.cpp`
  owns the state-machine call for captive-portal / pre-sync boot
  (display just renders whatever it's told)
- RTC reads — `rtc` module owns DS3231 access; display consumes the
  date/time values it's handed
- NTP sync + tracking `seconds_since_last_sync()` — `wifi_provision`
  already exposes this
- Word-set computation — `wc::time_to_words()` (Phase 1) already
  returns the set of `WordId`s to light
- Holiday date detection — `wc::palette_for_date()` (Phase 1)
- Birthday detection — `wc::birthday_state()` (Phase 1)
- Brightness schedule — `wc::brightness()` (Phase 1)
- Voice-memo playback at the birth minute — `audio` module's job
- Any per-LED gamma, color-temperature correction, or FastLED power
  management — tunable during bring-up without changing this spec
- User-tunable palettes, weather-driven colors, scrolling-text modes
  — explicitly out (parent spec doesn't define them)

## Behavioral Contract

### Per-LED color precedence

Given inputs `(year, month, day, hour, minute, now_ms,
seconds_since_sync, birthday_cfg)`, for each `WordId w` the final LED
color is:

```
lit_set = time_to_words(hour, minute).words[0 .. count-1]
bday    = birthday_state(month, day, hour, minute, birthday_cfg)
palette = palette_for_date(year, month, day)
stale   = (seconds_since_sync > 86'400)  // UINT32_MAX also satisfies this

if bday.is_birthday:
    lit_set += {HAPPY, BIRTH, DAY, NAME}

if w not in lit_set:
    color = BLACK                                         // {0, 0, 0}
elif bday.is_birthday and w in {HAPPY, BIRTH, DAY, NAME}:
    color = rainbow(w, now_ms)                            // priority 1
elif palette != Palette::WARM_WHITE:
    color = color_for(palette, w)                         // priority 2
elif stale:
    color = AMBER = {255, 120, 30}                        // priority 3
else:
    color = WARM_WHITE = {255, 170, 100}                  // priority 4

color = color * brightness(hour, minute)                  // dim last
```

Priority from most-to-least important, locked during brainstorming:
**birthday rainbow (decor only) > holiday palette > amber stale-sync
> warm white**. Amber is a deliberate "don't fully trust the time"
signal; holidays and birthdays are celebration displays, so amber
yields to them.

### Rainbow

For `w ∈ {HAPPY, BIRTH, DAY, NAME}`:

- Phase offsets: `HAPPY=0°, BIRTH=90°, DAY=180°, NAME=270°`
- Hue: `hue_deg = ((now_ms % RAINBOW_PERIOD_MS) * 360 / RAINBOW_PERIOD_MS + phase_offset_deg) % 360`.
  Taking `now_ms % RAINBOW_PERIOD_MS` **before** the multiply keeps
  the intermediate product under `60'000 * 360 = 21'600'000`, well
  within `uint32_t` range. The naive form
  `now_ms * 360 / RAINBOW_PERIOD_MS` overflows `uint32_t` every
  `UINT32_MAX / 360 ≈ 3.3 hours` and produces a visible hue jump at
  each overflow boundary — unacceptable for a 60 s rainbow that
  must run for days.
- Output: standard HSV→RGB conversion at `sat=255, val=255`, done
  in a pure-C++ helper (`display::detail::hsv_to_rgb`) compiled
  into both the native and ESP32 builds. **Not** FastLED's
  `hsv2rgb_rainbow` — that variant has a custom non-linear hue
  distribution and would produce different colors than the native
  tests assert. Using a single HSV→RGB implementation across both
  environments keeps the renderer's behavior testable and
  deterministic; FastLED in the adapter is used only for pushing
  RGB bytes to the strip.
- `RAINBOW_PERIOD_MS = 60'000` — a full 360° cycle every 60 s.
- The `uint32_t now_ms` argument is allowed to wrap. Rainbow math is
  pure modular arithmetic on `now_ms`, so the hue increment across
  the wrap boundary is correct.
- **Full saturation and value** are returned pre-dim. The dim
  multiplier (step 7 of precedence) scales `val` afterward, producing
  dim-but-still-saturated rainbow at night.

### Birthday activation

- `birthday_state(...).is_birthday == true` for all 24 hours of the
  birthday date (midnight-to-midnight local, per parent spec).
- The birthday rainbow is active on decor words for that full window.
- `birthday_state(...).is_birth_minute == true` only at the exact
  birth hour:minute — not consumed by this module. The `audio`
  module uses it to trigger the voice-memo easter egg.

### Holiday palette cycling

`color_for(Palette p, WordId w)` is implemented as a `switch` over
named `Palette` enumerators — **not** as an array indexed by
`static_cast<uint8_t>(p)`. This keeps palette lookup robust against
`Palette` enum additions (a future `ST_PATRICKS` inserted between
existing values would silently break array-indexed lookup; the
switch form triggers `-Wswitch-enum` and forces the developer to
handle the new case).

Within a given palette, the word receives the color at:

```
color = palette_colors[static_cast<uint8_t>(w) % palette_colors.size()]
```

Cycling by `WordId` enum index (not by LED chain index) keeps the
palette lookup independent of PCB layout — the same palette logic
survives a PCB LED-reordering without test changes. Each word thus
receives a deterministic color within a given palette: on Halloween,
HAPPY (enum 31) gets `palette[31 % 2] = palette[1] = purple`; BIRTH
(enum 32) gets `palette[0] = orange`; etc.

### Palette power budget

Two-layer defense against palette-tuning drift blowing the PSU:

**Layer 1 — build-time check.** Every entry in every palette array
MUST satisfy `r + g + b ≤ PALETTE_MAX_RGB_SUM = 700`. Worst-case
current at this cap (all 35 LEDs lit to the sum cap simultaneously,
full brightness) is ≈ `35 × (700/765) × 60 mA ≈ 1.92 A`. The
existing defaults all fit well under 700 (max default entry is
`EASTER_PASTEL {255, 180, 200}` = 635). A
`test_palette_power_budget` Unity test enumerates every palette and
asserts the invariant on every entry, catching a bad palette tune
before it reaches the board.

**Layer 2 — runtime enforcement.** The adapter calls
`FastLED.setMaxPowerInVoltsAndMilliamps(5, 1800)` in
`display::begin()`. If the renderer ever emits a frame that would
pull more than 1.8 A on the strip, FastLED scales brightness down
automatically. This catches the "someone bumped the cap to 800 and
forgot to update the test" failure mode without damage.

The 1.8 A ceiling matches `docs/hardware/pinout.md` §Power budget
for the WS2812B strip alone, leaving headroom under the 2 A USB-C
cable rating for the ESP32 + RTC + amplifier + microSD draw.

Per-palette starting arrays (tunable on real hardware within the
sum-≤-450 constraint; the values below are defaults to commit with,
not final):

| Palette | RGB entries |
|---|---|
| `WARM_WHITE` | `[{255, 170, 100}]` |
| `MLK_PURPLE` | `[{128, 0, 180}]` |
| `VALENTINES` | `[{255, 30, 60}, {255, 120, 160}]` |
| `WOMEN_PURPLE` | `[{150, 50, 180}]` |
| `EARTH_DAY` | `[{30, 140, 60}, {30, 80, 200}]` |
| `EASTER_PASTEL` | `[{255, 180, 200}, {180, 220, 255}, {220, 255, 180}, {255, 230, 180}]` |
| `JUNETEENTH` | `[{200, 30, 30}, {10, 10, 10}, {30, 160, 60}]` |
| `INDIGENOUS` | `[{160, 80, 40}, {200, 140, 80}, {120, 60, 30}]` |
| `HALLOWEEN` | `[{255, 100, 0}, {140, 0, 180}]` |
| `CHRISTMAS` | `[{220, 30, 30}, {30, 160, 60}]` |

### Amber stale-sync

- Activation: `seconds_since_sync > 86'400` (strict >). `UINT32_MAX`
  (the "never synced this session" sentinel from
  `wifi_provision::seconds_since_last_sync()`) also satisfies this.
- Amber RGB: `{255, 120, 30}` (warm amber, ≈ 1800 K blackbody).
- Scope: amber replaces **warm white only**. On holiday days the
  palette wins; on birthday decor words the rainbow wins. This
  keeps amber from muddying celebration displays.
- Hysteresis: none. `seconds_since_sync` drops to 0 on a successful
  NTP, so the amber state exits on the very next render tick.

### Dim multiplier

Applied unconditionally as the last step per-LED. The renderer
derives an 8-bit multiplier from `wc::brightness(hour, minute)`:

```
const uint8_t bright_u8 = static_cast<uint8_t>(
    wc::brightness(hour, minute) * 255.0f + 0.5f);  // 26 or 255

r' = (r * bright_u8 + 127) / 255
g' = (g * bright_u8 + 127) / 255
b' = (b * bright_u8 + 127) / 255
```

`wc::brightness()` returns `0.1f` in the dim window (yielding
`bright_u8 = 26` — ≈ 10% of 255, with the half-step rounded up) and
`1.0f` otherwise (`bright_u8 = 255`). The per-channel formula is the
standard "multiply-by-8-bit, divide by 255, round-to-nearest" idiom:
`(x * a + 127) / 255`. Integer arithmetic keeps the render path
branch-light on ESP32, and the boundary behavior mirrors
`wc::brightness()` exactly: 18:59 is bright, 19:00 is dim, 07:59 is
dim, 08:00 is bright.

### Non-behaviors (explicit)

- **Stateless renderer.** `render()` is a pure function of its inputs.
  Rainbow animation emerges from `now_ms` changing, not from the
  renderer remembering the previous frame.
- **No transitions / fades** on word-set changes or day-boundary
  palette changes. The parent spec cadence is 5 minutes; hard-step
  matches QLOCKTWO tradition and Chelsea's clock.
- **No gamma correction** in v1. WS2812B + diffuser stack + dim
  multiplier already bend luminance; gamma is a bring-up tuning
  knob, not a spec requirement.
- **No color-temperature correction.** Face is hardwood; warm white
  on wood reads warm already.
- **No FastLED global brightness usage.** The renderer output is
  final. `show(frame)` memcpy's into FastLED's `CRGB[35]` and calls
  `FastLED.show()` — that's it.

## Architecture

Hexagonal. All color policy is pure logic, native-testable with Unity.
The ESP32 adapter is a thin FastLED wrapper.

```
firmware/lib/display/
  include/
    display.h                      public API (ESP32 only)
    display/
      rgb.h                        Rgb struct + Frame alias (header-only)
      led_map.h                    WordId → LED chain index (pure)
      palette.h                    Palette → Rgb lookup (pure)
      rainbow.h                    (WordId, now_ms) → Rgb (pure)
      renderer.h                   compose everything → Frame (pure)
  src/
    display.cpp                    FastLED adapter (#ifdef ARDUINO)
    led_map.cpp                    pure logic
    palette.cpp                    pure logic
    rainbow.cpp                    pure logic
    renderer.cpp                   pure logic
```

Tests:

```
firmware/test/
  test_display_led_map/test_led_map.cpp
  test_display_palette/test_palette.cpp
  test_display_rainbow/test_rainbow.cpp
  test_display_renderer/test_renderer.cpp
  test_display_renderer_golden/test_renderer_golden.cpp
```

Pure-logic `.cpp` files get added to `[env:native]`'s
`build_src_filter` in `platformio.ini`. `display.cpp` is guarded
with `#ifdef ARDUINO` — same reason wifi_provision's adapters are:
PlatformIO LDF's `deep+` mode pulls library sources into native
builds regardless of `build_src_filter`.
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

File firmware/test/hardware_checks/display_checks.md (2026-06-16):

<!-- firmware/test/hardware_checks/display_checks.md -->
# display — manual hardware verification

Run these after the full breadboard bring-up reaches
`docs/hardware/breadboard-bring-up-guide.md` §Step 9. Full WS2812B
chain (63 LEDs) on GPIO 13 through the 74HCT245 level shifter +
300 Ω series resistor + 1000 µF bulk cap.

Flash: `pio run -e emory -t upload`
Serial: `pio device monitor -e emory`

## 1. Boot + captive portal + blank face

- [ ] Serial shows `word-clock booting for target: EMORY`.
- [ ] Phone shows `WordClock-Setup-XXXX` AP. Face is all dark (no
      LEDs glowing) while in AP mode. Confirms main's
      `if state == Online` guard is in effect.
- [ ] Connect phone, submit valid WiFi creds via the form. State
      advances to Online per serial logs.

## 2. First light — warm-white clock face
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

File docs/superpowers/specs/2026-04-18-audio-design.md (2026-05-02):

# Audio Firmware Module — Design Spec

> **Note:** Single-file lullaby playback and the "birthday suppressed during lullaby" behavior described in this spec are superseded by [`2026-05-02-audio-playlist-design.md`](./2026-05-02-audio-playlist-design.md). The rest of this document (I²S setup, NVS stamping, gain control, file format) remains current.

Date: 2026-04-18
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

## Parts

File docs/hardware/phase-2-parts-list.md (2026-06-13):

# Phase 2 Parts List — Breadboard Bring-Up

> **⚠ HISTORICAL — completed breadboard buy-list (2026-04, all parts on hand).**
> Kept for reference. The production board is now 63 LEDs and the authoritative
> BOM lives in `hardware/fab/word-clock-bom.csv` (see `hardware/fab/README.md`
> for the as-built LED substitution). The roadmap table below is from April and
> is superseded by `TODO.md`.

**Gate:** Before Phase 2 of `docs/superpowers/plans/2026-04-14-daughters-clocks-implementation.md` can start. Phase 1 firmware logic is complete; this order unblocks hardware bring-up on a breadboard (no PCB yet).

**Budget:** ~$60-85 total for one breadboard kit. Only one set needed — Emory and Nora use the same hardware, differing only by compile-time config.

**Where we are in the roadmap:**

| Phase | Status |
|---|---|
| 0 — Repo + CI | ✅ Done |
| 1 — Native firmware logic | ✅ Done |
| **2 — Breadboard bring-up** | **← Blocked on this parts order** |
| 3 — KiCad PCB v1 | Needs Phase 2 learnings |
| 4 — Enclosure CAD | Needs PCB dimensions |
| 5 — Emory prototype | Needs PCB + enclosure |
| 6 — Nora unit | Needs Emory validated |

## Parts

### ESP32 DevKit V1 — **$8-12** × 1

- **What it is:** Small development board with an ESP32-WROOM-32 module, USB-to-serial chip (CP2102 or CH340), voltage regulator, and pin headers. Just plug into USB, flash firmware, go.
- **Why this clock needs it:** The ESP32 is the brain. It runs the firmware we built in Phase 1, drives the LEDs, talks WiFi for NTP time sync, plays audio over I2S, and reads button presses. Spec locks ESP32 because of the combination of WiFi + I2S audio + mature Arduino libraries.
- **What to look for:** Any variant with 30 or 38 pins, USB-C preferred (matches the final design). ESP32-WROOM-32E chip (the E is the 2020+ revision). Avoid ESP32-S2 / -S3 / -C3 variants for now — they have different pinouts and library quirks; stick with classic ESP32 to match the spec.
- **Sourcing:** Amazon Prime — "ESP32 DevKit V1 USB-C". Prime 2-day is worth the markup here.

### WS2812B LED strip, 1 meter @ 60 LEDs/m — **$8-12** × 1

- **What it is:** A flexible PCB strip with 60 addressable RGB LEDs per meter. Each LED has a tiny WS2812B controller chip built in; they chain together and you control them all over a single data line.
- **Why this clock needs it:** One LED per word group (~25 LEDs per clock). The letter grid sits behind a wood face with cut-through letters; each LED glows through one word's letters when that word is "on." WS2812B is the standard for this kind of project — FastLED library has good support, widely available, 5V-friendly.
- **What to look for:** 60 LEDs/m density (closest match to the word spacing on a 7" grid), IP30 (no waterproofing — unneeded indoors and takes up more space), 5V operation. Individually cuttable strip (scissors-friendly segments every 3 LEDs).
- **Why 1m when we only need 30:** You'll cut some, solder some wrong, and bring-up testing wants extras. $8 for a meter vs $6 for a cut length — not worth the hassle.
- **Sourcing:** Amazon — "WS2812B 60 LEDs/m 1m 5V strip". BTF-Lighting is a reliable brand.

### DS3231 RTC breakout board — ~~**$3-5** × 1~~ **Already owned**

> **Status:** Spare from Chelsea's clock restock (new 2-pack, one used for Chelsea, one spare). No need to order.

- **What it is:** A small module with the DS3231 real-time-clock chip, an AT24C32 EEPROM, a CR2032 battery holder, and I²C headers.
- **Why this clock needs it:** WiFi + NTP is the primary time source, but when WiFi is down (during setup, at grandma's house, after a router outage) the clock must keep ticking. The DS3231 is the industry's most accurate temperature-compensated crystal RTC — drifts only a few seconds per week. Spec calls it out explicitly as the offline fallback.
- **What to look for:** "DS3231 AT24C32" Chinese module. Comes with or without battery; buy a CR2032 separately if not included ($1 at any drugstore).
- **Sourcing:** Amazon Prime bulk packs (5 for $10 is common, cheaper per-unit — useful since you may break one).

### MAX98357A I²S amplifier breakout — **$6-10** × 1

- **What it is:** A small breakout with the MAX98357A — a 3.2W Class D audio amplifier with an I²S digital input and analog speaker output. Takes digital audio directly from the ESP32 (no separate DAC needed) and amplifies it enough to drive a small speaker.
- **Why this clock needs it:** The birthday-minute easter egg plays Dad's voice memo through the speaker. The on-demand lullaby button plays a recording. The MAX98357A is the standard small-scale solution — no external DAC, no complex wiring. Adafruit popularized it; many clones exist.
- **What to look for:** Adafruit product #3006 is the reference. Chinese clones on Amazon work fine for dev (look for ones with identical pinout). Solder the header pins yourself or get one with pre-soldered headers.
- **Sourcing:** Adafruit if you want the "known-good" version with documentation. Amazon clones are 50% cheaper and fine for breadboard testing.

### Small 8Ω speaker, 1-3W — **$3-5** × 1

- **What it is:** A mini speaker driver — 40mm diameter is a good size. Mylar cone, 8Ω impedance, handles 1-3W.
- **Why this clock needs it:** Plays the voice memo and lullaby through the MAX98357A. 3W is the max the amp can push; a 1W speaker will distort, 5W+ won't get loud enough at this power budget. 8Ω matches what the MAX98357A expects. Small enough to mount inside a 1-1.5" deep enclosure.
- **What to look for:** "40mm 8 ohm 3W mini speaker" — comes with flying leads you can crimp or solder to a 2-pin JST connector (spec specifies JST for the final PCB-to-speaker link).
- **Sourcing:** Amazon 4-pack or individually. CUI Devices or Dayton Audio for the serious version; generic clones fine for dev.

### microSD breakout (SPI) — **$3-5** × 1

- **What it is:** A small PCB with a microSD card slot and the level-shifter circuitry needed to talk to it over SPI from a 3.3V microcontroller.
- **Why this clock needs it:** Stores the MP3 files (voice memo + lullaby). The ESP32 has limited flash (~1-2 MB free for user data after firmware); audio files easily exceed that. microSD gives essentially unlimited storage and is trivial to reload by popping the card out.
- **What to look for:** SPI interface (4 wires + power). Some modules include 5V→3.3V regulation; that's fine but not required — ESP32 runs 3.3V logic and the card wants 3.3V too.
- **Sourcing:** Amazon 5-pack — they're basically commodity.

### microSD card, 4-32 GB — **$5-10** × 1

- **What it is:** A postage-stamp-sized flash storage card.
- **Why this clock needs it:** Hosts the audio files. 4 GB is vastly more than needed (a lullaby + a 10-second voice memo is <10 MB), but smaller cards are actually harder to find now than larger ones.
- **What to look for:** Class 10 or better (read speed ≥10 MB/s — overkill for audio but it's the baseline), FAT32 formatted (Windows default). SanDisk / Samsung / Kingston are all fine; avoid no-name brands (higher failure rate).
- **Sourcing:** Literally anywhere — drugstore, Amazon, Best Buy.

### USB-C breakout board — **$3-5** × 1 — *no longer on the final PCB, still useful for breadboard bring-up*

- **What it is:** A small board that breaks out a USB-C connector's pins to through-hole pads you can wire to.
- **Status in the final design:** Superseded. The final PCB powers everything through the ESP32 module's native micro-USB; the user-facing USB-C port on the back panel is the far end of a captive Micro-USB-to-USB-C cable exiting through a grommet. Historical rework record: `docs/archive/hardware/2026-04-17-usb-c-breakout-removal.md`.
- **Why it's still on the buy list:** Handy for the Phase 2 breadboard bring-up — lets you feed 5V/GND to the rail without relying on the ESP32 module's micro-USB while you're still probing things. Also a generic USB-C dev tool worth having.
- **What to look for:** "USB-C breakout 5.1k CC resistor" board — no PD chip needed. The 5.1k resistors on the CC pins request 5V default-profile power.
- **Sourcing:** Amazon "USB-C breakout 5.1k" search. Adafruit has a fancy version for $5.

### Tactile switches (6×6mm) — **$3 for a pack of 20** × 1 pack

- **What they are:** Little pushbutton switches. Press and it closes a circuit; release and it opens.
- **Why this clock needs them:** Three buttons on the side of the final enclosure — hour-set, minute-set, audio play/stop. For bring-up, you'll want extras because you'll inevitably bend a leg or desolder a wrong one.
- **What to look for:** 6×6mm through-hole tact switches, any actuation force (50-100gf is comfortable). Bag-of-20 packs are dirt cheap.
- **Sourcing:** Amazon — "6x6x5mm tactile push button switch 20 pack".

### Solderless breadboard (830 tie-point) — ~~**$5-8** × 1~~ **Already owned**

> **Status:** Salvaged from a larger dual-bus prototyping board (Va/Vb/Vc/Vd rails, ~2400 tie points). Better than the $10 kit, no need to order.

- **What it is:** A plastic board with a grid of holes that are internally connected in rows. Poke component leads in, poke jumper wires in, nothing needs to be soldered — you can rearrange freely.
- **Why this clock needs it:** Phase 2 is all about wiring everything together and testing, without committing to a PCB layout. Breadboard lets you move a button, add an LED to the data line, re-pin an I²S wire, all without a soldering iron.
- **What to look for:** "830 tie-point breadboard" is the standard size; fits an ESP32 dev board across the middle split. Metal backing plate is nice but optional.
- **Sourcing:** Amazon 2-pack. $6-8 total.

### Jumper wire kit (M-M, M-F, F-F mixed) — **$5-8** × 1 kit

- **What they are:** Short wires with pre-crimped pin connectors on each end. M (male) is a pin that plugs into a breadboard hole. F (female) is a socket that accepts a pin.
- **Why this clock needs them:** Connect breadboard points to dev-board pins (need M-F — female end plugs onto the dev board's header pins, male end into breadboard), breadboard-to-breadboard (M-M), and breakout-to-breakout (F-F when both have header pins).
- **What to look for:** Kit with 40 each of M-M, M-F, F-F in assorted colors. Length 20cm is a good default.
- **Sourcing:** Amazon "breadboard jumper wires kit" — one pack has everything.
- **Note:** An M-M-only set was salvaged alongside the breadboard; keep as extras, but the EDGELEC kit is still needed for M-F (required to connect the ESP32 dev board's male header pins into the breadboard).

### USB-C cable + 5V 2A USB charger — **$0-10**

- **What they are:** Just a charging cable and a USB power brick.
- **Why this clock needs them:** Powers the dev rig. Most phone chargers deliver 5V at 2A+ and work fine. USB-C cable must be a real one (not a charge-only USB-A to USB-C adapter) for the CC-resistor breakout to work.
- **Sourcing:** Probably already in a drawer at home. If not, any phone charger + cable.

## Total

Low estimate: ~$50. High estimate: ~$72. (DS3231 + breadboard removed — already owned.)

## Also salvaged (2026-04-15)

Pulled from a trashed prototyping stash:
- Dual-bus breadboard (~2400 tie points, Va/Vb/Vc/Vd rails) — replaces wishlist breadboard kit
- Assorted resistors (useful for pull-ups / current limiting on buttons and WS2812B data line)
- M-M jumper wires (extras; M-F still needs to be ordered)
- Alligator clip test leads (useful with a multimeter for probing)

## Wishlist (2026-04-15)

Amazon wishlist `4Q4NKIFBMW56` pulled together on 2026-04-15. Every parts-doc line above is covered. Multi-packs on most items (ESP32 3-pack, speaker 4-pack, MAX98357A 2-pack, breadboard 4-pack, tact switch 20-pack) — the right call for a first-time hardware order where spares save a re-order on a dev mistake.

| Doc line | Wishlist item | Note |
|---|---|---|
| ESP32 DevKit | AITRIP ESP-WROOM-32 3-pack, $16.79 | Multi-pack is smart |
| WS2812B strip | SEZO 5m / 300 LEDs, $13.99 | 5m vs my 1m suggestion — fine, same 60 LED/m density |
| DS3231 | — (already owned) | |
| MAX98357A | GODIYMODULES 2-pack, $6.88 | Spare amp included |
| 8Ω speaker | DWEII 4-pack 3W 8Ω **with JST-PH2.0 pre-attached**, $9.99 | Matches the final-PCB 2-pin JST connector — zero crimping needed |
| microSD breakout | Stemedu 2-pack, $5.99 | |
| microSD card | SanDisk 4GB, $18.95 | SanDisk Ultra 32GB is the same ~$19. Swap for 32GB — same price, 8× storage headroom. No money saved, but future-proof. |
| USB-C breakout | Cermant 10-pack with coupon, $8.99 | |
| Tact switches | QTEATAK 20-pack, $6.99 | |
| Breadboard | ~~BOJACK 3-value kit, $9.99~~ | **Remove — salvaged a better dual-bus board** |
| Jumper wires | EDGELEC 120pc M-M/M-F/F-F, $7.49 | |
| USB-C cable | Anker Nano 240W 6ft, $16.99 | Solid — the CC-resistor breakout needs a real USB-C cable, this is one. |
| 5V 2A charger | TCKN 2-pack, $11.99 | |

**Wishlist total: ~$125** after removing the breadboard (salvaged). SD card pricing is flat from 4GB to 32GB at this tier — swap to 32GB for headroom. Multi-packs account for most of the remaining spend and are worth it for first-time hardware bring-up. Ships in 1-2 days from Amazon Prime, 2-4 weeks from AliExpress (don't bother saving $10-15 on 3 weeks of waiting).

## After the order arrives

When the box shows up, say "Phase 2 plan" and I'll run `writing-plans` against the Phase 2 scope. Expected output: ~25-30 TDD tasks covering:

1. Smoke-test each IC individually with a throwaway sketch (LED-only, audio-only, RTC-only, button-only)
2. Display driver wrapping FastLED + the grid module
3. RTC + NTP time sync wrapper
4. Audio player reading MP3s from SD
5. Button debounce + handler
6. WiFi captive portal for first-boot provisioning
7. Main state machine that ties it all together

End of Phase 2: one working breadboard clock, running on Dad's desk for a week before we commit to PCB layout in Phase 3.

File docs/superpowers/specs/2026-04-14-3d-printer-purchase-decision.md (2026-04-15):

# 3D Printer Purchase Decision

Date: 2026-04-14
Status: Recommendation locked, awaiting purchase

## Summary

Buy a **Bambu Lab A1** ($350). Defer AMS Lite until a multi-color project forces the upgrade. Budget ~$485 total including calipers, starter filament, and basic consumables.

This decision serves the word-clock-for-my-daughters project (light-channel honeycomb, PCB standoffs, speaker mount, button housings — all small internal white PLA parts) as the initial use case, but the printer is chosen for a broader household/hobby use profile that extends well past the clocks.

## Use Case Profile

Ranked by expected frequency, based on brainstorm 2026-04-14:

1. **Household repair** — e.g., worn stove knobs where numbers no longer read
2. **Home/garage organization** — shelf brackets, pegboard systems, shed organization, drawer dividers
3. **Kid stuff for Emory & Nora** — name signs, toys, school projects, costumes
4. **Gifts** — personalized one-offs for family
5. **Desk/workspace** — cable management, holders, mods
6. **CAD as a new skill** — treating this as a gateway into parametric design
7. **Electronics projects** (light) — word-clock internals, future ESP32/Raspberry Pi enclosures

Deprioritized: outdoors/car (low interest).

## Claude Integration Profile

- **80% design workflow** — Claude generates parametric CAD from descriptions; I refine, slice, print. Printer-agnostic.
- **20% printer operation** — queue management, monitoring, failure detection. Nice-to-have, not required. Bambu's semi-closed ecosystem is acceptable because this tier is non-critical.

## Options Considered

| Option | Price | Verdict |
|---|---|---|
| Bambu Lab A1 Mini | $200 | Rejected. 180mm bed forces segmentation on garage/kid prints too often. |
| **Bambu Lab A1** | **$350** | **Chosen.** 256mm bed, fast, rock-solid reliability, open-frame fine for PLA/PETG. |
| Bambu Lab A1 + AMS Lite | $540 | Rejected (deferred). Multi-color fails more; master single-color first. Upgrade later. |
| Bambu Lab P1S | $700 | Rejected. Enclosed chamber / ABS capability buys nothing in the use profile. |
| Prusa MK4S | $800-1100 | Rejected. Better for "Claude runs the workshop" vision; overkill for 80/20 design-first profile. Higher setup friction conflicts with "reactive but iterative" usage pattern. |

## Rationale

1. **Build volume matches use cases.** 256mm handles ~90% of household/organization prints in one piece. The remainder segments cleanly with alignment pins or dovetails.
2. **No enclosure needed.** Use cases don't require ABS/ASA. PETG covers functional and moderately-outdoor needs. Enclosure spend doesn't pay back.
3. **Ease-of-use is a requirement, not a preference.** "Reactive but iterative" user profile means friction kills usage. Bambu A1's setup-to-first-print is ~30 min vs. Prusa kit's ~4 hours.
4. **Claude integration lives primarily in CAD**, which is printer-agnostic. Printer choice doesn't meaningfully constrain the 80% case.
5. **The 20% operation tier** is a side-project opportunity via community Bambu-MCP efforts. Fragile but low-stakes.
6. **AMS Lite is purely additive.** Deferring saves $180 now with zero upgrade regret later.

## Initial Purchase List

| Item | Est. Cost |
|---|---|
| Bambu Lab A1 | $350 |
| Digital calipers (sub-$40 range is fine) | $30 |
| Starter filament: PLA Basic, 4 colors (white, black, + 2) | $80 |
| Consumables: glue stick, scraper kit, spare 0.4mm nozzle | $25 |
| **Total** | **~$485** |

Deferred purchases:
- **AMS Lite** ($180) — trigger: first project that genuinely needs multi-color (likely a kid name sign or stove knob with color-inlay numbers)
- **PETG filament** — trigger: first functional print that needs heat/UV/outdoor tolerance
- **Enclosure kit** (3rd-party, ~$100) — trigger: only if I ever want to try ABS (unlikely given use profile)

## CAD Stack

Chosen for a software-engineering mindset + Claude-forward workflow:

- **OpenSCAD** — first tool for simple parametric parts (stove knob, spacers, brackets). Text-based, functional, trivial for Claude to read and write. Perfect for rotationally symmetric or obviously-parametric geometry.
- **CadQuery** — Python-based parametric CAD. For anything too complex for OpenSCAD but still model-as-code. Git-diffable, testable, LLM-friendly. This is the primary long-term target.
- **OnShape** (hobbyist tier) — browser-based constraint-based CAD with a real API. For complex mechanical assemblies where sketch-and-constraint thinking beats code. Public-models-only on the free tier.

Skip Fusion 360 — Autodesk license trajectory is hostile, and CadQuery covers the same ground for this use profile.

## First 90 Days: Project Sequence

Ordered to build skills incrementally:

1. **Benchy + factory calibration print** — day 1, comes with the printer
2. **Stove knob replacement** — canonical first real project. Measure spindle with calipers, model in OpenSCAD, iterate to fit. Paint-fill numbers for a two-tone look without AMS.
3. **Small desk organizer** — pen holder or cable clip. Fast feedback loop to build slicing intuition.
4. **Drawer divider or kitchen organizer** — first print that benefits from thinking about assembly / segmentation.
5. **Pegboard hook or shelf bracket for the garage** — first PETG print for strength/durability.
6. **Name sign for Emory or Nora** — first aesthetic piece. Single-color with paint fill OR trigger for AMS Lite purchase.
7. **Word-clock internals** (when the clock project reaches that phase) — light-channel honeycomb, PCB standoffs, speaker mount, button housings.

## Claude Integration Roadmap

Ordered by leverage-per-hour:

- **Phase 1 (day 1): OpenSCAD via Claude.** No integration needed — Claude writes OpenSCAD directly in-chat. Highest-leverage, zero-setup. This alone is most of the 80%.
- **Phase 2 (~month 1): CadQuery MCP.** Install an existing community MCP or write a thin one. Unlocks programmatic CAD with full Python power.
- **Phase 3 (~month 3): OnShape API MCP.** For complex assemblies. Useful specifically when mechanical constraints matter.
- **Phase 4 (~month 6, optional): Bambu local API MCP.** The 20% operation tier. Community Bambu-MCP projects exist; adopt or contribute. Only worth doing if a real workflow demands it — do not build speculatively.

## Open Questions

- Filament storage — dry box vs. ambient. Revisit after 30 days based on humidity observations.
- Slicer choice — Bambu Studio (default, proprietary) vs. OrcaSlicer (open-source fork, Bambu-compatible). Start with Bambu Studio; switch to OrcaSlicer if I hit a wall.

## Fallback: No Printer Available

If the Bambu A1 purchase is delayed, fails, or is otherwise unavailable when the clock project needs internals, outsource the ~4 internal parts per clock. They are all white PLA, small, non-structural, and hidden inside the enclosure — a perfect fit for online FDM services.

| Vendor | Fit | Est. cost (4 parts × 2 clocks) | Lead time |
|---|---|---|---|
| **SendCutSend** | Yes — now offers FDM print service alongside laser cut, already in use for the face | ~$60-80 per clock | 1-2 weeks |
| **Craftcloud** (hub / aggregator) | Yes — quote-comparison across multiple FDM services | ~$40-70 per clock | 1-3 weeks |
| **Shapeways / JLC3DP** | Yes | ~$50-90 per clock | 2-3 weeks |
| **Local maker-space** (e.g., Dallas Makerspace) | Possible if a membership makes sense by then | Membership cost | Variable |

The firmware and PCB design assume nothing about the origin of the printed parts. As long as the CAD files in `enclosure/` are vendor-neutral STEP + STL, any of the above will work. Budget impact: +$60-80 per clock vs. printing in-house. Still well under the $150-180/clock spec target (the per-clock budget has headroom).

**Decision deferral:** Revisit when Phase 4 (enclosure) starts — whichever delivers the parts on time wins.

## Non-Goals

- Print farm operation.
- Production/commercial printing.
- Exotic materials (carbon-fiber nylon, TPU, PC).
- Large-format prints (>256mm) that can't be segmented.

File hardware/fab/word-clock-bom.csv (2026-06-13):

Comment | Designator | Footprint | LCSC Part #
WS2812B-B/W | D1,D2,D3,D4,D5,D6,D8,D9,D10,D11,D12,D13,D14,D15,D16,D17,D18,D19,D20,D21,D22,D23,D24,D25,D26,D27,D28,D29,D30,D31,D32,D33,D34,D35,D36,D37,D38,D39,D40,D41,D42,D43,D44,D45,D46,D47,D48,D49,D50,D51,D52,D53,D54,D55,D56,D57,D58,D59,D60,D61,D62,D63,D64 | LED_WS2812B_PLCC4_5.0x5.0mm_P3.2mm | C114586

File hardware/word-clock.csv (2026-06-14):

Designators | Qty per clock | Part | Value | Footprint | LCSC | Notes
D1-D6,D8-D64 | 63 | WS2812B-V6 | Addressable RGB LED | LED_WS2812B_PLCC4_5.0x5.0mm_P3.2mm | C52917433 | As-built LED, JLC-placed. Design originally specced WS2812B-B/W (C114586); V6 substituted at order time — see hardware/fab/README.md. D7 intentionally unused (63 LEDs).
C1,C3-C23 | 22 | Ceramic capacitor | 100nF | Capacitor_THT:C_Disc_D5.0mm_W2.5mm_P5.00mm |  | THT decoupling, one per IC Vcc. Hand-soldered.
C2 | 1 | Electrolytic capacitor | 1000µF / 10V | Capacitor_THT:CP_Radial_D10.0mm_P5.00mm |  | Bulk cap at LED 5V input. Hand-soldered.
R1 | 1 | Resistor | 300 Ω | Resistor_THT:R_Axial_DIN0207_L6.3mm_D2.5mm_P10.16mm_Horizontal |  | LED data series resistor. Hand-soldered.
J_RTC1 | 1 | DS3231 ZS-042 RTC module | — | word-clock:Daughtercard_RTC_DS3231 |  | Amazon module on right-angle 1x6 socket. KEEP the trickle-charge resistor — inert at 3.3V VCC (1N4148 reverse-biased); CR2032 protected by the 5-year replacement cadence, not a desolder (decision 2026-04-20).
J_SD1 | 1 | HW-125 microSD module | — | word-clock:Daughtercard_SD_HW125 |  | Amazon module on right-angle 1x6 socket.
J_AMP1 | 1 | MAX98357A I2S amp breakout | — | word-clock:Daughtercard_AMP_MAX98357A |  | Amazon module. Hand-soldered.
SW1,SW2,SW3 | 3 | Tactile push switch 6mm | — | Button_Switch_THT:SW_PUSH_6mm |  | Minute / Audio / Hour. Bottom-side, pressed through the back panel.
U1 | 1 | ESP32 DevKit (CP2102 | 38-pin) | — | ESP32_DevKit_V1:ESP32_38Pin |  | Generic ESP32-WROOM-32 dev module (AITRIP). Inspect VBUS for a polyfuse before power.
U2 | 1 | 74HCT245 | Octal bus transceiver | Package_DIP:DIP-20_W7.62mm |  | 3.3V→5V level shifter for LED data. DIP-20, hand-soldered.

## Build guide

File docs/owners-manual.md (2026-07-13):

# Word Clock — Owner's Manual

One of two hand-built word clocks — Emory's (2030) and Nora's (2032).
Hardwood shell, 63 LEDs behind a laser-cut letter face, built to run for
40 years. This manual covers everything a caretaker needs; nothing inside
requires a soldering iron.

## Reading the clock

The face spells the time in words ("IT IS TWENTY TO EIGHT IN THE
EVENING"), updating each minute to the nearest five.

- **Evenings and nights (7 PM – 8 AM)** the letters dim to about a
  quarter brightness so they don't light up the room during sleep.
- **Amber-tinted letters** mean the clock hasn't been able to check the
  time over WiFi for 48+ hours. It still keeps good time on its internal
  battery clock — amber is a nudge to check the WiFi, not an alarm.
- **Holidays** bring special color palettes on their dates.
- **On her birthday**, at the minute she was born (Emory 6:10 PM,
  Nora 9:17 AM), the clock lights HAPPY-BIRTH-DAY with her name in
  rainbow and plays Dad's recorded birthday message. Once a year.

## First-time setup (or after moving / changing WiFi)

1. Plug the clock's USB-C cable into a power brick rated **3 A (15 W) or
   better**.
2. If the clock has no WiFi saved, it creates its own network named
   **WordClock-Setup-XXXX**. Join it from a phone; a setup page opens by
   itself (if not, browse to `192.168.4.1`).
3. Pick the home WiFi, enter its password, choose the timezone, submit.
4. **Press the AUDIO button on the back of the clock** when the page asks —
   this proves a person with hands on the clock approved the change.
5. The clock joins the WiFi, fetches the time, and starts telling it.
   Done — it needs nothing else, ever, day to day.

## The three buttons (back panel, engraved labels)

| Button | Press | Does |
|---|---|---|
| **AUDIO** | once | Play or stop the lullaby (two tracks, alternating) |
| **HOUR** | once | Advance the time one hour (for offline use — normally WiFi keeps time automatically) |
| **MIN** | once | Advance the time one minute |
| **HOUR + AUDIO** | hold 10 seconds | Forget the saved WiFi and reopen the setup network (step 2 above) |

## Battery replacement — every 5 years

The internal clock battery (a common **CR2032** coin cell) only works
during power outages, so it lasts many years — replace on a 5-year
calendar reminder rather than waiting for it to die.

1. Unplug the clock and lay it face-down on something soft.
2. Remove the **4 corner screws** on the back panel and lift the panel
   straight off. The inner plastic plate and the three button caps stay
   attached to it — **nothing falls out**.
3. The coin cell sits in a holder on the small clock board (the one with
   the battery). Slide the old cell out, press the new one in **+ side
   facing out of the holder**.
4. Before closing: press gently on each of the small plug-in boards to
   confirm they're firmly seated in their sockets (the clock board came
   loose once during assembly — a firm press is cheap insurance).
5. Set the panel back on, drive the 4 screws snug in a criss-cross
   order — firm, not gorilla-tight.
6. Plug in. The clock reconnects to WiFi and fixes its own time. Set the
   next calendar reminder for +5 years.

If a corner screw ever stops biting, drive it 0.5 mm deeper with a fresh
pilot hole or step up one screw length — the hardwood wall has plenty of
material.

## Troubleshooting

| Symptom | Likely cause → fix |
|---|---|
| Face completely dark | No power — check brick, outlet, and cable seating |
| Letters amber-tinted | No WiFi sync for 48 h — check the router; if the WiFi itself changed, hold HOUR+AUDIO 10 s and redo setup |
| Time wrong after an outage | Wait a minute for WiFi sync; if it stays wrong, the coin cell is likely dead — replace it (above) |
| No sound on AUDIO press | Open the back (4 screws) and reseat the SD card and the small audio board |
| A button feels gritty or stuck | Press it firmly a few times to seat it; if it persists, open the back and check the cap moves freely in its guide |
| Setup page never appears | Browse to `192.168.4.1` manually while joined to the WordClock-Setup network |

## Spare parts and repairs

Every custom part is reproducible — sources and print files live in this
repository under `enclosure/` (printed parts), `hardware/` (circuit
board), and `firmware/` (the program).

- **Button caps** (the only custom part likely to ever wear): spares were
  printed with the originals. To swap one: back panel off, circuit board
  lifted off its four posts, press the old cap's neck from the outside of
  the panel until it pops out of its socket, snap the new one in.
- **Coin cell**: CR2032, any brand.
- **Re-recording the audio** never requires opening the clock: with the
  clock's USB cable plugged into a computer and the home WiFi up, the
  loader tool in the project repository (`firmware/tools/sd_load.py`)
  sends new recordings inside (the cable controls the clock; the audio
  travels over WiFi). The back only comes off for hardware — battery,
  or a physically failing card.
- **Power**: any USB-C brick, 3 A / 15 W or better.

## Vital statistics

| | |
|---|---|
| Size | 192 × 192 mm face, hardwood shell |
| Power | 5 V USB-C, 3 A brick recommended; captive cable exits the back |
| Brain | ESP32; reprogrammable over the same USB-C cable, no disassembly |
| Time | WiFi (NTP) with battery-backed clock (DS3231) as keeper |
| Display | 63 addressable LEDs, one per word, warm white |
| Sound | Two recorded lullabies + a birthday message, from an SD card inside |

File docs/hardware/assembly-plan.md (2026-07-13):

# Assembly Plan

End-to-end glue-up + fasten-up sequence for each clock. Single source of
truth once all parts are in hand. Emory is the pilot build; Nora follows with
fixes baked in.

Prereqs: PCB validated on breadboard (Phase 2 firmware bring-up complete),
final PCB ordered and received from JLCPCB, 3D-printed internals printed,
wood arrived from Ponoko, supplies on the `TODO.md` order list in hand.

---

## Fastener + adhesive BOM (per clock)

| Item | Qty | Purpose |
|---|---|---|
| M3 × 1/2" or 5/8" wood screws (pan-head, brass or steel) | 4 | Back-panel-to-frame-wall closure (thread directly into the 6.4 mm frame wood at the existing 4 mm corner inset; pre-drilled pilot hole) |
| M3 × 10 mm brass hex spacer, F-F (measured 4.5 mm AF) | 2 | Speaker mount risers — drop through the carrier plate's hex collars and stand on the panel wood, 37 mm apart behind the vent. No adhesive; the hex bore stops rotation |
| M3 × 6-8 mm machine screws | 2 | Speaker integral flanges → speaker hex spacers |
| Rubber grommet for ~16 mm panel hole + cable P-clip | 1 | USB cable strain relief; back-panel hole gets drilled out 6 → 16 mm at assembly so the connector overmold fits through |
| ~~Self-adhesive black foam (1 mm)~~ | 0 | **Decision 2026-07-07: no top-edge seal** — channel wall tops press directly on the film. Foam/putty held as a G2 retrofit if first-light shows bleed at the channel/film interface. |
| M3 washers (optional) | 4 | Under screw heads on the back panel to protect the wood |

**Adhesives**

| Joint | Adhesive | Why |
|---|---|---|
| Frame box joints (4 corners) | Titebond III preferred; Gorilla 5-min epoxy works as substitute | Strongest wood-to-wood; epoxy-on-finger-joints relies on joint geometry for strength but needs ≥30 min clamp time, not the 5 the label implies (Nora's frame is being assembled with epoxy 2026-04-25) |
| Face top edge → frame top | Titebond III (do NOT substitute 5-min epoxy here) | Large flat-on-flat perimeter joint; 5-min epoxy's ~3 min open time is too fast for face alignment, and squeeze-out is much harder to clean off a visible exterior joint than wood glue is |
| Speaker hex spacers | **None** — spacers pass through the carrier plate's hex collars and stand on the wood under screw compression | Superseded the epoxy plan when the carrier plate (`enclosure/3d/pcb_carrier.py`) replaced loose parts, 2026-07-11 |
| Carrier plate → back panel interior | **None — dry fit (decision 2026-07-12, Emory build)** | Every in-service load is compression (button presses squeeze plate against panel; the screwed-down 48.0 stack holds it captive); laterally it's pinned by the spacers in the hex collars and the caps in the panel holes. Dry fit keeps every part individually replaceable over the 40-year horizon; glue can be added later if float ever annoys, but never removed |
| Light-channel top edge → diffusion film (on face back) | **None (2026-07-07)** — direct PETG-on-film contact under screw compression; foam/putty retrofit only if G2 shows bleed | Interface bleed judged at G2. (Diffuser stack is film-only as of 2026-04-26 — opal acrylic was removed from the production stack after bench testing showed it was the source of lateral bleed.) |
| Inner letter islands → face back | self-adhesive diffusion film | Ships pre-glued; the same film also retains loose letter islands |

**Tools**

- 4 × corner clamps (Bessey right-angle or equivalent)
- 2-4 × bar clamps (face-to-frame glue-up)
- Framing square (12"+)
- Tape measure / caliper
- Sanding block, P220 grit
- Needle-nose tweezers (letter islands)
- Small Phillips screwdriver (M3)
- Scissors (diffusion film cutting; X-Acto + steel ruler unnecessary at this precision level)
- 5/8" step drill bit (cable port drill-out, Phase F2)
- ~2 mm drill bit (frame wall pilot holes for back-panel wood screws, Phase G9)
- Masking tape (clamping substitute + alignment)

---

> **STACK CORRECTION (2026-07-09, found on the bench):** the interior cavity
> is the FULL 48.0 mm (face glues ON TOP of the frame walls, back panel screws
> UNDERNEATH them). The original stack table wrongly counted the face + panel
> thicknesses (6.4 mm) inside the 48.0, which sized the PCB standoffs 6.4 mm
> too short (22.0 → correct 28.4 panel-to-PCB-underside). The carrier plate
> (`enclosure/3d/pcb_carrier.py`, posts 25.9 + web 2.5) and the button caps
> (`button_cap.py`, anvil redesign) carry the corrected numbers. The light
> channel (17.84) is unchanged: 28.4 + 1.6 + 17.84 + 0.16 = 48.0 exactly.
> The old loose `pcb_standoff.py` posts (22.0) were superseded and the
> script deleted 2026-07-12.

## Phase A — Pre-assembly prep

Do all of this before opening any glue. Most of these are independent and
can run in parallel.

- [ ] **Inspect Ponoko wood pieces.** Confirm face dimensions 192 × 192 ×
      3.2 mm, frame strips 192 × 48 × 6.4 mm × 4 strips, back panel
      192 × 192 × 3.2 mm. Sand any scorched edges with P220.
- [ ] **Measure frame interior + PCB outline (for light channel + fit
      verification).** Once each frame is fully cured, caliper the inner
      dimension on all 4 sides at top, middle, and bottom of the wall
      height (12 measurements per frame). Record the smallest. When
      JLCPCB boards arrive, caliper the PCB outline both axes. Decision
      tree: total PCB-to-frame clearance ≥ 1.4 mm → fits cleanly;
      0.4–1.4 mm → fits but tight, design light channel ~3 mm under
      smaller frame inner; < 0.4 mm → sand frame interior with P220
      block until clearance opens up. Light channel envelope is locked
      from these measurements, not from the nominal 179.2 / 177.8 spec.
- [ ] **Assemble + fully test the final PCB** on the workbench, not inside
      the enclosure. Flash firmware, verify every peripheral works, then
      power off.
- [ ] **Print 3D internals.**
  - Carrier plate × 1 (`pcb_carrier.py --part plate`; PETG, glue-face
    down, brim, supports off — print the coupon first on a new printer
    or filament)
  - Button actuator caps × 3 + 2 spares (`button_cap.py`; ⌀8 snap-fit
    flange rev, 2026-07-12)
  - Light-channel honeycomb × 1 — **printed** (2026-06, at the 177.8 mm
    nominal envelope; `enclosure/3d/light_channel.py`). Dry-fit to the
    delivered PCB and the glued frame interior before final assembly;
    re-print only if frame clearance or LED-pocket centering is off.
- [ ] **Face sub-assembly (D below) can happen now** — doesn't block on anything else.
- [ ] **Cut captive USB cable to internal length.** Measure from back-panel
      cable hole position to ESP32's USB-C port with ~50 mm slack.
      Typical: 100-150 mm of cable inside, the rest trails outside as the
      user-facing USB-C plug.

---

## Phase B — Frame box glue-up

- [ ] **B1: Dry-fit all 4 strips.** Press-fit the box joints — they should
      seat with hand pressure. If too tight, light sanding on the fingers;
      if too loose, add more glue later.
- [ ] **B2: Diagonal-check for squareness.** With the dry-fit box on a flat
      surface, measure both corner-to-corner diagonals. They must be equal
      within 0.5 mm. Rack the box into square if needed.
- [ ] **B3: Glue up.** Disassemble, apply Titebond III to each finger and
      slot on all 4 corners. Reassemble, press together. Wipe squeeze-out
      with a damp rag immediately.
- [ ] **B4: Clamp square.** 4 corner clamps, verify diagonals still equal
      before glue tacks.
- [ ] **B5: Cure 24 h** undisturbed on a flat surface.

---

## Phase C — REMOVED (2026-04-25)

The original plan had M3 hex spacers epoxied into the frame's interior
corners with the back-panel screws threading up into them. Abandoned
after `enclosure/scripts/render_back_panel.py` was found to specify a
4 mm corner inset that places the screw centers *inside* the 6.4 mm
frame wall — not in the interior corner — making the spacer-in-corner
geometry impossible. Replaced by **M3 wood screws threading directly
into the frame wall** (folded into Phase G); the 4 mm inset becomes
correct for the new strategy because it puts the screw center right in
the wall material. See `enclosure/scripts/render_back_panel.py` fastener
comment block for the locked rationale.

---

## Phase D — Face sub-assembly

Can run in parallel with B/C.

**Diffuser stack as of 2026-04-26: film only — no opal acrylic.** Bench
test with the printed 18 mm test pocket
(`enclosure/3d/light_channel_test_pocket.py`) over a single lit WS2812B
showed the film alone provides adequate hot-spot suppression at this
LED-to-film distance, while adding the acrylic introduced ~5 mm of
lateral light bleed. Acrylic sheets shelved in reserve as backup if
hot spots emerge during full-clock first-light testing — the fix
would be per-pocket acrylic cuts + light-channel walls extending
through the acrylic level (re-print of the channel at ~21 mm walls).
See `TODO.md` "Decisions locked 2026-04-26" for the rationale.

- [ ] **D1: Cut the diffusion film to ~178 × 178 mm.** Sharp scissors
      are fine for this — film is 0.16 mm and the cut edges sit hidden
      inside the assembled clock. Tolerance is generous: 177-179 mm
      cleanly satisfies "covers the 177.8 × 177.8 letter grid" and
      "stays clear of the 6.4 mm Titebond glue ring at the perimeter."
      Even off by ±2-3 mm degrades gradually rather than failing
      binary. Cut backing-side up, mark with pencil first, single
      pass. One Selens sheet (~200 × 300 mm) yields both kids' pieces
      plus practice off-cuts.
- [ ] **D2: Place face on clean bench, letter side down.** Wipe the
      back of the face with the alcohol wipe from the Selens kit (or
      IPA on a lint-free cloth). Remove dust, oils, and any kerf char
      residue. Dust under the film = visible specks when LEDs light up.
- [ ] **D3: Apply the film, adhesive-side down, centered on the inner
      letter-grid area.** Mark the 178 × 178 mm target with a faint
      pencil dot at each of the 4 corners during dry-fit before
      peeling. Peel a 2-3 cm strip of backing from one edge; align
      the partially-peeled edge with one of the marked corners; press
      down; progressively peel more backing while squeegeeing
      (included in Selens kit) outward from that edge. Stay strictly
      inside the 7 mm bare-wood perimeter — film overlapping the glue
      ring acts as a release layer and the Titebond won't bond
      wood-to-wood there.
- [ ] **D4: Letter-island retention.** As the film presses down over
      the apertures, the loose inner-letter islands (A/B/D/O/P/Q/R/0/6/8/9
      cuttings that fell out during laser cutting) bond to the film
      automatically. If you spot any loose islands in the apertures
      *before* the film passes over them, place them with tweezers.
      You can lift the film slightly to reposition islands while the
      adhesive is still fresh; once fully pressed, they're locked.

---

## Phase E — Face-to-frame glue-up

- [ ] **E1: Dry-fit the face on the frame.** Face 192 × 192 mm sits flush
      with the 192 × 192 mm frame top. All edges align. Verify the
      diffusion film (applied in Phase D) does NOT extend into the
      6.4 mm perimeter that contacts the frame top. If it does, either
      trim the film back or accept reduced glue area on that edge.
- [ ] **E2: Apply wood glue** in a continuous bead along all 4 top
      edges of the frame (the 6.4 mm wide top surface of each strip).
      **Titebond III preferred** (waterproof, ~20-30 min open time);
      **Gorilla Wood Glue acceptable** (water-resistant, ~10-15 min
      open time — same PVA family). DO NOT substitute Gorilla 5-min
      epoxy here — the open time is too short for a 192 mm perimeter
      alignment, and squeeze-out is much harder to clean off a visible
      exterior joint than wood glue is. Spread with a finger or
      spreader to a thin even layer.
- [ ] **E3: Place face letter-side up** on the frame top, align flush
      at all edges. Slide gently to true if needed (wood glue's
      open time gives you some leeway).
- [ ] **E4: Clamp with bar clamps** across the face, ideally 4 (one per
      side). Cauls (scrap wood between clamp and face) protect the wood
      from clamp marks.
- [ ] **E5: Wipe squeeze-out** at the joint line with a damp rag
      immediately. Wood glue cleans up easily while wet; cured drips
      have to be chiseled or sanded off later.
- [ ] **E6: Cure 24 h** undisturbed before unclamping.

---

## Phase F — Back panel internals

Do F1–F9 with the back panel on the bench, still separate from the frame.

- [ ] **F1: Verify back-panel cutouts.** 4 × M3 corner clearance holes
      (3.3 mm at 4 mm inset), 3 × button actuator holes (6.5 mm), 1 ×
      cable hole as cut (6 mm — gets drilled out in F2), 1 × speaker vent
      pattern. Clean up any char with P220.
- [ ] **F2: Drill cable hole 6 → 16 mm** with a 5/8" step bit (or
      Forstner) on a backing board. Step bit walks up the existing 6 mm
      hole cleanly; feed slowly, clear flutes between holes. The
      enlarged hole has to be big enough for the USB connector overmold
      (~12-15 mm) to pass through during cable threading — strain relief
      moves to an internal P-clip in F4 instead of being provided by the
      grommet itself.
- [ ] **F3: Install rubber grommet** in the now-16 mm cable hole.
      Cosmetic + dust-blocking only at this size; doesn't grip the cable.
- [ ] **F4: Thread USB cable through the grommet** from outside (USB-C
      plug trails outside) to inside (the module-end USB-C plug lies loose inside).
      Screw a small cable P-clip to the back-panel interior 2-3 cm
      inside the cable hole, clamp the cable in the P-clip — this is
      the actual strain relief that keeps tugs on the outside cable from
      reaching the ESP32 USB-C solder joints.
- [ ] **F5: Seat the carrier plate** (`pcb_carrier.py --part plate`,
      PETG) on the panel interior, web-side down, orientation chamfer
      toward the cable-hole corner. **Dry fit — no glue (decision
      2026-07-12).** To confirm position, drop two ⌀2 mm drill bits
      through the plate's registration holes into the speaker-vent grid
      corner holes; they should pass clean. Pull the bits.
- [ ] **F6: Drop the 2 × M3 hex spacers** into the plate's hex collars
      behind the speaker vent. They pass through and stand on the wood;
      the hex bore stops rotation. No adhesive.
- [ ] **F7: Mount the speaker** with 2 × M3 × 6-8 mm machine screws
      through the speaker flanges into the hex spacers. Connect the
      JST-PH 2-pin lead to the speaker but leave the PCB-side end loose
      for now. Snap the USB cable into the plate's cable cleat.
- [ ] **F8: Snap the button actuator caps × 3** into the carrier
      plate's guide bores: drop each cap neck-first down its bore and
      press (pencil-end or dowel — the bore is too narrow for a
      fingertip) until the ⌀8 flange clicks through the roof's snap
      hole. The neck drops into the panel's 6.5 mm button hole below.
      Caps are now captive — they cannot fall out with the panel off —
      and each rides its own compartment, pre-aligned under its switch.
      To ever swap a cap (board must be off the posts): press its neck
      from the panel exterior and it pops back out the top. (History of
      the three earlier cap-retention designs: `enclosure/3d/
      button_cap.py` and `pcb_carrier.py` docstrings.)

---

## Phase G — Final closeout

The compression-sandwich moment. Everything has been prepped to slot
together; now it does.

- [ ] **G1: Inspect the frame + face** (cured from E) interior. Remove any
      glue drips with a chisel. Dry-fit the light channel into the frame,
      letter-side aligned. It should slide in and rest against the back
      of the face — channel walls press directly against the diffusion
      film (which is bonded to the face back; no top-edge seal, per the
      2026-07-07 decision).
- [ ] **G2: First-light bleed assessment** *(post-2026-04-26 design;
      diffuser is film-only).* Before fastening anything, do a rough
      preview: hold the back-panel-plus-PCB assembly behind the
      frame+face, power on briefly via USB, light a few words
      (firmware in normal operation). Look at the face from typical
      viewing distance (~2 ft). If you see distinct LED hot spots
      bleeding through the cutouts, OR significant light bleed into
      filler letters, the acrylic-shelved-as-backup decision activates
      — disassemble, cut acrylic per-pocket, reprint the light channel
      at ~21 mm walls extending through the acrylic level. If face
      looks clean (uniform glow on lit words, dark on filler letters),
      proceed.
- [ ] **G3: Plug the module end (USB-C)** of the captive cable into the ESP32
      module on the PCB.
- [ ] **G4: Connect the speaker JST** to the PCB's speaker header.
- [ ] **G5: Place the PCB on the carrier posts.** The board's 4 corner
      holes (H1–H4) drop onto the posts' 3 mm stubs, LEDs facing UP
      (toward the light channel / face). The stubs locate the PCB
      without holding it down.
- [ ] **G6: Verify button action.** The caps sit pre-aligned in their
      carrier guide bores directly under SW1/SW2/SW3. Press each from
      the panel exterior and listen for the tact-switch click. If one
      doesn't click, the board isn't fully seated on its stubs — STOP
      and reseat before closing.
- [ ] **G7: Lower the frame + face assembly** onto the back-panel-plus-PCB.
      PCB slides up into the frame interior, the light channel's top
      edge presses against the diffusion film on the face back. Back
      panel edges sit flush with frame bottom edges.
- [ ] **G8: Align back-panel corner clearance holes** with the frame
      walls below them. The 4 mm-inset holes fall over the 6.4 mm walls
      (not the interior corner) — that's intentional with the
      wood-screw approach.
- [ ] **G9: Pre-drill the frame wall** at each of the 4 corner positions
      with a ~2 mm pilot bit, going down through the back-panel
      clearance hole into the frame wall ~10-12 mm. Hardwood splits
      without a pilot, especially this close to a finger joint.
- [ ] **G10: Drive 4 × M3 × 1/2"–5/8" wood screws** through the back
      panel corner holes into the pilot holes in the frame wall. Hand-
      tight first, all 4, before any torquing.
- [ ] **G11: Torque in cross-pattern** (diagonal, not around the
      perimeter) to snug-not-gorilla-tight. The compression sandwich is
      now engaged: face → diffusion film → light channel top edge →
      channel walls → PCB → carrier posts → carrier web → back panel.
      Wood screws hold all of it in tension against the frame walls.
      (No opal acrylic — the production diffuser stack is film-only as
      of 2026-04-26; see the diffuser note above.)
- [ ] **G12: Power on via USB-C.** Flashing and daily operation use this
      port. If anything behaves wrong, loosen all 4 screws, lift back
      panel, debug; the clock is fully serviceable.

---

## Jig notes — keeping the frame square

The dominant risk in Phase B is a parallelogrammed frame box (all 4
angles off square but still closing). Three defenses:

1. **Dry-fit + diagonal measurement BEFORE glue touches the joints.**
   Opposite-corner distances must be equal. If not, the dry-fit itself
   is out of square; revisit kerf compensation before gluing.
2. **Corner clamps during cure**, not strap clamps — corner clamps pull
   90° explicitly; strap clamps only pull the perimeter and can tolerate
   a parallelogram.
3. **Re-check diagonals 5 min into cure.** Titebond III has ~20 min open
   time; if the box has racked under clamp pressure, there's still a
   window to correct.

A simple backup jig: 4 scrap wood blocks cut to exactly 90° (verified with
a framing square), placed in the 4 inside corners during cure. The blocks
physically enforce the right angle even if the clamps slip.

---

## Post-assembly validation

Before declaring the build done, walk through the Phase 2 hardware checks
(`firmware/test/hardware_checks/wifi_provision_checks.md` plus any other
module checklists as they're written). Assembly can introduce issues that
breadboard bring-up didn't catch: an unseated daughtercard (Emory's DS3231
lost its socket during closeout, 2026-07-12 — reseat fixed it), speaker
wire pinched by the light channel, a cap dragging in its guide bore.
Burn-in: 30 days of running on Dad's desk before declaring Emory done and
starting Nora.

---

## Parallel-track artifacts

Run these while epoxy cures — they're not blocked on the main sequence:

- Re-record voice memos if any earlier pass is stale
- Confirm SD card is FAT32 with the three audio files at root:
  `lullaby1.wav`, `lullaby2.wav`, and `birth.wav`, 16-bit PCM 44.1 kHz
  mono little-endian (per the 2026-05-02 audio-playlist design; the
  lullaby is now a two-track playlist that auto-advances, and the
  birthday message interrupts an in-progress lullaby). Design pivoted
  from MP3 to uncompressed WAV during the audio-module spec pass to drop
  the MP3 decoder dependency.

---

## Long-term maintenance

### DS3231 CR2032 replacement — every 5 years

The DS3231 RTC module (ZS-042) keeps time during power outages on a CR2032 coin cell. In a mostly-powered clock the battery drain is minimal (~2 μA only during outages), so a typical 220 mAh cell has >10 year practical life. We replace every 5 years conservatively — this also keeps the cell voltage comfortably above the 2.6V threshold where the onboard trickle-charge circuit would start engaging (see `docs/hardware/pinout.md` §Critical Issues #1 for the full physics).

**Back panel is removable** via 4 × M3 wood screws threaded into the
frame wall — unscrew, swap cell, screw back. Takes 2 minutes per clock.
Wood screws into hardwood handle ~10-15 open/close cycles before threads
loosen meaningfully; for a 5-year battery cadence over 40 years (8
cycles), well within tolerance. If a thread does eventually strip, the
fix is to drill the pilot hole 0.5 mm deeper and step up to a slightly
longer screw.

**Replacement schedule:**

| Clock | First CR2032 install | Next replacement | Then every |
|---|---|---|---|
| Emory | TBD (~2026 breadboard → ~2030 delivery) | +5 years from install | 5 years |
| Nora | TBD (~2032 build) | +5 years from install | 5 years |

**Set calendar reminders at install time.** The clock won't warn you — the battery just goes flat, and on the next power outage the RTC loses the time and reverts to 2000-01-01 until NTP re-syncs. No catastrophic failure, but a 5-minute avoidable inconvenience.

**Why not remove the trickle-charge resistor instead?** Considered and rejected 2026-04-20. The trickle circuit is inert on 3.3V with a fresh cell (diode reverse-biased). The actual risk is end-of-life batteries, mitigated cheaper by the replacement schedule than by a desolder step that could damage the board.

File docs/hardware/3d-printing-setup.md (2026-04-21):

# 3D Printing Setup — Bambu Lab A1

End-to-end setup for the word-clock 3D-printed parts. First-time use of the
Bambu A1; this doc captures the path from "box on desk" to "first usable
print in hand."

**Already installed on this machine (2026-04-16):**
- Bambu Studio slicer (`/Applications/BambuStudio.app`, via Homebrew)
- `build123d` Python CAD library (`enclosure/3d/.venv/`)
- `ocp-vscode` Python package + **OCP CAD Viewer** VS Code extension
  (live 3D preview of build123d parts without exporting STL)

**Scripts ready to print:**
- `enclosure/3d/pcb_standoff.py` → `out/pcb_standoff.stl` (×4 needed)
- (more parts land here as measurements unblock them)

---

## Printer onboarding (first time only, ~30 min)

When the A1 arrives, follow Bambu's official unboxing quick-start first
(the printed card in the box). It covers physical setup — remove shipping
bolts, attach the AMS lite if you ordered one, plug it in.

Then from the printer's on-screen wizard:

1. **Connect to WiFi.** 2.4 GHz only on the A1 — same band-constraint as
   the word clock itself. Use the home network you'll expect the clock to
   use.
2. **Calibrate.** The A1 runs an auto-calibration routine on first power:
   vibration compensation, flow rate, bed tilt. ~15 min. Don't skip;
   skipping shows up as layer shifts later.
3. **Create a Bambu account** in the printer UI (email + password). Needed
   to link Bambu Studio to the printer over the network.
4. **Print the test cube** from the onboard SD card to verify everything
   works before trying our custom parts.

---

## Bambu Studio first launch

1. Open `/Applications/BambuStudio.app`.
2. Sign in with the same Bambu account you used on the printer.
3. `Device` tab → the A1 should appear under "My Devices". Click to bind.
4. `Preference` → confirm:
   - Units: mm (default)
   - `Auto-Check Update`: on (keeps slicer current with printer firmware)
   - `Enable network plugin`: yes (needed to send prints to the printer)
5. Load a filament profile:
   - Click the filament slot → "Bambu PLA Basic" (generic PLA is fine for
     every internal clock part).
   - Scan the RFID spool (if Bambu branded) or tell the AMS manually what
     color/type is loaded.

---

## Printing a word-clock part

Standoff posts are the first parts needed. The same flow applies to every
future part in `enclosure/3d/`.

1. **Regenerate the STL** (always — parameters may have changed):

   ```bash
   cd ~/dev/personal/word-clock-for-my-daughters
   enclosure/3d/.venv/bin/python enclosure/3d/pcb_standoff.py
   # or build all at once:
   enclosure/3d/.venv/bin/python enclosure/3d/build_all.py
   ```

2. **Open Bambu Studio.**
3. `File → Import → Import 3MF/STL` → pick `enclosure/3d/out/pcb_standoff.stl`.
4. **Orient the part.** For the standoff: right-click the part in the 3D
   view → "Auto Orient" → Bambu Studio picks the flattest face (the
   flange bottom) to sit on the bed. This is ideal for the standoff —
   supports won't be needed.
5. **Check placement.** Part should be in the build plate's center-ish.
   The default is fine.
6. **Duplicate to print 4 at once.** Right-click → Clone → 4 copies.
   Bambu Studio auto-arranges them on the bed.
7. **Slice settings for small mechanical parts:**
   - Layer height: 0.2 mm (default — fine)
   - Infill: 30-50% (standoffs take compression; over 30 is fine)
   - Supports: off (auto-orient avoided overhangs)
   - Filament: Bambu PLA Basic, 220°C (default)
8. Click **Slice**. Preview the toolpath (right panel). Rough sanity
   check: time and filament estimates reasonable (~20 min and ~5 g for 4
   standoffs).
9. Click **Send** (or Print on network). The A1 heats up and starts.

**Expected output:** 4 standoff posts, ~20 min. Each ~24 mm tall, flange
at the bottom, small locating stub on top.

---

## VS Code live-preview workflow (optional but very nice)

Instead of exporting STL + reopening in Bambu Studio every time you tweak
a parameter, you can preview in VS Code live:

1. Open the repo in VS Code: `code ~/dev/personal/word-clock-for-my-daughters`.
2. `⇧⌘P` → "OCP CAD: Start viewer". A split-pane 3D preview opens.
3. Open `enclosure/3d/pcb_standoff.py`.
4. At the bottom of the script (before exit), add:
   ```python
   from ocp_vscode import show
   show(standoff)
   ```
5. Run the script (via the venv python). The viewer updates live.
6. Tweak a parameter, re-run, see the new geometry immediately.

Remove the `show()` call before committing; it's a dev-loop tool, not
something the STL export needs.

---

## Troubleshooting

### First layer is stringy or doesn't stick
- Re-level the bed via the A1's onboard routine (`Calibration` menu).
- Wipe the PEI bed with isopropyl alcohol; finger oils ruin adhesion.

### Parts warp at corners
- PLA at default settings shouldn't warp on an A1 (enclosed hotend is
  forgiving). If it happens: print on a brim (Bambu Studio → Supports
  → Brim: 3 mm).

### Standoff stub doesn't fit the PCB hole
- Too tight: open `pcb_standoff.py`, drop `STUB_DIAMETER` from 2.9 to
  2.85 (or 2.8), re-run, reprint one as a test.
- Too loose: go to 3.0. PLA prints 0.1-0.2 mm oversize on tight
  diameters; the 2.9 target assumes typical A1 accuracy.

### Network send to printer fails
- Check both the Mac and the printer are on the same 2.4 GHz SSID.
- If still failing: use "Export G-code to SD card" instead, carry the
  SD card to the printer.

### STL opens but looks like a mess of triangles
- Export worked but the part wasn't fused. Re-check that `standoff = base
  + post + stub` produces a single solid in build123d (the `+` operator
  unions; if you accidentally use `Compound`, parts stay separate).

---

## Filament considerations

Parts and their filament recommendations:

| Part | Filament | Why |
|---|---|---|
| PCB standoff post | PLA (any brand) | Non-structural, room-temp, no UV |
| Button actuator cap | PLA | Same |
| Speaker cradle | PLA (or PETG for vibration isolation) | PLA is fine; PETG damps vibration better if you have it |
| Light channel | **Black PLA, not white** | Optical isolator — see `docs/superpowers/specs/2026-04-15-laser-cut-face-design.md` §Light channel material override. White PLA leaks light between pockets. |

Filament not yet ordered? Bambu PLA Basic black + one of (white/cream/any
color) covers every part. 1 kg of each is more than enough for both
clocks' internals with plenty of room for calibration prints and mistakes.

**Not printed:** the diffuser stack (adhesive-backed diffusion film +
2-3 mm opal cast acrylic) is purchased, not 3D-printed. Sourcing is
tracked in `TODO.md` §Supplies still to order. An earlier PETG-print
iteration was rejected because Chelsea's 2015 clock used PETG and still
shows LED hot spots.

---

## What's blocked on physical parts arriving

These parts can't be designed until components are in hand and
caliper-measured:

- **Button actuator cap** — needs tact switch plunger height + back panel
  thickness at hole location + travel distance
- **Speaker cradle** — needs exact speaker mount-tab spacing + cone
  clearance + vent alignment
- **Light channel** — needs LED positions (from the PCB's actual CPL
  file, already in the repo), diffuser thickness decision (diffuser
  material test), PCB component envelope

Standoff is the only part whose every dimension is already locked — which
is why it's the "first print" in this flow.

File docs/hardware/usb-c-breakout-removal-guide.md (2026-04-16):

# KiCad Rework Guide — Remove Cermant USB-C breakout, power via ESP32 module

**Why:** The Cermant USB-C breakout (`J_USB1`) was planned as the user-facing port but never got data lines routed — CC resistors + VBUS + GND only, no D+/D−. The ESP32 module already has its own micro-USB with a CP2102 USB-UART bridge that handles both power and flashing. The Cermant adds no function and needs a hole in the back panel we don't want to design around. Remove it; use a panel-mount `USB-C female → micro-USB male` pigtail to expose the module's native micro-USB as a USB-C port on the back panel.

**Starting state:** `J_USB1` at PCB position (33.5, −7.46) on the bottom side, wired to the +5V rail via VBUS. `C2` 1000µF electrolytic at (25.5, −18.5) sits right next to it as the LED strip's bulk cap.

**End state:** `J_USB1` and its footprint are gone. +5V rail is fed from the ESP32 module's `5V` / `VIN` pin (which is in turn fed from the module's own micro-USB). `C2` bulk cap still sits on the 5V rail and is still physically close to the LED strip inputs. ERC clean, DRC clean, gerbers re-exported.

## Target hardware

- **ESP32 module:** AITRIP ESP-WROOM-32 3-pack (Amazon). Classic ESP32 with CP2102 USB-UART bridge and a micro-USB connector on the module board. 38-pin dev board. Module designator in our schematic: `U1`.
- **Panel-mount adapter** (to be sourced separately — not on the PCB): USB-C female (panel mount) to micro-USB male pigtail, 15–30 cm length, USB 2.0 data capable, with CC resistor pull-downs on the USB-C side. 22–24 AWG power conductors preferred. Example search term on Amazon / Adafruit / Digi-Key: "USB-C panel mount to micro-USB pigtail data."

## Pre-reqs

- `git status` clean or your pending changes saved.
- Close KiCad cleanly before starting if it's open from a previous session (it takes a file lock).
- Read `docs/hardware/kicad-rework-guide.md` once for the general rhythm — this guide follows the same structure.

---

# Part 1: Schematic changes

## 1.1: Locate and delete `J_USB1`

Open `hardware/word-clock.kicad_sch` in KiCad Schematic Editor.

1. Find the symbol labeled `J_USB1` with Value `USB-C breakout (Cermant 16P)`. It has 16 pins including `VBUS`, `GND`, `CC1`, `CC2`, `D+`, `D−`, and several shield pins.
2. Click the symbol. Press **Delete**.
3. Any wires or labels that remain connected only to `J_USB1` stubs will become floating. Delete them too — specifically any `VBUS` labels, any wire running from `J_USB1` VBUS pin to the `+5V` net, and the `GND` wire from `J_USB1` GND pin.

**Do NOT delete:**
- The `+5V` net label itself anywhere else it appears (it's still the main 5V rail).
- `C2` (1000µF bulk cap) — keep it.
- The `GND` net or `GND` labels.
- Any other passives near where `J_USB1` was.

## 1.2: Verify the ESP32 module's 5V pin feeds the +5V rail

On the `U1` (ESP32) symbol, find the pin labeled `5V` or `VIN` (pin number depends on the symbol — it's one of the outer pins on the 38-pin module; check existing wiring). This pin should already have a wire to the `+5V` net label. If it does, **good — nothing to change.** If somehow it doesn't (would be unusual), add a `+5V` power label to that pin now.

This pin is bidirectional on the AITRIP module: when the module's micro-USB is plugged in, it sources 5V out on this pin; when 5V is injected here externally, it powers the module. Our new architecture uses it as an output (micro-USB in, 5V out to the main rail).

## 1.3: Verify `C2` still sits on the +5V rail

`C2` should have one terminal on `+5V` and the other on `GND`. It does, pre-edit. Confirm visually.

## 1.4: Delete orphaned `VBUS` net

The `VBUS` net was specific to the Cermant breakout. If KiCad shows `VBUS` as an orphaned net after the deletion (i.e., referenced nowhere), it goes away automatically on save. Nothing to do.

## 1.5: Re-attach the +5V `PWR_FLAG`

The original schematic had a `PWR_FLAG` on `J_USB1`'s VBUS pin to tell KiCad that +5V is sourced externally. Deleting `J_USB1` also removed that flag, so ERC will now complain:

> `power_pin_not_driven: D1 Pin 1 [VDD, Power input]` (where D1 is `LED_IT`, the first WS2812B — its VDD sits on the +5V net with no Power Output driving it)

Fix:

1. Press **P** (place power port).
2. Select `PWR_FLAG` (it's under the `power` library).
3. Place it on the `+5V` net — anywhere on the rail works. Good spots: adjacent to the ESP32 module's `5V` / `VIN` pin (which is the new logical source), or on `C2`'s +5V terminal (close to the LED strip).
4. Wire it to the net if KiCad didn't auto-connect it.

## 1.6: Run ERC

**Inspect → Electrical Rules Checker → Run.**

Expected result: clean, same baseline warnings as before the edit. Known pre-existing warnings that are not related to this change:
- `lib_symbol_mismatch` on `J_AMP1`, `J_RTC1`, `J_SD1` — connector symbols drifted from the library cache. Cosmetic; `Tools → Update Symbols from Library` fixes if desired.
- `pin_to_pin: Tri-state + Power input` on `U2` (74HC245) A1-A7 — unused inputs tied to GND; correct behavior, KiCad just dislikes the combination.

If the `D1 VDD not driven` error still appears after the PWR_FLAG, the flag isn't actually wired to the +5V net — zoom in, verify the junction dot, and re-wire.

If new "unconnected pin" warnings appear on anything else, they're likely `J_USB1` remnants — should have been deleted in step 1.1. Re-check.

## 1.6: Save + regenerate PDF

- **Cmd-S** to save the schematic.
- **File → Plot → PDF** to regenerate `hardware/word-clock.pdf`.

---

# Part 2: PCB changes

## 2.1: Update PCB from Schematic

Open PCB Editor. **Tools → Update PCB from Schematic (F8).**

This pushes the deletion to the board. Click **Update PCB**. After it runs, `J_USB1`'s footprint should be gone. If it isn't, the footprint will have turned red (marked as "no schematic symbol") — delete it manually.

## 2.2: Delete orphaned traces from `J_USB1`'s old pads

The `J_USB1` footprint was at (33.5, −7.46). Even after the footprint is gone, traces that used to run from its `VBUS` pad to the rest of the +5V rail may be left as dangling stubs. Find and delete them:

1. **Select → All Tracks in Net → +5V** is helpful to visualize the whole rail at once.
2. Any `+5V` trace segment that terminates in empty space near the (33.5, −7.46) region is orphaned. Delete.
3. Same check for `GND` traces from the old `J_USB1` GND pad, though the GND pour will mostly mask this.

**Do NOT delete:**
- Trace from `C2` to the +5V rail.
- Trace from the ESP32 module's 5V/VIN pin to the +5V rail.
- Any other 5V traces feeding the LEDs, the MAX98357A, or the 74HC245.

## 2.3: Re-route or confirm +5V feeds everything

After the Cermant is gone, the +5V rail's power source is the ESP32 module's 5V pin. Walk the rail visually from that pin outward and confirm every previously-connected load still has a path:

- `C2` (1000µF bulk cap)
- WS2812B strip +5V pads (all 35 LEDs)
- `U2` (74HC245) Vcc pin
- `MAX98357A` VIN pin (breakout header)
- `R1` (300Ω) — actually sits between 74HC245 output and LED data, not on the 5V rail. Ignore.

If the rail is broken anywhere, press **X** and re-route with 0.5–1.0 mm trace width (match surrounding style).

## 2.4: Refill ground pour

Press **B** to refill zones. This rebuilds the GND plane around the now-empty Cermant area, closing any holes in the ground pour left behind by deleted traces.

## 2.5: Run DRC

**Inspect → Design Rules Checker → Run DRC.**

Target: 0 errors. Fix any new unconnected-pad warnings by routing (likely none, since we only deleted things).

## 2.6: Re-export fabrication outputs

- **File → Plot →** Gerbers. Layers per the original `kicad-rework-guide.md` step 2.11.
- **Generate Drill Files.**
- **Component Placement → CSV** to regenerate `hardware/word-clock-all-pos.csv`.
- **Tools → Generate Legacy BOM → CSV** to regenerate `hardware/word-clock.csv`.

```bash
cd hardware
zip gerbers.zip *.gbr *.gbrjob *.drl
```

## 2.7: Commit

```bash
cd /Users/samueldacanay/dev/personal/word-clock-for-my-daughters
git add hardware/ docs/hardware/
git commit -m "fix(hardware): remove cermant usb-c breakout, power via esp32 micro-usb"
```

---

# Part 3: Downstream edits (not KiCad)

## 3.1: Update `docs/hardware/pinout.md`

The Power section opens with "Input: USB-C 5V via USB-C breakout". That's now wrong. Change it to:

> **Input:** USB-C from the back panel via a panel-mount USB-C-female-to-micro-USB-male pigtail, plugged into the ESP32 module's on-board micro-USB port. The CP2102 bridge on the module handles enumeration for firmware flashing; the module's 5V pin feeds the main +5V rail.

Keep the power budget + mitigation discussion — still applies.

## 3.2: Update `docs/hardware/phase-2-parts-list.md`

The USB-C breakout line item is now obsolete. Either delete it or note it as "not populated — superseded by USB-C-to-micro-USB panel-mount pigtail."

Add a new line item for the pigtail adapter. Example:

> **USB-C panel mount to micro-USB male pigtail — ~$6-10**
> 15-30 cm USB 2.0 pigtail with a panel-mount USB-C female on one end and a micro-USB male plug on the other. Required so the user-visible port on the back panel is USB-C while the ESP32 module's native connector stays micro-USB. Must carry both USB 2.0 data (for firmware flashing) and sufficient current for the clock's worst-case draw; look for 22-24 AWG conductors on the power pair.

## 3.3: Verify the AITRIP module's USB input can carry system current

One remaining open question: does the AITRIP ESP-WROOM-32 have a polyfuse on its USB VBUS input? Some cheap clones do (often 500 mA), others route VBUS straight through. A 500 mA fuse will nuisance-trip when LEDs + audio run together.

When parts arrive, inspect the module under a magnifier near the micro-USB connector:
- Small 0603 / 0805 yellow or green component in series with VBUS: polyfuse (bad for us).
- Zero-ohm jumper or direct trace: fine.
- A small SMD diode: Schottky for reverse-polarity protection, fine.

If a polyfuse is present, either (a) bridge it with a solder blob and a bit of wire, (b) replace it with a larger-rated polyfuse, or (c) re-introduce a power-only 5V inlet on the PCB (a 2-pin JST-XH or screw terminal) that feeds the +5V rail directly, leaving the module's micro-USB for data-only. This decision should be made before committing to the gerbers for fab.

## 3.4: Plan the back-panel cutout location

The ESP32 module is at PCB position (73, −72.5) with 180° rotation on the bottom side. The micro-USB connector faces parallel to the PCB surface (toward an edge, not toward the back panel).

Two options:
1. **Cutout in a frame strip** — breaks the "frame is a bare shell" decision; requires re-ordering the frame. **Avoid.**
2. **Internal pigtail routes inside the case** — the micro-USB male end of the panel-mount pigtail plugs directly into the module's connector, and the USB-C female end is mounted in the back panel at whatever position is most convenient. This is the intended approach. The pigtail is a short internal cable, fully hidden.

Pick the back-panel USB-C mounting position in the back-panel SVG design (tracked separately in `TODO.md` / back panel design task). Keep the pigtail reach in mind (15-30 cm gives plenty of slack for any placement).

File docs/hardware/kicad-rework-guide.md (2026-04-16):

# KiCad Rework Guide — Fix LED chain order + AT position + finish PCB

**Starting state:** Schematic has 35 WS2812B LEDs with a partial data chain wired in the wrong order. PCB has all 35 LEDs placed at correct grid positions, power rails partially routed, and a half-done data chain. AT LED is at the wrong physical position (95.76, 116.28) — needs to move to (150.48, 157.32).

**End state:** Data chain wired in physical row-major order (left-to-right, top-to-bottom on the clock face). AT on row 11. Power rails complete. All traces routed. DRC clean. Gerbers exportable.

## Current progress — 2026-04-15

- ✅ Part 1 (schematic) complete — chain re-wired by Value name, ERC clean
- ✅ Part 2 (PCB) complete through step 2.11 — AT moved, data chain routed, all connections closed, GND pour on both sides, DRC clean (0 errors, 0 unconnected pads), gerbers + drill + BOM + CPL exported
- ⏸️ **Step 2.10 deferred:** 1:1 print verification not yet done (printer in sleeping kid's room — do in the morning)
- ⏸️ **Step 2.13 pending:** JLCPCB submission — waiting on 2.10 print check as final sanity gate before ordering

Commit `405864a` has all PCB source files. Fabrication outputs regenerated locally as needed; gitignored.

**Resume here after print check.**

**Key principle:** Schematic layout is for human readability only — it does NOT affect the PCB. Don't rearrange symbols on the schematic sheet. The physical PCB positions come from the X,Y coordinate table. The chain order comes from how you wire DOUT→DIN. D-numbers are cosmetic silkscreen labels.

---

# Part 1: Fix the schematic

## 1.1: Delete ALL data-chain wiring

Delete every wire or label connecting any LED's DOUT to any LED's DIN. Also delete the wire from R1 to the first LED's DIN.

How to identify data-chain wires: they connect DOUT of one WS2812B symbol to DIN of another. They do NOT touch VDD or VSS pins.

**Leave alone:** any wire between VDD and a +5V port, or VSS and a GND port. Only delete DOUT↔DIN connections.

When done, every LED should have:
- VDD still connected to `+5V` ✓
- VSS still connected to `GND` ✓
- DIN floating (no connection) ✓
- DOUT floating (no connection) ✓

## 1.2: Wire the data chain by Value name

**Do NOT rearrange symbols on the sheet.** Your current layout is fine. Find each LED by its **Value** label and wire DOUT→DIN in this exact sequence:

```
R1 output
  → LED_IT
  → LED_IS
  → LED_TEN_MIN
  → LED_HALF
  → LED_QUARTER
  → LED_TWENTY
  → LED_FIVE_MIN
  → LED_MINUTES
  → LED_HAPPY
  → LED_PAST
  → LED_TO
  → LED_ONE
  → LED_BIRTH
  → LED_THREE
  → LED_ELEVEN
  → LED_FOUR
  → LED_DAY
  → LED_TWO
  → LED_EIGHT
  → LED_SEVEN
  → LED_NINE
  → LED_SIX
  → LED_TWELVE
  → LED_NAME
  → LED_FIVE_HR
  → LED_TEN_HR
  → LED_OCLOCK
  → LED_NOON
  → LED_IN
  → LED_THE
  → LED_MORNING
  → LED_AFTERNOON
  → LED_AT
  → LED_EVENING
  → LED_NIGHT (DOUT → no-connect, press Q)
```

Each `→` means: wire previous LED's DOUT to next LED's DIN.

**If two LEDs are neighbors on the sheet:** draw a wire (**W**).
**If two LEDs are far apart on the sheet:** use matching labels (**L**). Example: place label `CHAIN_8` on LED_MINUTES DOUT and the same label `CHAIN_8` on LED_HAPPY DIN. They're connected without a wire crossing the sheet.

34 connections total.

## 1.3: Verify R1 is connected

R1 (300Ω) sits between 74HC245 B0 output and the first LED in the chain:
- One terminal: `LED_DATA_5V` label (from 74HC245 B0)
- Other terminal: connected to LED_IT's DIN (first `→` in the chain above)

If R1 got disconnected during cleanup, re-wire it.

## 1.4: Re-annotate (cosmetic only)

**Tools → Annotate Schematic** → Reset existing + Sort by Y then X → Annotate.

Whatever D-numbers KiCad assigns are fine. They're silkscreen labels, not functional. The firmware mapping table handles WordId→chain-position translation regardless of what D-number each LED gets.

## 1.5: Run ERC

Same ignorable warnings as before. No new errors should appear.

## 1.6: Save and plot

- **Cmd-S** to save.
- **File → Plot → PDF** to regenerate `word-clock.pdf`.

---

# Part 2: Fix the PCB

## 2.1: Update PCB from Schematic

Open PCB Editor. **Tools → Update PCB from Schematic (F8).**

This pushes the new chain wiring and any new D-numbers to the PCB. Physical footprint positions stay where they are. Click **Update PCB**.

## 2.2: Move the AT LED to its new position

Find the LED with Value `LED_AT` on the front side (currently near position 95.76, 116.28).

1. Click it.
2. Press **E**.
3. Set:
   - **X:** 150.48
   - **Y:** 157.32
   - **Side:** Front
   - **Orientation:** 0°
4. Click OK.

## 2.3: Delete ALL LED data-chain traces on the PCB

Every trace that was part of the LED DOUT→DIN chain. These are thin signal traces (0.25mm) on F.Cu connecting LED pads on the front side.

**Do NOT delete:**
- Wide +5V power traces (0.5mm+)
- GND pour / GND traces
- Any backside signal traces (I2C, SPI, I2S, buttons)

Click each data trace → **Delete**. Or: right-click a data trace → **Select → All Tracks in Net** → Delete.

## 2.4: Delete power traces to AT LED's OLD position

The AT LED moved. Its old position (95.76, 116.28) has +5V and GND traces going to empty space now. Find and delete those dangling trace segments.

## 2.5: Route +5V to AT LED's new position

1. Press **X** (start trace), set width to 0.5mm.
2. Click on AT LED's VDD pad at (150.48, 157.32).
3. Route to the nearest existing +5V trace or via.
4. Press **Escape**.

GND: the ground pour (step 2.8) will connect AT's VSS pad automatically. No manual GND trace needed if you do the pour.

## 2.6: Route the data chain — serpentine by Value

Press **X**, set width to 0.25mm. Route in this physical order across the front side of the board:

**Row 0 (Y=6.84):** left to right
- R1 output pad → LED_IT DIN (via from B.Cu to F.Cu needed here — R1 is on the back)
- LED_IT DOUT → LED_IS DIN
- LED_IS DOUT → LED_TEN_MIN DIN
- LED_TEN_MIN DOUT → LED_HALF DIN

**Row 0→1 jump:**
- LED_HALF DOUT (150.48, 6.84) → LED_QUARTER DIN (47.88, 20.52)

**Row 1 (Y=20.52):**
- LED_QUARTER DOUT → LED_TWENTY DIN

**Row 1→2 jump:**
- LED_TWENTY DOUT (136.80, 20.52) → LED_FIVE_MIN DIN (27.36, 34.20)

**Row 2 (Y=34.20):**
- LED_FIVE_MIN DOUT → LED_MINUTES DIN

**Row 2→3 jump:**
- LED_MINUTES DOUT (116.28, 34.20) → LED_HAPPY DIN (47.88, 47.88)

**Row 3 (Y=47.88):**
- LED_HAPPY DOUT → LED_PAST DIN
- LED_PAST DOUT → LED_TO DIN

**Row 3→4 jump:**
- LED_TO DOUT (150.48, 47.88) → LED_ONE DIN (20.52, 61.56)

**Row 4 (Y=61.56):**
- LED_ONE DOUT → LED_BIRTH DIN
- LED_BIRTH DOUT → LED_THREE DIN

**Row 4→5 jump:**
- LED_THREE DOUT (143.64, 61.56) → LED_ELEVEN DIN (41.04, 75.24)

**Row 5 (Y=75.24):**
- LED_ELEVEN DOUT → LED_FOUR DIN
- LED_FOUR DOUT → LED_DAY DIN

**Row 5→6 jump:**
- LED_DAY DOUT (157.32, 75.24) → LED_TWO DIN (20.52, 88.92)

**Row 6 (Y=88.92):**
- LED_TWO DOUT → LED_EIGHT DIN
- LED_EIGHT DOUT → LED_SEVEN DIN

**Row 6→7 jump:**
- LED_SEVEN DOUT (143.64, 88.92) → LED_NINE DIN (27.36, 102.60)

**Row 7 (Y=102.60):**
- LED_NINE DOUT → LED_SIX DIN
- LED_SIX DOUT → LED_TWELVE DIN

**Row 7→8 jump:**
- LED_TWELVE DOUT (136.80, 102.60) → LED_NAME DIN (34.20, 116.28)

**Row 8 (Y=116.28):**
- LED_NAME DOUT → LED_FIVE_HR DIN

**Row 8→9 jump:**
- LED_FIVE_HR DOUT (136.80, 116.28) → LED_TEN_HR DIN (20.52, 129.96)

**Row 9 (Y=129.96):**
- LED_TEN_HR DOUT → LED_OCLOCK DIN
- LED_OCLOCK DOUT → LED_NOON DIN

**Row 9→10 jump:**
- LED_NOON DOUT (150.48, 129.96) → LED_IN DIN (27.36, 143.64)

**Row 10 (Y=143.64):**
- LED_IN DOUT → LED_THE DIN
- LED_THE DOUT → LED_MORNING DIN

**Row 10→11 jump:**
- LED_MORNING DOUT (129.96, 143.64) → LED_AFTERNOON DIN (61.56, 157.32)

**Row 11 (Y=157.32):**
- LED_AFTERNOON DOUT → LED_AT DIN

**Row 11→12 jump:**
- LED_AT DOUT (150.48, 157.32) → LED_EVENING DIN (47.88, 171.00)

**Row 12 (Y=171.00):**
- LED_EVENING DOUT → LED_NIGHT DIN
- LED_NIGHT DOUT: leave unconnected (end of chain).

If two traces need to cross on the same layer: press **V** while routing to insert a via, cross on B.Cu, via back to F.Cu.

## 2.7: Route remaining backside signals (if not already done)

Skip this step if you already routed these. All on B.Cu, 0.25mm width unless noted:

| Signal | From | To |
|---|---|---|
| `I2C_SDA` | ESP32 GPIO21 | DS3231 SDA |
| `I2C_SCL` | ESP32 GPIO22 | DS3231 SCL |
| `I2S_BCLK` | ESP32 GPIO26 | MAX98357A BCLK |
| `I2S_LRC` | ESP32 GPIO25 | MAX98357A LRC |
| `I2S_DIN` | ESP32 GPIO27 | MAX98357A DIN |
| `SD_CS` | ESP32 GPIO5 | microSD CS |
| `SD_MOSI` | ESP32 GPIO23 | microSD MOSI |
| `SD_MISO` | ESP32 GPIO19 | microSD MISO |
| `SD_SCK` | ESP32 GPIO18 | microSD SCK |
| `BTN_HOUR` | ESP32 GPIO32 | SW1 → GND |
| `BTN_MINUTE` | ESP32 GPIO33 | SW2 → GND |
| `BTN_AUDIO` | ESP32 GPIO14 | SW3 → GND |
| `LED_DATA_3V3` | ESP32 GPIO13 | 74HC245 A0 |
| `LED_DATA_5V` | 74HC245 B0 | R1 input |
| `+5V main feed` | USB-C VBUS | C7 → branches (1.0mm width) |
| `+3V3` | ESP32 3V3 pin | DS3231 VCC (0.5mm width) |

## 2.8: Pour ground planes on both sides

**Place → Filled Zone.** Select **F.Cu**. Draw rectangle covering entire board. Set net to `GND`. OK.

Repeat for **B.Cu** — same rectangle, same GND net.

Press **B** to refill all zones. Handles all GND connections automatically.

## 2.9: Run DRC

**Inspect → Design Rules Checker → Run DRC.**

Fix violations:
- **Clearance:** move traces apart
- **Unconnected nets:** route the missing connection
- **Silkscreen on pad:** move text

Target: 0 errors. USB-C pad warnings are fine.

## 2.10: Print LED layout at 1:1

**File → Plot.** Layers: F.Cu + F.SilkS + Edge.Cuts only. Scale: **1:1.** Plot.

Print at actual size. Overlay on a 7"×7" grid to verify LED positions match word centers.

## 2.11: Export gerbers

**File → Fabrication Outputs → Gerbers:**
- Layers: F.Cu, B.Cu, F.Paste, B.Paste, F.SilkS, B.SilkS, F.Mask, B.Mask, Edge.Cuts
- Plot.

**Generate Drill Files:** Millimeters, decimal, PTH+NPTH single file.

**Component Placement:** File → Fabrication Outputs → Component Placement → CSV.

**BOM:** Tools → Generate Legacy BOM → CSV.

```bash
cd hardware
zip gerbers.zip *.gbr *.gbrjob *.drl
```

## 2.12: Commit

```bash
cd /Users/samueldacanay/dev/personal/word-clock-for-my-daughters
git add hardware/
git commit -m "fix(hardware): row-major led chain, AT relocated, pcb complete"
git push
```

## 2.13: Stop for review

Send me the commit SHA. I'll review against the position table and chain order before you submit to JLCPCB.

---

# Reference: LED position table

Physical positions on the 7"×7" (177.8mm) board. Each LED centered under its word.

| WordId | Grid (row, col, len) | X (mm) | Y (mm) |
|---|---|---:|---:|
| IT | 0, 0, 2 | 13.68 | 6.84 |
| IS | 0, 3, 2 | 54.72 | 6.84 |
| TEN_MIN | 0, 6, 3 | 102.60 | 6.84 |
| HALF | 0, 9, 4 | 150.48 | 6.84 |
| QUARTER | 1, 0, 7 | 47.88 | 20.52 |
| TWENTY | 1, 7, 6 | 136.80 | 20.52 |
| FIVE_MIN | 2, 0, 4 | 27.36 | 34.20 |
| MINUTES | 2, 5, 7 | 116.28 | 34.20 |
| HAPPY | 3, 1, 5 | 47.88 | 47.88 |
| PAST | 3, 6, 4 | 109.44 | 47.88 |
| TO | 3, 10, 2 | 150.48 | 47.88 |
| ONE | 4, 0, 3 | 20.52 | 61.56 |
| BIRTH | 4, 3, 5 | 75.24 | 61.56 |
| THREE | 4, 8, 5 | 143.64 | 61.56 |
| ELEVEN | 5, 0, 6 | 41.04 | 75.24 |
| FOUR | 5, 6, 4 | 109.44 | 75.24 |
| DAY | 5, 10, 3 | 157.32 | 75.24 |
| TWO | 6, 0, 3 | 20.52 | 88.92 |
| EIGHT | 6, 3, 5 | 75.24 | 88.92 |
| SEVEN | 6, 8, 5 | 143.64 | 88.92 |
| NINE | 7, 0, 4 | 27.36 | 102.60 |
| SIX | 7, 4, 3 | 75.24 | 102.60 |
| TWELVE | 7, 7, 6 | 136.80 | 102.60 |
| NAME | 8, 0, 5 | 34.20 | 116.28 |
| FIVE_HR | 8, 8, 4 | 136.80 | 116.28 |
| TEN_HR | 9, 0, 3 | 20.52 | 129.96 |
| OCLOCK | 9, 3, 6 | 82.08 | 129.96 |
| NOON | 9, 9, 4 | 150.48 | 129.96 |
| IN | 10, 1, 2 | 27.36 | 143.64 |
| THE | 10, 3, 3 | 61.56 | 143.64 |
| MORNING | 10, 6, 7 | 129.96 | 143.64 |
| AFTERNOON | 11, 0, 9 | 61.56 | 157.32 |
| AT | 11, 10, 2 | 150.48 | 157.32 |
| EVENING | 12, 0, 7 | 47.88 | 171.00 |
| NIGHT | 12, 8, 5 | 143.64 | 171.00 |

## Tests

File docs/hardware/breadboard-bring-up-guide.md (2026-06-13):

# Breadboard Bring-Up Guide

> **⚠ HISTORICAL — completed breadboard phase (2026-04-20).** This records the
> breadboard bring-up that validated every subsystem before the PCB. It is kept
> for reference but is **not current production guidance**: the design has since
> moved to a **63-LED board** (not 25) and **uncompressed WAV audio**
> (`lullaby1.wav` / `lullaby2.wav` / `birth.wav`, not the MP3 test sketches
> shown below). For on-PCB bring-up follow `firmware/test/hardware_checks/*.md`
> and `docs/hardware/pre-fab-review.md`.

How to take the Phase 2 parts order and validate every subsystem on a
breadboard before committing to the final PCB. Step-by-step, one peripheral
at a time, with known-good test sketches.

**Read first:**
- `docs/hardware/pinout.md` — pin assignments, power budget, and the
  **pre-power smoke test protocol** (multimeter checks before any power
  is applied). The pin numbers in this guide reference pinout.md.
- `docs/hardware/usb-c-breakout-removal-guide.md` — context on how power
  flows on the final PCB (breadboard uses the breakout; PCB doesn't).
- `docs/hardware/phase-2-parts-list.md` — what each part is and why it's
  chosen. Every peripheral below assumes those parts specifically.

**Use this doc as** the bench procedure. Run each section in order;
each builds on the last.

---

## Breadboard primer (read this if it's been a while)

A breadboard is a plastic block full of holes with metal clips hidden
underneath. Pushing a component lead or jumper wire into a hole makes an
electrical contact. Which holes are electrically tied together depends
on their position, not on anything you do — the wiring is baked into
the board.

### What's connected to what

There are two kinds of hole groups:

1. **Power rails** (also called "buses") — the long strips that run
   along the outer edges, marked with a red `+` line and a blue/black
   `-` line. Every hole in the same colored column is a single long
   wire. Connect your power source to one hole and you've powered the
   entire column. These are for distributing +V and GND across the
   board.

2. **Terminal strips** — the main field in the middle, with the long
   center gutter running down the length. Each **row of 5 holes** on
   one side of the gutter is tied together. Rows are **independent of
   each other** (row 1 is not connected to row 2). The gutter
   **breaks** the connection, so the 5 holes on the left of the gutter
   are NOT connected to the 5 holes on the right of the same row.
   (That gutter is there so DIP chips — like the 74HCT245 in Step 5 —
   can straddle it with legs on each side in independent rows.)

### How to connect two things

Either put both leads in the **same group** of connected holes (same
power-rail column, or the same 5-hole row on one side of the gutter),
or run a **jumper wire** from one group to another. Jumper wires are
short pre-stripped wires that plug into two holes at once.

### How to power the board

Pick one source (here: the USB-C breakout's 5V/GND pads). Run two
jumpers from the source to the `+` and `-` columns of the rail you're
going to use. Now every 5V peripheral can grab power from any hole in
the `+` column and every GND can come from any hole in the `-` column.

Same trick for 3.3V: after the ESP32 brings up its onboard regulator,
jumper the ESP32's `3V3` pin to a **different** rail column so 5V and
3.3V don't collide. All `-` (GND) columns get bridged together with a
jumper — one shared ground for the whole board.

### Ground rules (literal)

- **One common GND.** Every peripheral's GND goes to the same `-` rail.
  Tie all `-` columns together with a jumper. 90% of "it's not working"
  on a breadboard is a missing GND connection.
- **Disconnect USB before rewiring.** Don't rearrange live wires — a
  stray lead brushing the wrong hole can instantly fry a regulator or
  a dev board.
- **Leads push straight in.** Friction holds them. If a lead is too
  thick or too thin to stay put, use a jumper or trim the lead.
- **Double-check polarity before powering up.** Reversed +/- on the
  rail will cook polarized parts (electrolytic caps, ICs, the ESP32
  itself). The smoke test in `pinout.md` catches this before power
  goes on.

---

## Workspace setup

### Breadboard layout (the salvaged dual-bus board, ~2400 tie points)

This particular board is a **dual-bus** layout: two independent
breadboard sections stacked top-and-bottom, each with its own pair of
power rails on each side. Four rail pairs total: Va / Vb (top section)
and Vc / Vd (bottom section).

```
 top    section:  [ Va+ Va- | rows 1..~30 | gutter | rows ~30..60 | Vb+ Vb- ]
 bottom section:  [ Vc+ Vc- | rows 1..~30 | gutter | rows ~30..60 | Vd+ Vd- ]
```

Read the diagram as: the leftmost two columns (`Va+`, `Va-`) are a pair
of power rails running the full length of the top section. The main
terminal field is next, split by the center gutter. Then another pair
of power rails on the right (`Vb+`, `Vb-`). Bottom section is the same
layout again with its own rail labels.

Assign power rails consistently across the whole session:
- **Va+ → 5V** (from USB-C breakout's 5V pad)
- **Va- → GND**
- **Vb+ → 3.3V** (from ESP32 dev board's 3V3 pin)
- **Vb- → GND** (same GND as Va-; tie them together with a jumper)
- **Vc, Vd rails** — leave free for peripheral-specific rails, or bridge to
  the main rails as needed.

**Before plugging anything in:** jumper `Va-` ↔ `Vb-` ↔ `Vc-` ↔ `Vd-`
so all four ground rails are the same GND. Do this first and leave it
for the whole bring-up.

### ESP32 dev board placement

Straddle the breadboard's center split with the ESP32 dev board.
Pins on each side of the board land in the outer 5 rows on each half
of the breadboard. USB-C port points off the edge so the cable doesn't
block breadboard rows.

### Shared rules (all sketches)

- All sketches compile with PlatformIO `[env:emory]` or any Arduino-IDE
  setup targeting ESP32-WROOM-32.
- **Serial monitor at 115200 baud** throughout.
- Ground everything to one common GND. Every peripheral's GND pin goes to
  the same rail. Floating grounds cause 90% of "it doesn't work" moments.
- **Disconnect power between wiring changes.** Don't rearrange live.

---

## Step 1 — ESP32 alone

**Goal:** confirm the USB-C path delivers stable 5V, the 3.3V regulator on
the dev board is working, and the flashing toolchain talks to the chip.

### Wiring

Only the USB-C breakout and the ESP32.

| From | To |
|---|---|
| USB-C breakout 5V | Va+ |
| USB-C breakout GND | Va- (and Vb-) |
| ESP32 VIN (or 5V pin) | Va+ |
| ESP32 GND | Va- |
| ESP32 3V3 pin | Vb+ |

### Sketch: `01_blink.cpp`

Most ESP32 dev boards have a blue onboard LED on GPIO 2.

```cpp
#include <Arduino.h>

void setup() {
  Serial.begin(115200);
  Serial.println("ESP32 alive");
  pinMode(2, OUTPUT);
}

void loop() {
  digitalWrite(2, HIGH);
  delay(500);
  digitalWrite(2, LOW);
  delay(500);
  Serial.println("blink");
}
```

### Expected

- On-board blue LED blinks at 1 Hz.
- Serial monitor prints `ESP32 alive` once, then `blink` every second.
- Multimeter: 3V3 pin reads 3.30 V ± 0.1 V.

### If it fails

- No LED, no serial: double-check USB-C breakout's CC resistors (5.1kΩ
  each to GND). Without those, many chargers won't supply 5V.
- Serial garbage: baud rate mismatch — set 115200.
- Flash fails with "timed out waiting for packet header": hold the BOOT
  button on the ESP32 dev board while flashing, release when flashing
  starts.

---

## Step 2 — DS3231 RTC (I²C)

**Goal:** confirm I²C works, the DS3231 is alive at address `0x68`, and
the battery-charging circuit has been disabled.

**Prerequisite:** complete pinout.md step 3 (remove the 200Ω charging
resistor, install CR2032). Do NOT skip this — the module ships with a
trickle-charger that can vent a non-rechargeable CR2032.

### Wiring

| From | To | Rail |
|---|---|---|
| DS3231 VCC | ESP32 3V3 | Vb+ |
| DS3231 GND | GND | Va- |
| DS3231 SDA | ESP32 GPIO 21 | — |
| DS3231 SCL | ESP32 GPIO 22 | — |

The ZS-042 module has onboard SDA/SCL pullups (4.7k-10kΩ). Do not add
external pullups for breadboard bring-up — the internal ones are enough.

### Sketch: `02_i2c_scan.cpp`

```cpp
#include <Arduino.h>
#include <Wire.h>

void setup() {
  Serial.begin(115200);
  Wire.begin(21, 22);  // SDA, SCL
  delay(100);

  Serial.println("I2C scan:");
  int count = 0;
  for (uint8_t addr = 1; addr < 127; addr++) {
    Wire.beginTransmission(addr);
    if (Wire.endTransmission() == 0) {
      Serial.printf("  found 0x%02X\n", addr);
      count++;
    }
  }
  Serial.printf("done — %d device(s)\n", count);
}

void loop() {}
```

### Expected

```
I2C scan:
  found 0x57
  found 0x68
done — 2 device(s)
```

- `0x68` is the DS3231 itself.
- `0x57` is the onboard AT24C32 EEPROM (comes with the ZS-042 module).
  Not used by firmware but confirms the module is wired correctly.

### If it fails

- No devices found: GND is probably not shared, or SDA/SCL are swapped.
- Only 0x68 found (no 0x57): the EEPROM chip on this specific clone is
  missing or dead — functionally fine, but note for repair planning.
- Multiple devices at unexpected addresses: you probably have something
  else on the I²C bus; disconnect it.

### Set + read time sketch (optional sanity check)

```cpp
#include <Arduino.h>
#include <Wire.h>
#include <RTClib.h>

RTC_DS3231 rtc;

void setup() {
  Serial.begin(115200);
  Wire.begin(21, 22);
  if (!rtc.begin()) { Serial.println("no RTC"); return; }
  if (rtc.lostPower()) {
    Serial.println("RTC lost power; setting time from compile");
    rtc.adjust(DateTime(F(__DATE__), F(__TIME__)));
  }
}

void loop() {
  DateTime now = rtc.now();
  Serial.printf("%04d-%02d-%02d %02d:%02d:%02d\n",
                now.year(), now.month(), now.day(),
                now.hour(), now.minute(), now.second());
  delay(1000);
}
```

Requires `adafruit/RTClib` in `lib_deps` (already in `esp32-base`).

Expected: prints incrementing timestamp once per second. Power off the
ESP32 (keep CR2032 installed), leave overnight, power on next day with the
"set time from compile" line commented out → time should have advanced
correctly. Confirms the RTC keeps running on battery.

---

## Step 3 — microSD breakout (VSPI)

**Goal:** confirm SPI works, the SD card is detected, and the FAT32
filesystem reads.

### Wiring

| From | To | Rail |
|---|---|---|
| microSD VCC | 5V | Va+ |
| microSD GND | GND | Va- |
| microSD CS | ESP32 GPIO 5 | — |
| microSD MOSI | ESP32 GPIO 23 | — |
| microSD MISO | ESP32 GPIO 19 | — |
| microSD SCK | ESP32 GPIO 18 | — |

Power the breakout from **5V**, not 3.3V — its onboard regulator + level
shifter chain need the higher input.

Insert a FAT32-formatted card with `lullaby.mp3` and `birth.mp3` at root
(per the audio-format decision in `TODO.md`).

### Sketch: `03_sd_list.cpp`

```cpp
#include <Arduino.h>
#include <SPI.h>
#include <SD.h>

void setup() {
  Serial.begin(115200);
  if (!SD.begin(5)) {  // CS pin
    Serial.println("SD init failed");
    return;
  }
  Serial.println("SD init ok");

  File root = SD.open("/");
  File f = root.openNextFile();
  while (f) {
    Serial.printf("  %s  %lu bytes\n", f.name(), f.size());
    f = root.openNextFile();
  }
  Serial.println("done");
}

void loop() {}
```

### Expected

```
SD init ok
  lullaby.mp3  2453120 bytes
  birth.mp3  487936 bytes
done
```

### If it fails

- `SD init failed`: check wiring (MOSI/MISO often swapped). Confirm card
  is FAT32, not exFAT. Cards >32 GB default to exFAT — reformat.
- Init OK but no files listed: card is readable but empty. Check the
  files are actually at the root, not in a subfolder.
- Random corrupt file listings: the microSD breakout might not be
  getting a stable 5V. Measure the breakout's VCC pin while running; if
  it dips below 4.5V, bulk-cap the 5V rail or switch USB power sources.

---

## Step 4 — MAX98357A + speaker (I²S)

**Goal:** confirm I²S audio path works end-to-end.

**Prereq:** speaker is JST-PH2.0 pre-attached (DWEII 4-pack from the parts
order). Plug directly into the MAX98357A's speaker output terminals.

### Wiring

| From | To | Rail |
|---|---|---|
| MAX98357A Vin | 5V | Va+ |
| MAX98357A GND | GND | Va- |
| MAX98357A DIN | ESP32 GPIO 27 | — |
| MAX98357A BCLK | ESP32 GPIO 26 | — |
| MAX98357A LRC | ESP32 GPIO 25 | — |
| MAX98357A SD | (leave unconnected) | — |
| MAX98357A GAIN | (leave unconnected) | — |

- SD pin floating → stereo-average channel (what we want for mono).
- GAIN pin floating → 9 dB gain (default).

### Sketch: `04_tone.cpp`

Simple 440 Hz square wave using ESP-IDF I²S driver. Arduino-ESP32 core
v2.x uses the legacy `driver/i2s.h` API; if using v3.x, the API is
different and the sketch below will need updating.

```cpp
#include <Arduino.h>
#include <driver/i2s.h>
#include <math.h>

constexpr int SAMPLE_RATE = 44100;
constexpr int FREQ = 440;

void setup() {
  Serial.begin(115200);
  Serial.println("I2S tone test");

  i2s_config_t cfg = {
    .mode = (i2s_mode_t)(I2S_MODE_MASTER | I2S_MODE_TX),
    .sample_rate = SAMPLE_RATE,
    .bits_per_sample = I2S_BITS_PER_SAMPLE_16BIT,
    .channel_format = I2S_CHANNEL_FMT_RIGHT_LEFT,
    .communication_format = I2S_COMM_FORMAT_STAND_I2S,
    .intr_alloc_flags = 0,
    .dma_buf_count = 8,
    .dma_buf_len = 256,
    .use_apll = false,
    .tx_desc_auto_clear = true,
  };
  i2s_driver_install(I2S_NUM_0, &cfg, 0, nullptr);

  i2s_pin_config_t pins = {
    .bck_io_num = 26,
    .ws_io_num = 25,
    .data_out_num = 27,
    .data_in_num = I2S_PIN_NO_CHANGE,
  };
  i2s_set_pin(I2S_NUM_0, &pins);
}

void loop() {
  static float phase = 0;
  const float step = 2.0f * M_PI * FREQ / SAMPLE_RATE;
  int16_t buf[256];
  for (int i = 0; i < 256; i += 2) {
    int16_t s = (int16_t)(sinf(phase) * 8000);
    buf[i]   = s;  // L
    buf[i+1] = s;  // R
    phase += step;
    if (phase > 2.0f * M_PI) phase -= 2.0f * M_PI;
  }
  size_t written;
  i2s_write(I2S_NUM_0, buf, sizeof(buf), &written, portMAX_DELAY);
}
```

### Expected

- Clean 440 Hz tone out of the speaker (A above middle C — same pitch as
  an orchestra tuning reference).
- Steady amplitude, no crackle, no buzz.

### If it fails

- Silent: check DIN, BCLK, LRC are on the right GPIOs and not swapped.
  I²S is picky about which line is which.
- Crackly / distorted: Vin might be below 5V under load. Measure while
  playing. If dipping below 4.2V, bulk-cap the 5V rail (470 µF–1000 µF
  electrolytic) near the MAX98357A.
- Tone plays but at wrong pitch: sample rate mismatch between the I²S
  driver setup and the sketch — check the `SAMPLE_RATE` constant.
- Buzz during silence (long `delay()` in a future version): I²S DMA
  buffer underruns. Keep feeding the driver continuously.

### Optional: play lullaby.mp3 from SD

Once tone works, the natural next test is decoding the actual MP3 files
off the SD card. The ESP8266Audio library is the standard choice:

```
lib_deps = earlephilhower/ESP8266Audio
```

Sketch skeleton (don't bother until the `audio` firmware module is being
written — the smoke test above is enough to prove the I²S hardware):

```cpp
#include <AudioGeneratorMP3.h>
#include <AudioFileSourceSD.h>
#include <AudioOutputI2S.h>

AudioFileSourceSD *src;
AudioGeneratorMP3 *mp3;
AudioOutputI2S *out;

void setup() {
  SD.begin(5);
  src = new AudioFileSourceSD("/lullaby.mp3");
  out = new AudioOutputI2S();
  out->SetPinout(26, 25, 27);  // BCLK, LRC, DIN
  mp3 = new AudioGeneratorMP3();
  mp3->begin(src, out);
}

void loop() {
  if (mp3->isRunning()) mp3->loop();
}
```

---

## Step 5 — WS2812B LEDs + 74HCT245 level shifter

**Goal:** confirm the 3.3V → 5V level-shift path works and the strip
addresses cleanly.

**Prereqs (all critical — see pinout.md):**
- **Bulk cap first:** a 1000 µF electrolytic across the strip's +5V and
  GND inputs, installed BEFORE power is applied. Skipping this can fry
  the first LED on first power-on.
- **Level shifter required:** 74HCT245 (or 74HCT125) on the data line.
  The ESP32's 3.3V logic HIGH is below the WS2812B's 3.5V threshold —
  sometimes works, sometimes doesn't, never reliably.
- **Series resistor on data line:** 300-470 Ω between the level shifter
  output and the strip's DIN pin. Protects the first LED from edge-rate
  spikes on startup.

### Wiring (74HCT245 in unidirectional mode, A → B)

| From | To | Rail |
|---|---|---|
| 74HCT245 pin 20 (VCC) | 5V | Va+ |
| 74HCT245 pin 10 (GND) | GND | Va- |
| 74HCT245 pin 1 (DIR) | 5V (VCC) | — |
| 74HCT245 pin 19 (/OE) | GND | — |
| 74HCT245 pin 2 (A1) | ESP32 GPIO 13 (through 300Ω optional) | — |
| 74HCT245 pin 18 (B1) | WS2812B DIN (through 300Ω series) | — |
| WS2812B VDD | 5V (separate thick wire, 18 AWG+) | Va+ |
| WS2812B GND | GND (separate thick wire) | Va- |
| 1000 µF cap (+) | WS2812B VDD | — |
| 1000 µF cap (-) | WS2812B GND | — |

Route the LED's 5V/GND on thick wire (18 AWG) directly to the USB power
source, not through the breadboard rails — breadboard contact resistance
sags under the strip's inrush current.

Start with **just 1 LED** cut from the 5m strip. You can always add more;
starting with the full strip on breadboard is asking for trouble.

### Sketch: `05_fastled.cpp`

```cpp
#include <Arduino.h>
#include <FastLED.h>

constexpr int PIN_DATA = 13;
constexpr int NUM_LEDS = 1;

CRGB leds[NUM_LEDS];

void setup() {
  Serial.begin(115200);
  FastLED.addLeds<WS2812B, PIN_DATA, GRB>(leds, NUM_LEDS);
  FastLED.setBrightness(10);  // low brightness for bench work
}

void loop() {
  leds[0] = CRGB::Red;    FastLED.show(); delay(500);
  leds[0] = CRGB::Green;  FastLED.show(); delay(500);
  leds[0] = CRGB::Blue;   FastLED.show(); delay(500);
  leds[0] = CRGB::Black;  FastLED.show(); delay(500);
}
```

### Expected

- LED cycles R → G → B → off at 2 Hz.
- Colors are clean (not pink where it should be red — that indicates
  color channel ordering is wrong; change `GRB` to `RGB` or vice versa).

### If it fails

- No light at all:
  - Multimeter on the strip's VDD pin: should read 5.0 V. If lower,
    check the USB source can supply enough current.
  - Probe the 74HCT245's A1 pin (input) with a scope or logic probe:
    should see the WS2812B's 800 kHz data pulses during `FastLED.show()`.
  - Probe B1 (output): same signal at 5V amplitude.
- First LED lights but not subsequent ones:
  - Almost always a cold joint between LEDs or the 300Ω resistor in the
    wrong place (it should be in series between the level shifter and
    the FIRST LED's DIN, not between LEDs).
- All LEDs flicker or show wrong colors:
  - Ground loop. Confirm every GND meets at one point, and that the
    thick LED GND wire connects back to the USB source's GND, not just
    the breadboard rail.
- First LED is noticeably dim or discolored after first power-on:
  - The bulk cap was missed or wired backwards. Swap for a new strip
    piece (that LED may be damaged) and install the cap properly.

### Scaling up

Once 1 LED works:
- Cut a 5-LED strip. Verify the `leds[]` array size matches, all 5
  light correctly, no flicker.
- Cut a 25-LED strip (the production count). Confirm the whole chain
  works at low brightness, then gradually increase to 255. Watch for
  voltage sag — the last LEDs in the chain may tint red or drop out if
  the strip can't deliver full current along its length.

---

## Step 6 — Buttons (tact switches)

**Goal:** confirm buttons read clean and the ESP32's INPUT_PULLUP works.

### Wiring

3 × 6mm tact switches. Each switch has 4 pins arranged in a 2×2 grid;
diagonally-opposite pins are the same contact when pressed.

| Button | ESP32 GPIO |
|---|---|
| Hour-set | 32 |
| Minute-set | 33 |
| Audio play/stop | 14 |

For each button: one leg to the GPIO, the opposite-corner leg to GND.
No external pullup resistor — the ESP32's INPUT_PULLUP does it.

### Sketch: `06_buttons.cpp`

```cpp
#include <Arduino.h>

constexpr int PIN_HOUR = 32;
constexpr int PIN_MIN  = 33;
constexpr int PIN_AUD  = 14;

void setup() {
  Serial.begin(115200);
  pinMode(PIN_HOUR, INPUT_PULLUP);
  pinMode(PIN_MIN,  INPUT_PULLUP);
  pinMode(PIN_AUD,  INPUT_PULLUP);
}

void loop() {
  int h = digitalRead(PIN_HOUR);
  int m = digitalRead(PIN_MIN);
  int a = digitalRead(PIN_AUD);
  Serial.printf("H=%d  M=%d  A=%d\n", h, m, a);
  delay(100);
}
```

### Expected

- Unpressed: all three print `H=1  M=1  A=1` (pulled up to 3.3V).
- Pressed: the corresponding value reads 0.

### If it fails

- Always reads 1 even when pressed: wrong diagonal pins used on the
  switch; try the other pair.
- Always reads 0: the other pair of pins is wired — you've got one leg
  on GPIO and another leg also on GND from the same contact side, short
  to GND.
- Noisy / bouncy reads: to be handled by a debounce routine in the
  `buttons` firmware module; for this smoke test, raw reads are fine.

---

## Step 7 — Full integration

All peripherals on the breadboard at once. Flash the real firmware
(wifi_provision + future display/rtc/ntp/audio/buttons modules).

### Wiring summary (all on at once)

Combine everything from Steps 1–6 without changes. The only integration
concern is **power rail capacity**: running all peripherals at once under
load (LEDs at 100%, audio playing, WiFi transmitting) can pull over 2 A
from the USB source.

Mitigations if sag is observed:
- Cap LED brightness at 60% in firmware until PCB-level power delivery
  is proven.
- Bulk-cap the 5V rail near the LED strip (the existing 1000 µF cap
  should be enough).
- Swap to a 5V/3A USB source instead of 2A during bring-up if sag
  persists.

### Firmware to flash

Once every peripheral has passed isolation, flash the current Emory env:

```
cd firmware && ~/Library/Python/3.9/bin/pio run -e emory -t upload
```

The wifi_provision module (already shipped) will come up first-boot,
broadcast `WordClock-Setup-XXXX`, and wait for credentials. See
`firmware/test/hardware_checks/wifi_provision_checks.md` for the 10-step
post-flash verification.

Each subsequent Phase 2 firmware module (display, rtc, ntp, audio,
buttons) will land with its own hardware check file under
`firmware/test/hardware_checks/`. Run each after the module ships.

---

## Troubleshooting reference

### "It worked at step N-1 and stopped working at step N"

Common cause: adding peripheral N pulled ESP32's 3V3 regulator below spec
or flooded a shared bus. Pull peripheral N back off, confirm step N-1
still works, then re-add N one wire at a time.

### "Random resets under load"

Power sag. Measure 5V rail with a multimeter during the failure. If it
dips below 4.5V, the USB source can't keep up — cap the rail or switch
sources.

### "ESP32 won't flash"

Hold BOOT while initiating flash; release when the progress bar starts.
The AITRIP module doesn't have auto-reset circuitry as reliable as
Adafruit boards.

### "Serial garbage on boot"

ROM bootloader output at 74880 baud gets printed to serial on every boot
— harmless. Your application output at 115200 comes after. Set monitor
to 115200 and ignore the first few chars.

### "Intermittent LED glitches"

90% of the time: ground loop or missing level shifter. Confirm both are
correct. 10%: bad WS2812B LED mid-strip — cut it out, resolder.

### "SD card mounts once, then won't mount again after reset"

ESP32's SD library sometimes leaves the card in an undefined state if
the last operation wasn't closed cleanly. Power-cycle the card (not just
the ESP32) — the easiest way is `SD.end()` before reset, or unplug the
microSD breakout between runs during bench work.

---

## What to bring back to `TODO.md`

When each step passes, check the corresponding box in the TODO's
"Breadboard bring-up" section. When all 7 steps pass, the whole
breadboard gate is green and the PCB submission window opens. Document
any deviations (e.g., "had to use 470Ω series instead of 300Ω for WS2812B
— ran out of 300Ω") so the PCB rework captures them.

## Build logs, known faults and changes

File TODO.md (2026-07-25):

# Word Clock — Remaining Work

Living working list of what's left. Supersedes the archived phase-by-phase
roadmap (`docs/archive/specs/2026-04-15-activity-blocking-graph.md`).

## Status update (2026-07-12) — EMORY ASSEMBLED AND RUNNING

Board #1 is inside the enclosure, closed up (carrier plate dry-fit, no
glue), on the wall-of-Dad's-desk running bench firmware: WiFi + NTP + RTC
+ display + audio all verified on the assembled clock. Physical Audio
button proven by ear; Hour/Min sim-verified (identical circuit; physical
press declined to avoid skewing time — accepted). Night dim raised
0.10 → 0.25 after viewing through the real face (2026-07-12).

**Emory's remaining punch list:**
- [ ] Captive-portal persist bug (below) — fix, then strip TEMP bench code
      from `main.cpp`, flash production, re-provision via the real portal
      (doubles as the Hour+Audio 10 s combo's first physical test)
- [ ] Decide wall-hang vs shelf placement — no hanging provision exists,
      and the clock can't hang flush (button caps sit 2.5 mm proud of the
      back panel; cable exits the back). Shelf needs nothing; wall needs
      a French cleat or equivalent standoff
- [x] Audio loaded AND verified by ear 2026-07-25 — I am kind / 3 Little
      Birds / HBD (Dad's order), staged WAVs canonicalized + peak
      normalized by `sd_load.py`, all CRC-verified on card. Lullabies
      and birth.wav both confirmed audible. Oct 6 deadline satisfied;
      first live fire will be the real test. Clock delivered to her
      room 2026-07-25.
- [ ] 30-day burn-in (running in her room since 2026-07-25)
- [ ] G2 note: first-light bleed at the U1/U2/SW2 bridge keyholes not yet
      formally assessed — eyeball at night and tape on the PCB if needed

**Nora's build punch list:**
- [x] Assembled and brought up 2026-07-25 — first flash onto the
      factory-fresh module required a full `esptool erase_flash` (AT
      firmware NVS residue silently blocked WiFi association; clean
      erase fixed it, note for any future fresh module). WiFi → NTP →
      RTC → words verified (live frame matched host oracle at 12:35);
      audio loaded (I am kind / Take on Me / HBD, normalized,
      CRC-verified) and confirmed by ear after reseating a loose
      speaker ground wire found at first audio check.
- [ ] Her 30-day burn-in
- [ ] RTC coin-cell persistence spot check: after her next unplugged
      move, confirm the boot log does NOT say "DS3231 lost power"
      (her cell has not yet been proven across a power gap)

## Status (2026-06-13)

| Workstream | State |
|---|---|
| **Firmware** | **Done.** 183/183 native Unity tests green; both `emory`/`nora` ESP32 envs build. Drives the **63-LED board** via per-word `LedSpan{start,count}` mapping (long words light 2–3 adjacent LEDs), audio is a **two-track lullaby playlist** (`lullaby1.wav` → `lullaby2.wav`, auto-advancing) with the **birthday message interrupting** an in-progress lullaby, LED power capped at **1700 mA** (FastLED, sized for a 3 A USB-C supply). |
| **PCB** | **63-LED board ordered from JLCPCB 2026-06-07** — 5 boards, full PCBA (top-side, Economic). Only the 63 SMD LEDs are machine-placed; **all THT is hand-soldered on arrival.** LED substituted to **WS2812B-V6 (LCSC C52917433)** — see `hardware/fab/README.md`. Canonical KiCad source + as-ordered fab package now committed. **Awaiting delivery.** |
| **April 35-LED board** | Fabbed but **obsolete** — physical boards exist, superseded by the 63-LED respin. Not used. |
| **Enclosure** | **Built.** Frames glued (both clocks), faces glued to frames, light channel printed. Remaining enclosure work is integrating the PCB into it (see finish line). |
| **Audio assets** | **Not yet recorded.** Need `lullaby1.wav` + `lullaby2.wav` + `birth.wav` per kid, 16-bit PCM 44.1 kHz mono LE, at SD root. Re-recordable up to delivery (2030/2032) — non-blocking. |
| **Supplies** | A handful of assembly consumables still to buy — see "Still to buy". |

## The finish line (board-gated)

Everything below waits on the 63-LED boards arriving. Once they do, in order:

1. **Hand-solder THT** on each board: ESP32 module, RTC / SD / amp right-angle
   headers, U2 (74HCT245), R1, C2 + the 100 nF decoupling caps, buttons.
2. **Pre-power smoke test** per `docs/hardware/pinout.md` §Pre-power smoke test:
   multimeter checks, inspect the AITRIP module for a VBUS polyfuse (bridge if
   present — see `docs/archive/hardware/2026-04-17-usb-c-breakout-removal.md`),
   DS3231 trickle-charge resistor stays in place (locked 2026-04-20, see
   `docs/hardware/pinout.md` §1 — inert at 3.3V, mitigated by the 5-year
   battery-swap cadence), MAX98357A pin sanity.
3. **Bench checks on the real board** (details below).
4. **Flash `emory` firmware**, verify captive-portal provisioning, time-to-words,
   buttons (hour/min/audio + the 10 s Hour+Audio captive-reset combo), and audio.
5. **✅ DONE 2026-07-06 — light channel v4 printed (PETG) and fits board #1.**
   The 2026-06 print
   failed dry-fit on board #1 (2026-07-05): its pockets predate the 63-LED
   layout, and its flat underside rides up on THT pin stubs.
   `enclosure/3d/light_channel.py` (v4, first-principles rework) keeps the
   original pure-void honeycomb and adds essentially nothing: blind relief
   cavities (5 mm deep) at every pin, one merged slot per daughtercard
   header row (bent-flat socket tails spread laterally), and 25 low wall
   JOGS — 2 mm ribs only 6 mm tall that route walls around pins, straight
   wall untouched above. 9 small notches remain at the U1/U2 pin fences
   and SW2 (build prints WARNINGs; no thin wall can cross a 2.54 mm pin
   fence) — assess at G2, black tape on the PCB if visible. Pad/LED data:
   `hardware/word-clock-tht-pads.csv` + `word-clock-led-pos.csv`
   (regenerate via `enclosure/3d/export_tht_pads.py`). Orientation: the
   chamfered corner (tab on the coupon) goes to the D1 / IT-IS corner; do
   NOT flip the part in the slicer; supports OFF. Workflow: print the
   coupon first (`--coupon`), dry-fit, then the full part: black PETG,
   PCB-side down, brim, ~6-8 h. Old prints superseded. Note
   `hardware/word-clock-all-pos.csv` is stale (35-LED era) — regenerate or
   delete when convenient.
6. **Integrate the PCB into the (already-built) enclosure**: PCB standoffs, seat
   the light channel, apply diffusion film to the face back, drill the cable port
   6 → 16 mm, install the P-clip strain relief, fit the back panel (M3 wood
   screws into the frame wall). Sequence: `docs/hardware/assembly-plan.md`.
7. **Record + load the audio WAVs** (can happen any time — parallel track).
8. **Emory 30-day burn-in** — real-time; watch thermal, audio crackle, RTC drift,
   WiFi reconnection.
9. **Build Nora** with every fix learned from Emory baked in.

## On delivery — bench checks (the biggest coverage gap)

All firmware bench work so far was on a breadboard with a single LED. The real
board closes the "does it actually look right" question. Sketches live in
`firmware/test/hardware_checks/`.

- [x] **D1 glows RED / GRB color order** — `display_checks.md`. Confirms the
      level-shifter + first-LED data path and the GRB color order before trusting
      anything else. *Passed 2026-07-04 on board #1 via the 05_fastled sketch
      (63-LED rev): D1 red alone, full 63-LED chain walk clean, all-on dim red
      at 600 mA laptop cap. WS2812B-V6 substitution confirmed GRB.*
- [~] **Full 63-LED all-on brightness + power** — WAIVED 2026-07-12 with the
      clock assembled: production firmware's worst frame (birthday rainbow +
      decor) lights ~30 LEDs ≈ 40% of the 1700 mA cap, and the 2026-07-04
      600 mA all-on bench check plus assembled-clock operation showed no
      droop. Revisit only if brightness ever increases.
- [x] **Per-word LED walk** — confirm the firmware `kSpans` table matches the
      physical chain (each word lights its own letters, no neighbors). This is
      the on-hardware check behind the `test_spans_partition_the_chain` unit test.
      *Passed 2026-07-05 on board #1: live-rendered frames at 13:29/13:30 matched
      a host-compiled oracle (same pure-logic sources) index-for-index, and the
      2026-07-04 chain walk proved every physical LED lights at its index.
      Letter-alignment through the actual face still gets eyeballed at enclosure
      integration (assembly-plan G2).*
- [ ] **Captive-portal persist bug (OPEN, needs phone)** — two bench attempts on
      2026-07-05 (submit → "waiting for audio" → press Audio) ended with NVS still
      empty and the clock back in ApActive after reboot. Bench work continued via
      the TEMP `BENCH_BACKDOOR_SSID` credential inject in `main.cpp`, but the real
      portal flow MUST be debugged with a phone before Emory ships. Suspects: the
      per-AP submit rate limit (b988959) blocking re-submits, or the 60 s
      confirmation timeout racing the user. Repro: watch serial during a live
      phone provisioning session.
- [ ] **WiFi radio isolation** — the softap-only sketch (committed) if provisioning
      misbehaves, to separate radio bring-up from the rest.

## Still to buy

- [ ] **Nylon M2 + M2.5 screw/nut assortment** (with washers, lengths to
      ~12 mm) — single-point securing for the SD (M2) and RTC (M2.5)
      daughtercards on both clocks; PCB NPTHs are mirrored so only one
      hole per card aligns (see `docs/hardware/daughtercards.md` erratum).
      Emory's cards are currently held by header friction alone.

**Board THT passives — never purchased (gate the first bench check; order now).**
The April inventory predates the 35→63-LED respin and the on-PCB decoupling
work, so these were never bought. Quantities are for two clocks.

- [ ] **74HCT245, DIP-20 ×2** (buy 4–5 for spares) — the LED level shifter; D1
      won't light without it. HCT family specifically, not HC.
- [ ] **100nF ceramic disc caps ×44** (buy a 100-pack) — 22 per board, one per
      IC Vcc. Footprint `C_Disc_D5.0mm_W2.5mm_P5.00mm`.
- [ ] **1000µF / 10V radial electrolytic ×2** (buy spares) — C2 bulk cap; skipping
      it risks frying LEDs on first power-up.
- [ ] **300 Ω axial resistor** — R1 LED-data series resistor; verify the salvaged
      assortment has it or buy a pack (470 Ω is an acceptable fallback).

**Enclosure consumables (shipping lead time — order now).**

- [ ] **M3 wood screws, 1/2" + 5/8" pan-head** — back-panel-into-frame-wall.
- [ ] **5/8" step drill bit (HSS, 1/4" hex)** — drill cable port 6 → 16 mm.
- [ ] **Cable P-clip, ~5 mm OD** — internal USB strain relief.
- [ ] **Titebond III** — face-to-frame joint (do NOT substitute 5-min epoxy here).
- [ ] **USB-C-to-USB-C cable, 3–6 ft** — one per clock (the captive cable;
      the delivered ESP32 modules turned out to have USB-C, not micro-USB —
      confirmed on the bench 2026-07-07).

## Parallel tracks (non-blocking, re-doable)

- [ ] **Voice-memo recording** — Dad's voice for the birthday message (Emory
      6:10 PM, Nora 9:17 AM). Re-recordable up to delivery.
- [ ] **Lullaby recording** — two tracks per kid (`lullaby1.wav`, `lullaby2.wav`).

## Architecture — locked decisions (reference)

- **Frame is a bare shell**; all exterior features live on the back panel.
- **Buttons press through the back panel** (PCB tact switches are bottom-side;
  Hour / Min / Audio labels engraved next to each hole).
- **Captive portal is a custom `DNSServer` + `WebServer` + NVS** implementation
  (not WiFiManager) — supply-chain control + per-kid palette. Shipped in
  `firmware/lib/wifi_provision/`.
- **USB: captive USB-C-to-USB-C cable** (module port is USB-C) permanently inside the clock, exiting
  a back-panel hole drilled 6 → 16 mm at assembly; strain relief via internal
  P-clip, not the grommet.
- **Back panel removable** via 4 × M3 wood screws into the 6.4 mm hardwood frame
  wall at the 4 mm-inset corners (pre-drill ~2 mm pilots). Handles the 40-year
  CR2032-replacement cadence (~8 open/close cycles).
- **Daughterboards** (DS3231, HW-125) plug in via right-angle 1×6 female sockets
  so they lie parallel to the main board; geometry enforces orientation.
- **Diffuser stack is film-only** (no opal acrylic) — bench-validated 2026-04-26;
  acrylic caused ~5 mm lateral light bleed. Acrylic shelved as a backup.
- **Speaker mount**: 2 × M3 hex spacers epoxied to the back panel (no printed
  cradle); the speaker's integral flanges screw onto the spacer tops.
- **Power/ground plane split**: B.Cu is a solid +5V plane; GND rides the F.Cu
  zone with short F.Cu jumpers (no B.Cu GND plane). See CLAUDE.md.

## Open decisions

- **Master BOM is stale + untracked.** CLAUDE.md calls `hardware/word-clock.csv`
  the source of truth, but it is gitignored AND stale — it lists the old 35-LED
  topology (D1–D35, includes a D7) with empty LCSC columns. The only current BOM
  is the LED-only `hardware/fab/word-clock-bom.csv` (63 designators, D7 removed).
  Regenerate a complete 63-LED master BOM from the KiCad source (with LCSC part
  numbers for a JLC reorder), then track it.
- ~~**Light-channel top-edge seal**~~ — DECIDED 2026-07-07: none. Channel
  walls press directly on the film; foam/putty held only as a G2 retrofit
  if bleed ever shows.
- **Back-panel screw head** — pan-head (sits proud, simple) vs countersunk
  (needs countersinking the 3.2 mm panel). Order both lengths, decide at assembly.
- **Wall-hang vs shelf** — see the Emory punch list above; undecided and
  physically consequential (proud button caps + rear cable exit).

## Coverage gaps carried forward

Not exercisable until hardware/dates allow:

- **Birthday auto-fire** at the birth minute (NVS-gated, once/year) — unit-tested
  (`test_audio_fire_guard`), not hardware-verified.
- **Birthday rainbow + decor words** (HAPPY/BIRTH/DAY/NAME) — needs the date or an
  RTC fast-forward; renderer is golden-tested.
- **Holiday palette** + **stale-sync amber tint** (>24 h since NTP) — pure-logic
  tested; need date rollover / 24 h disconnected.
- **WiFi drop + reconnect**, **SD absent/corrupt**, **validation-failure UX**,
  **multi-device captive AP**, **AP 10-min timeout**, **confirmation 60 s
  timeout** — state-machine tested; low priority, verify opportunistically.
- **30-day burn-in on Emory** — real-time, gated post-assembly.

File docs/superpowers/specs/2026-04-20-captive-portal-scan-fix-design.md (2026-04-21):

# Captive portal scan fix

**Status:** v2 — shipped 2026-04-20; §Bench verification findings added after on-device testing uncovered additional defects
**Scope:** delta against shipped `2026-04-16-captive-portal-design.md`. That doc remains the captive portal's design of record; this doc covers the changes shipped on 2026-04-20 and the rationale behind each.

## Problem

On bench bring-up (2026-04-20) of the shipped `wifi_provision` module, the captive portal's SSID dropdown never populated — it stayed stuck at the placeholder "Scanning for networks…". Two additional issues surfaced:

1. Only one device could be connected to the AP at a time, blocking the "switch from phone to laptop if troubleshooting" workflow.
2. The browser-side JS fires `/scan` exactly once. If the first request returns before the ESP32's async scan completes, the dropdown shows "No networks found — try again" with no actual retry path; the user has to know to reload the page.

## Root causes

### RC1 — `WiFi.mode(WIFI_AP)` disables station-mode scanning

`firmware/lib/wifi_provision/src/wifi_provision.cpp:105`:
```cpp
WiFi.mode(WIFI_AP);
```

In pure AP mode, `WiFi.scanNetworks()` does not function. It either times out (blocking mode) or returns a failure code (async mode). Confirmed via:

- [Arduino-ESP32 issue #8916: "ESP32 AP+STA and scanNetworks fails if STA not connected"](https://github.com/espressif/arduino-esp32/issues/8916)
- [ESP32 Forum: "Wifi AP scanning in AP mode"](https://esp32.com/viewtopic.php?t=2582)
- [Arduino Forum discussion](https://forum.arduino.cc/t/can-esp32-execute-a-scan-while-a-client-is-connected-to-its-ap/1259238)

The radio must have the STA side active to execute a scan; `WIFI_AP_STA` dual mode is the correct configuration.

### RC2 — `max_connection = 1` rejects a second client

`firmware/lib/wifi_provision/src/wifi_provision.cpp:111`:
```cpp
/* ssid_hidden = */ 0, /* max_connection = */ 1);
```

Only one client can connect to the AP at a time. During breadboard troubleshooting (2026-04-20), the user's laptop connected first, and the phone was unable to connect until the laptop disconnected. Raising to 4 accommodates multi-device provisioning (Mac + phone both attached during setup, or troubleshooting by device-switching).

### RC3 — Browser-side `/scan` has no polling

`firmware/assets/captive-portal/form.html.template:40-63`:
```javascript
fetch('/scan').then(r => r.json()).then(nets => { ... });
```

Fires exactly once on page load. The ESP32's async `WiFi.scanNetworks()` typically takes ~5 s to complete; plus the server's 10 s cooldown on back-to-back scans, the first client-side `/scan` often lands on a still-running scan and receives `[]`. Current JS renders "No networks found — try again" in that case with no interactive retry — the user must manually reload the page.

## Changes

### Change 1 — `WIFI_AP` → `WIFI_AP_STA`

Single-line edit in `wifi_provision.cpp:105`:

```diff
- WiFi.mode(WIFI_AP);
+ WiFi.mode(WIFI_AP_STA);
```

### Change 2 — `max_connection = 1` → `4`

Single-line edit in `wifi_provision.cpp:111`:

```diff
-             /* ssid_hidden = */ 0, /* max_connection = */ 1);
+             /* ssid_hidden = */ 0, /* max_connection = */ 4);
```

### Change 3 — `/scan` polling loop in form JS

Replace the one-shot fetch in `form.html.template:40-63` with a polling state machine:

- **Interval:** 2000 ms between `/scan` requests.
- **Timeout:** 30000 ms (15 attempts) of empty/failed responses before giving up.
- **Stop condition:** first non-empty response stops polling; dropdown stays populated for the rest of the session. Important because the server's `handle_scan()` calls `WiFi.scanDelete()` after returning results — a subsequent poll would return `[]` and, without this stop condition, erase the populated dropdown.
- **Timeout handling:** replace the dropdown contents with "No networks found — click Refresh" and inject a visible `<button>Refresh networks</button>` that, when clicked, restarts polling from zero.
- **Fetch errors:** transient network failures are treated the same as empty responses — they don't terminate polling until the 30-second timeout.

Full JS replacement is specified in the implementation plan; design excerpt shown in [review context](#design-excerpt-js-polling-loop).

## Non-goals

Explicitly **out of scope** for this delta:

- **Manual SSID entry fallback.** Useful for hidden SSIDs and robustness against scan-system regressions, but adds meaningful UI complexity. User deferred.
- **Scan-interrupts-AP beacon mitigation.** In `WIFI_AP_STA` mode, `WiFi.scanNetworks()` briefly pauses AP beacons. Existing 10-second cooldown (`SCAN_COOLDOWN_MS`) already throttles this, and stop-on-success polling further limits total scan calls to ~1-2 per session. Watch for actual disconnect symptoms during testing — not pre-emptively mitigated.
- **Refactoring `handle_scan()` for C++ native testability.** Would require extracting pure response-building from WiFi-integrated code. High refactor cost for limited gain (the WiFi-integration side is what actually failed and native tests can't cover that anyway). Skipped.

## Regression analysis

### State machine transitions — no impact

Walked the state machine (`state_machine.cpp`) and `wifi_provision.cpp` transition flows. All transitions into/out of AP-active states call `start_ap()` and `stop_ap()` which now correctly set `WIFI_AP_STA` (on enter) and `WIFI_STA` (on exit to validating/online). Transitions that stay within AP states (e.g., AwaitingConfirmation → ApActive on confirm timeout) do not re-call `start_ap()`, so no mode bounce.

| Transition | Mode before | Mode after | Impact |
|---|---|---|---|
| Boot → ApActive | — | `WIFI_AP_STA` (new) | ✓ |
| ApActive → AwaitingConfirmation | `WIFI_AP_STA` | `WIFI_AP_STA` | no change |
| AwaitingConfirmation → Validating | `WIFI_AP_STA` | `WIFI_STA` (via `stop_ap()`) | unchanged |
| Validating → Online | `WIFI_STA` | `WIFI_STA` | unchanged |
| Validating → ApActive (fail) | `WIFI_STA` | `WIFI_AP_STA` (new) | ✓ |
| Online → StaConnecting (WiFi drop) | `WIFI_STA` | `WIFI_STA` | unchanged |
| Any → IdleNoCredentials | AP or STA | `WIFI_STA` (via `stop_ap()`) | unchanged |

### AP broadcast stability — acceptable residual risk

`WiFi.scanNetworks()` briefly interrupts AP beacon activity during its ~5 s window. Mitigations:

- Existing `SCAN_COOLDOWN_MS = 10000` throttles scans to once per 10 s.
- Stop-on-success polling in Change 3 means ~1-2 scans per provisioning session in the typical path.
- Modern TCP clients recover from transient link loss via retry.

Residual risk is [LOW]; not pre-emptively mitigated. Manual hardware check #10 covers the specific scenario.

### Build-time HTML generation — survives

`gen_form_html.py` collapses the template to a single line via `_collapse_newlines()` and emits a C++ raw string literal. The new JS must:

- Use no `//` line comments (would consume the rest of the collapsed line) — verified in spec.
- Not introduce `{{...}}` sequences that would conflict with template substitution tokens — verified (single `{`/`}` for JS blocks only).
- Not introduce the raw-string delimiter `)WCHTML` — verified (trivially).

Structural pytest coverage (Tier 1 below) catches regressions on all three.

### Python pytest suite (`test_gen_form_html.py`) — passes unchanged

Reviewed all 6 existing tests. None inspect JS internals. All continue to pass after Change 3.

### Native C++ test suite (`test_wifi_*`) — passes unchanged

All four test suites (`state_machine`, `form_parser`, `credential_validator`, `tz_options`) test pure logic. None touch WiFi mode, web server, or scan. All continue to pass.

## Testing plan

Three layers.

### Tier 1 — structural pytest (required)

Add to `firmware/assets/captive-portal/tests/test_gen_form_html.py`:

- `test_polling_interval_is_2000ms` — regex for `POLL_INTERVAL_MS = 2000`
- `test_polling_timeout_is_30s` — regex for `TIMEOUT_MS = 30000`
- `test_polling_stops_on_nonempty_result` — regex for `if (nets.length > 0)` + `clearTimeout`
- `test_timeout_shows_refresh_button` — regex for `Refresh networks` button path
- `test_no_single_line_comments_in_js` — scans the template for `//` patterns outside string literals; would break `_collapse_newlines`
- `test_generated_js_syntactically_valid` — runs `node --check` on the extracted JS in the preview output (requires Node.js available in CI, which PlatformIO already needs)

Rationale: structural checks catch accidental constant-edit or logic-deletion regressions. Cheap, no new dependencies beyond what's already in the build.

### Tier 2 — Playwright behavior tests (required)

Add `firmware/assets/captive-portal/tests/test_form_behavior.py` using `playwright` + `pytest-playwright`:

- `test_dropdown_populates_on_immediate_success` — mock `/scan` returns 4 networks immediately; assert dropdown shows 4 options.
- `test_dropdown_populates_after_polling` — mock returns `[]` twice, then networks on the third call; assert dropdown populates within ~6 s.
- `test_timeout_shows_refresh_button` — mock returns `[]` forever; assert "Refresh networks" button is present after 30 s.
- `test_refresh_button_restarts_polling` — after timeout, click refresh; mock switches to returning networks; assert dropdown populates.
- `test_polling_stops_after_success` — mock returns networks on first call; assert only 1-2 `/scan` requests are made over 10 s (no extraneous polls); dropdown is NOT reset to empty.

Rationale: Tier 1 only verifies structure is present. Tier 2 verifies the state machine actually behaves. Adds `playwright` + `pytest-playwright` as dev dependencies and `playwright install chromium` as a setup step. Worth it for a 40-year keepsake.

### Tier 3 — manual hardware checks

Append to `firmware/test/hardware_checks/wifi_provision_checks.md`:

```
## 8. Multi-device connection (max_connection=4 regression)
- [ ] Connect laptop to WordClock-Setup-XXXX.
- [ ] Without disconnecting laptop, connect phone to same SSID.
- [ ] Expected: both devices show as connected; form loads on phone too.

## 9. Scan dropdown populates (WIFI_AP_STA regression)
- [ ] Load form on a fresh boot. Wait up to 30 sec.
- [ ] Expected: dropdown populates with nearby 2.4 GHz networks.
- [ ] Expected: dropdown does NOT regress to empty after displaying networks.

## 10. Timeout retry path (polling regression)
- [ ] In a location with no 2.4 GHz networks visible (or simulate by
      blocking WiFi), load form.
- [ ] Expected: after 30 sec, dropdown shows "No networks found — click Refresh"
      + visible Refresh button.
- [ ] Click Refresh → polling restarts (verify via serial showing new /scan requests).
```

## Design excerpt (JS polling loop)

For reference — the full drop-in replacement for the one-shot fetch in `form.html.template`:

```javascript
// Poll /scan every 2s until populated or 30s timeout.
const POLL_INTERVAL_MS = 2000;
const TIMEOUT_MS = 30000;
let startedAt = 0;
let timerId = null;

function renderSsidList(nets) {
  const sel = document.getElementById('ssid');
  sel.innerHTML = '';
  const seen = new Set();
  for (const n of nets) {
    if (seen.has(n.ssid)) continue;
    seen.add(n.ssid);
    const opt = document.createElement('option');
    opt.value = n.ssid;
    opt.textContent = n.ssid + (n.secured ? '' : ' (open)');
    sel.appendChild(opt);
  }
}

function renderTimeoutRetry() {
  const sel = document.getElementById('ssid');
  sel.innerHTML = '';
  const opt = document.createElement('option');
  opt.value = '';
  opt.textContent = 'No networks found — click Refresh';
  sel.appendChild(opt);
  const btn = document.createElement('button');
  btn.type = 'button';
  btn.textContent = 'Refresh networks';
  btn.onclick = () => { btn.remove(); startPolling(); };
  sel.parentNode.insertBefore(btn, sel.nextSibling);
}

function pollScanOnce() {
  fetch('/scan').then(r => r.json()).then(nets => {
    if (nets.length > 0) {
      clearTimeout(timerId);
      timerId = null;
      renderSsidList(nets);
      return;
    }
    if (Date.now() - startedAt >= TIMEOUT_MS) {
      renderTimeoutRetry();
      return;
    }
    timerId = setTimeout(pollScanOnce, POLL_INTERVAL_MS);
  }).catch(() => {
    if (Date.now() - startedAt >= TIMEOUT_MS) {
      renderTimeoutRetry();
      return;
    }
    timerId = setTimeout(pollScanOnce, POLL_INTERVAL_MS);
  });
}

function startPolling() {
  startedAt = Date.now();
  pollScanOnce();
}

startPolling();
```

## Files touched

| File | Change |
|---|---|
| `firmware/lib/wifi_provision/src/wifi_provision.cpp` | 2 one-line edits (mode, max_connection) |
| `firmware/assets/captive-portal/form.html.template` | JS block replaced (~40 lines changed) |
| `firmware/assets/captive-portal/tests/test_gen_form_html.py` | 6 new Tier 1 tests appended |
| `firmware/assets/captive-portal/tests/test_form_behavior.py` | NEW — 5 Tier 2 Playwright tests |
| `firmware/assets/captive-portal/tests/requirements.txt` | NEW — `playwright`, `pytest-playwright` |
| `firmware/test/hardware_checks/wifi_provision_checks.md` | 3 new hardware checks appended (#8, #9, #10) |

## Open questions

None.

## Bench verification findings (2026-04-20)

On-device testing of the v1 plan on an iPhone uncovered six additional defects and one design gap. All fixed in the same commit series as the v1 scope. Documented here so the history is traceable; the original spec scope (three changes + testing plan) was correctly implemented and shipped.

### BV1 — CSRF token regenerated on every GET `/`

`render_form()` assigned `current_csrf = rand_hex(16)` on every call, including the one iOS's captive-portal assistant triggers when it re-probes `/hotspot-detect.html` in the background and follows our 302 → `/`. The user's open form tab's CSRF went stale; submit returned 400 "Let's try that again — the form timed out" despite correct input.

**Fix:** seed CSRF once in `web::begin()` and leave it stable for the AP session. Drop the regeneration from `render_form()`. Security impact is negligible — CSRF is scoped to the AP itself, which is the trust boundary for a captive portal.

**Commit:** `8a391a3` — `fix(wifi_provision): stop regenerating CSRF on every form GET`

### BV2 — UI cycling between "Press Audio" page and the form

After submitting, the iOS captive popup periodically re-fetches `/hotspot-detect.html` to detect captive-portal resolution. Our handler 302-redirects to `/`. The popup navigates back to `/` → `handle_root` served the FORM (not the waiting page) → user's "Press Audio" view was replaced with the fresh form every ~30 seconds.

**Fix:** made `handle_root` state-aware. A `submit_accepted` flag (set in `handle_submit`, cleared at each `web::begin()` call) controls which page `/` serves. Once the user has submitted, `/` serves the waiting page regardless of who's requesting it — iOS probes, manual reloads, or direct navigation all land on the stable "Press Audio" view.

**Commit:** `a87b2b2` — `fix(wifi_provision): revert grace window, add state-aware routing`

### BV3 — Mojibake in the waiting page

Em-dashes (`—`) and ellipses (`…`) in the inline HTML for the waiting page rendered as `â€"` and similar on iOS. The hand-rolled HTML didn't declare `<meta charset="utf-8">` and the response lacked a `charset=utf-8` content-type.

**Fix:** added charset header, charset meta tag, and replaced literal em-dash / ellipsis with HTML entities (`&mdash;`, plain `...`) as defense in depth.

**Commit:** `1867457` — `fix(wifi_provision): charset=utf-8 + meaningful ApActive status`

### BV4 — "Ready." default status was meaningless after failure

`confirmation_message()`'s `default:` branch returned "Ready." — displayed to the user when state is `ApActive` after a failed validation. Meaningless; user was confused about what happened.

**Fix:** added an explicit `ApActive` case returning "Didn't connect. Check your password and try again." The `/status` page only polls after a successful form POST, so reaching `ApActive` on that page unambiguously means "returned from failed validation" — safe to say so.

**Commit:** `1867457` (same as BV3)

### BV5 — Grace-window experiment broke STA reliability

Initial attempt to give the user "Connected!" feedback in the browser: keep AP up during `Validating` by using `WIFI_AP_STA` throughout, with a 5-second Online grace window before tearing down the AP. ESP32's AP_STA mode forces both sides onto the STA's channel; when `WiFi.begin()` located the home WiFi on a non-channel-1 channel, the AP was forced to move, dropping the iPhone's association. Worse, the STA connection itself became unreliable on known-good credentials in this mode.

**Fix:** reverted `start_validating()` to the pre-v1 pattern: `stop_ap()` → `WiFi.disconnect(wifioff=true)` → `WiFi.mode(WIFI_STA)` → `WiFi.begin()`. Clean mode transitions, reliable STA.

Compensate for the lost UX feedback by (a) setting `last_error` on validation failure so the form re-renders with "Didn't connect..." when the AP comes back, and (b) rewriting the waiting page to FRONT-LOAD the success signal explanation instead of burying it in fine print.

**Commit:** `a87b2b2`

### BV6 — `VALIDATING_TIMEOUT_MS` (30 s) too tight

A first-try STA handshake occasionally took longer than 30 s on a mildly congested 2.4 GHz band, producing an intermittent "Didn't connect" error. Retry almost always succeeded.

**Fix:** bumped timeout to 60 s. Pure reliability win; no downside on fast networks because success fires as soon as `WiFi.status() == WL_CONNECTED`.

**Commit:** `e829c8f` — `chore: serial_capture helper + bump validation timeout to 60s`

### BV7 — Waiting-page copy buried the success signal

Even with BV2 fixed (no more cycling), the user saw the page vanish on successful provisioning and wasn't sure whether it had worked. The fine-print explanation of "the WordClock-Setup network will disappear from your phone — that's the success signal" was too visually de-emphasized.

**Fix:** rewrote the waiting page with a highlighted success-green panel listing "What happens next" as four numbered steps, including "this page will close by itself — that's the success signal" as step 2. Previous fine-print language preserved but now acts as supporting detail.

**Commit:** `e0be85c` — `feat(captive-portal): rewrite waiting page with explicit success signal`

## Updated files touched list (rolls up v1 + bench-verification commits)

| File | Change |
|---|---|
| `firmware/lib/wifi_provision/src/wifi_provision.cpp` | WIFI_AP_STA, max_connection=4, 60s validation timeout, heartbeat log, last_error on failure |
| `firmware/lib/wifi_provision/src/web_server.cpp` | CSRF-stability, state-aware handle_root, waiting-page rewrite, charset fixes, set_error API |
| `firmware/assets/captive-portal/form.html.template` | `/scan` polling + timeout + Refresh |
| `firmware/assets/captive-portal/gen_form_html.py` | preview mock parameterized + charset-safe injection point |
| `firmware/assets/captive-portal/tests/test_gen_form_html.py` | 6 Tier 1 structural tests |
| `firmware/assets/captive-portal/tests/test_form_behavior.py` | NEW — 5 Tier 2 Playwright tests |
| `firmware/assets/captive-portal/tests/conftest.py` | NEW — Playwright fixtures + local HTTP server |
| `firmware/assets/captive-portal/tests/requirements.txt` | NEW |
| `firmware/scripts/serial_capture.py` | NEW — bench diagnostic helper |
| `firmware/test/hardware_checks/wifi_provision_checks.md` | #11-#13 appended |

## References

- Parent captive-portal spec: `docs/superpowers/specs/2026-04-16-captive-portal-design.md`
- Parent captive-portal plan (archived): `docs/archive/plans/2026-04-16-captive-portal-implementation.md`
- Bench bring-up session context: 2026-04-20. Steps 1-6 of `docs/hardware/breadboard-bring-up-guide.md` passed first-try; Step 7 revealed the original three defects (v1 scope) and surfaced the seven bench-verification findings above. Full provisioning flow verified end-to-end on iPhone with a real home WiFi network.

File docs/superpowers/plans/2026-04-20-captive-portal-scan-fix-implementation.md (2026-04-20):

# Captive Portal Scan Fix Implementation Plan

> **For agentic workers:** REQUIRED SUB-SKILL: Use superpowers:subagent-driven-development (recommended) or superpowers:executing-plans to implement this plan task-by-task. Steps use checkbox (`- [ ]`) syntax for tracking.

**Goal:** Ship three fixes to the shipped `wifi_provision` captive portal: enable station-mode scanning (`WIFI_AP_STA`), raise AP client slots (`max_connection = 4`), and convert the form's one-shot `/scan` fetch into a polling loop with timeout + manual refresh button — so first-time provisioning actually completes.

**Architecture:** Two-line firmware edits in `wifi_provision.cpp` + full JS replacement in `form.html.template`. Test coverage in three layers: structural pytest (regex checks on the generated template), Playwright behavior tests (render the preview, mock `/scan`, assert DOM changes over time), manual hardware checks. Preview mock gets extended so behavior tests can script `/scan` responses across calls.

**Tech Stack:** Arduino-ESP32 core, WebServer, WiFi.softAP, pytest, playwright + pytest-playwright (new dev deps), Node.js (already present; used by the existing PlatformIO toolchain).

---

## Spec reference

Implements `docs/superpowers/specs/2026-04-20-captive-portal-scan-fix-design.md`. Read the spec in full — it pins every decision (2 s polling interval, 30 s timeout, stop-on-success, Refresh button UX, regression scope across the state machine, the rationale for each of the three Tiers of testing). If a decision feels underspecified, re-read the spec before inventing.

## File structure

```
firmware/
  lib/wifi_provision/
    src/wifi_provision.cpp              # MODIFIED (2 one-line edits)
  assets/captive-portal/
    form.html.template                  # MODIFIED (JS block replaced, ~40 lines)
    gen_form_html.py                    # MODIFIED (extend emit_preview mock)
    tests/
      test_gen_form_html.py             # MODIFIED (append 6 Tier 1 tests)
      test_form_behavior.py             # NEW (5 Tier 2 Playwright tests)
      requirements.txt                  # NEW (playwright, pytest-playwright)
      conftest.py                       # NEW (fixture helpers for Playwright)
  test/hardware_checks/
    wifi_provision_checks.md            # MODIFIED (append checks #8, #9, #10)
TODO.md                                 # MODIFIED (mark captive-portal-scan-fix [x])
```

## Build / test verification recipes (used throughout)

Run from repository root unless noted.

- **Structural pytest (Tier 1):**
  `cd firmware/assets/captive-portal && python -m pytest tests/test_gen_form_html.py -v`
  - Baseline before this plan: **6 tests pass**.
  - After Task 5: **12 tests pass** (+ 6 new).

- **Playwright behavior tests (Tier 2):**
  `cd firmware/assets/captive-portal && python -m pytest tests/test_form_behavior.py -v`
  - Baseline: test file does not exist.
  - After Task 10: **5 tests pass**.

- **Native C++ test suite:**
  `cd firmware && pio test -e native`
  - Must remain **172/172 passing** throughout this plan.

- **ESP32 builds (Emory + Nora):**
  `cd firmware && pio run -e emory`
  `cd firmware && pio run -e nora`
  - Must remain green throughout.

Run the relevant checks before every commit.

---

## Task 1: Set up Playwright dev dependencies

Locks the Tier 2 tooling in place before any tests reference it. Adds a `requirements.txt` at the captive-portal test root so future contributors get the same setup.

**Files:**
- Create: `firmware/assets/captive-portal/tests/requirements.txt`

- [ ] **Step 1: Create `requirements.txt`**

Write this file:

```
# Tier 1 (structural) only needs pytest — no extra deps.
# Tier 2 (behavior) needs Playwright for headless browser assertions.
pytest>=8.0
playwright>=1.40
pytest-playwright>=0.5
```

- [ ] **Step 2: Install dependencies locally**

Run:
```bash
cd firmware/assets/captive-portal/tests
pip install -r requirements.txt
playwright install chromium
```

Expected: pip reports install of `pytest`, `playwright`, `pytest-playwright`. `playwright install chromium` downloads ~170 MB on first run (subsequent runs skip); final line says "chromium ... installed" or "already installed".

- [ ] **Step 3: Verify Playwright works**

Run:
```bash
cd firmware/assets/captive-portal/tests
python -c "from playwright.sync_api import sync_playwright; print('ok')"
```

Expected output: `ok` on its own line.

- [ ] **Step 4: Commit**

```bash
git add firmware/assets/captive-portal/tests/requirements.txt
git commit -m "test: add Playwright dev deps for captive portal behavior tests"
```

---

## Task 2: Extend preview mock to support scripted `/scan` responses

The existing preview mock (`emit_preview` in `gen_form_html.py`) injects a `window.fetch = async () => ...` stub that returns a static 4-network list. Tier 2 tests need the mock to return **different responses across calls** (e.g. `[]`, `[]`, networks) and must be scriptable from the test side.

**Approach:** parameterize `emit_preview` to accept an inline JS mock string; default to the current 4-network behavior. Tests pass their own mock string.

**Files:**
- Modify: `firmware/assets/captive-portal/gen_form_html.py` (function `emit_preview`)

- [ ] **Step 1: Read the current `emit_preview` function**

Open `firmware/assets/captive-portal/gen_form_html.py` and locate lines 107-124 (the `emit_preview` function).

- [ ] **Step 2: Extend `emit_preview` signature and default mock**

Replace the existing `emit_preview` function body with:

```python
DEFAULT_PREVIEW_MOCK = """
    <script>
      window.fetch = async () => ({ json: async () => ([
          {ssid: 'HomeWiFi-5G', rssi: -45, secured: true},
          {ssid: 'HomeWiFi-2.4', rssi: -52, secured: true},
          {ssid: 'Neighbor', rssi: -70, secured: true},
          {ssid: 'Guest', rssi: -60, secured: false},
      ])});
    </script>
    """

def emit_preview(kid: str, mock_script: str | None = None) -> str:
    template = TEMPLATE.read_text()
    html = substitute(template, kid,
                      csrf_placeholder="preview-csrf",
                      error_placeholder="")
    mock = mock_script if mock_script is not None else DEFAULT_PREVIEW_MOCK
    return html.replace("</body>", mock + "</body>")
```

- [ ] **Step 3: Re-run existing pytest to confirm no regression**

Run:
```bash
cd firmware/assets/captive-portal && python -m pytest tests/test_gen_form_html.py -v
```

Expected: all 6 existing tests pass (the default behavior is unchanged).

- [ ] **Step 4: Commit**

```bash
git add firmware/assets/captive-portal/gen_form_html.py
git commit -m "test: parameterize preview mock for scripted /scan responses"
```

---

## Task 3: Add `conftest.py` fixtures for Playwright tests

Playwright tests need a helper that serves the rendered preview HTML to the browser. Cleanest approach: serve from a local HTTP server (required because `fetch()` doesn't work on `file://` in Chromium). Use Python's stdlib `http.server` in a background thread, one per test.

**Files:**
- Create: `firmware/assets/captive-portal/tests/conftest.py`

- [ ] **Step 1: Write the conftest**

Create `firmware/assets/captive-portal/tests/conftest.py`:

```python
# firmware/assets/captive-portal/tests/conftest.py
"""Pytest fixtures for Playwright behavior tests.

Renders the captive portal preview HTML with a scriptable /scan mock,
serves it from a local HTTP server (required so fetch() works in
Chromium), and yields the URL.
"""
from __future__ import annotations

import http.server
import socketserver
import sys
import threading
from pathlib import Path
from typing import Callable

import pytest

GEN_DIR = Path(__file__).resolve().parents[1]
sys.path.insert(0, str(GEN_DIR))
import gen_form_html  # noqa: E402

@pytest.fixture
def serve_preview(tmp_path: Path) -> Callable[[str, str | None], str]:
    """Render the preview for a kid + optional mock; return the served URL.

    Tests call `serve_preview(kid='emory', mock_script='<script>...</script>')`
    and get back a URL like http://localhost:<port>/ serving the HTML.
    """
    servers: list[socketserver.TCPServer] = []

    def _serve(kid: str = "emory", mock_script: str | None = None) -> str:
        html = gen_form_html.emit_preview(kid, mock_script)
        doc = tmp_path / f"{kid}.html"
        doc.write_text(html)

        handler = http.server.SimpleHTTPRequestHandler
        handler_factory = _make_handler(tmp_path)
        server = socketserver.TCPServer(("127.0.0.1", 0), handler_factory)
        servers.append(server)
        port = server.server_address[1]
        threading.Thread(target=server.serve_forever, daemon=True).start()
        return f"http://127.0.0.1:{port}/{kid}.html"

    yield _serve

    for s in servers:
        s.shutdown()
        s.server_close()

def _make_handler(root: Path) -> type:
    class QuietHandler(http.server.SimpleHTTPRequestHandler):
        def __init__(self, *args, **kwargs):
            super().__init__(*args, directory=str(root), **kwargs)

        def log_message(self, *args, **kwargs):  # silence stdout noise
            pass

    return QuietHandler
```

- [ ] **Step 2: Commit**

```bash
git add firmware/assets/captive-portal/tests/conftest.py
git commit -m "test: add conftest fixtures for captive portal Playwright tests"
```

---

## Task 4: Write Tier 1 structural pytest (6 new tests)

Structural regression coverage for the polling JS. Each test reads the template file directly and runs regex checks to confirm the expected identifiers / constants / control-flow shapes are present. Catches accidental constant changes or code deletion during future refactors.

These tests are committed **before** the JS changes in Task 8; the ones checking new polling identifiers will **fail** against the current template (that's the red in red-green).

**Files:**
- Modify: `firmware/assets/captive-portal/tests/test_gen_form_html.py` (append tests)

- [ ] **Step 1: Append Tier 1 tests to the end of `test_gen_form_html.py`**

Add this block after the last test (`test_embedded_header_is_valid_c_literal`):

```python
# -----------------------------------------------------------------------------
# Tier 1 structural checks for the /scan polling logic.
# These scan the raw template for expected identifiers; they do NOT execute
# the JS. Tier 2 (test_form_behavior.py) covers actual runtime behavior.
# -----------------------------------------------------------------------------

TEMPLATE_PATH = Path(__file__).resolve().parents[1] / "form.html.template"

def _template_text() -> str:
    return TEMPLATE_PATH.read_text()

def test_polling_interval_is_2000ms():
    """POLL_INTERVAL_MS constant exists and equals 2000."""
    assert re.search(r"POLL_INTERVAL_MS\s*=\s*2000", _template_text()), (
        "POLL_INTERVAL_MS constant missing or changed from 2000"
    )

def test_polling_timeout_is_30s():
    """TIMEOUT_MS constant exists and equals 30000."""
    assert re.search(r"TIMEOUT_MS\s*=\s*30000", _template_text()), (
        "TIMEOUT_MS constant missing or changed from 30000"
    )

def test_polling_stops_on_nonempty_result():
    """Stop-on-success path exists (length>0 check + timer cleared)."""
    text = _template_text()
    assert re.search(r"nets\.length\s*>\s*0", text), \
        "Missing nets.length > 0 stop condition"
    assert "clearTimeout" in text, \
        "Missing clearTimeout call on success path"

def test_timeout_shows_refresh_button():
    """Timeout path creates a visible Refresh button that restarts polling."""
    text = _template_text()
    assert "Refresh networks" in text, "Missing 'Refresh networks' button text"
    assert re.search(r"renderTimeoutRetry", text), \
        "Missing renderTimeoutRetry function"

def test_no_single_line_comments_in_js():
    """//-style comments are forbidden inside <script> — they consume the
    rest of the line after _collapse_newlines() joins everything with spaces."""
    text = _template_text()
    # Extract <script>...</script> body (the template has one script block).
    m = re.search(r"<script>(.*?)</script>", text, re.DOTALL)
    assert m, "Could not locate <script> block in template"
    script_body = m.group(1)
    # Strip string literals (single + double + backtick) before checking for //.
    stripped = re.sub(r'"(?:[^"\\]|\\.)*"', '', script_body)
    stripped = re.sub(r"'(?:[^'\\]|\\.)*'", '', stripped)
    stripped = re.sub(r"`(?:[^`\\]|\\.)*`", '', stripped)
    # Any //... sequence left is a real line comment.
    assert "//" not in stripped, (
        "Found // comment inside <script>; use /* ... */ instead. "
        "// comments break when _collapse_newlines() joins lines with spaces."
    )

def test_generated_js_parses_as_valid_js():
    """Collapsed preview HTML's JS must be syntactically valid.

    Runs `node --check` on the extracted <script> body. This catches
    post-collapse syntax errors — e.g., missing semicolons where ASI fails
    once newlines become spaces.
    """
    import shutil
    import subprocess
    import tempfile

    node = shutil.which("node")
    if node is None:
        pytest.skip("node not available; install Node.js to run this check")

    # Emit a header (which triggers _collapse_newlines), then extract JS.
    with tempfile.TemporaryDirectory() as td:
        header = Path(td) / "form_html.h"
        subprocess.run(
            [sys.executable, str(SCRIPT), "--kid", "emory", "--out", str(header)],
            check=True,
        )
        body = header.read_text()

    # Header contains FORM_HTML raw string; extract the HTML payload.
    m = re.search(r'R"WCHTML\((.*?)\)WCHTML"', body, re.DOTALL)
    assert m, "Could not find raw string literal in generated header"
    collapsed_html = m.group(1)

    # Extract the script body from collapsed HTML.
    ms = re.search(r"<script>(.*?)</script>", collapsed_html, re.DOTALL)
    assert ms, "Collapsed HTML lost its <script> block"
    js_body = ms.group(1)

    # Hand to node --check. Success = exit code 0.
    with tempfile.NamedTemporaryFile("w", suffix=".js", delete=False) as f:
        f.write(js_body)
        js_path = f.name
    try:
        result = subprocess.run(
            [node, "--check", js_path],
            capture_output=True, text=True,
        )
        assert result.returncode == 0, (
            f"node --check failed:\nstderr:\n{result.stderr}\nstdout:\n{result.stdout}"
        )
    finally:
        Path(js_path).unlink()
```

- [ ] **Step 2: Run new tests — expect failures**

Run:
```bash
cd firmware/assets/captive-portal && python -m pytest tests/test_gen_form_html.py -v
```

Expected: the first 6 tests (existing) pass. The 6 new tests mostly FAIL because the polling code doesn't exist yet:
- `test_polling_interval_is_2000ms` — FAIL (no `POLL_INTERVAL_MS`)
- `test_polling_timeout_is_30s` — FAIL (no `TIMEOUT_MS`)
- `test_polling_stops_on_nonempty_result` — FAIL (no `clearTimeout`)
- `test_timeout_shows_refresh_button` — FAIL (no "Refresh networks")
- `test_no_single_line_comments_in_js` — PASS (current JS has no `//` comments either)
- `test_generated_js_parses_as_valid_js` — PASS (current JS is valid)

This mixed result is expected: 2/6 pass on old JS, 4/6 will go green after Task 8.

- [ ] **Step 3: Commit the failing tests**

```bash
git add firmware/assets/captive-portal/tests/test_gen_form_html.py
git commit -m "test: add Tier 1 structural pytest for /scan polling (red)"
```

---

## Task 5: Write Tier 2 test — immediate success path

The simplest Playwright test: mock `/scan` returns networks on the first call; dropdown must populate.

**Files:**
- Create: `firmware/assets/captive-portal/tests/test_form_behavior.py`

- [ ] **Step 1: Create test file with shared mock-builder + first test**

Write `firmware/assets/captive-portal/tests/test_form_behavior.py`:

```python
# firmware/assets/captive-portal/tests/test_form_behavior.py
"""Tier 2 Playwright behavior tests for the /scan polling JS.

Each test injects a scriptable /scan mock into the preview HTML, serves it
from a local HTTP server (see conftest.py), opens it in a headless
Chromium, and asserts DOM state over time.
"""
from __future__ import annotations

import json

from playwright.sync_api import Page, expect

def _make_mock(responses: list[list[dict]], hang: bool = False) -> str:
    """Build a <script> that returns `responses[call_index]` on each /scan.

    Once `responses` is exhausted, repeats the last response. If `hang=True`,
    the fetch Promise never resolves (used to simulate a dead server).
    """
    if hang:
        return "<script>window.fetch = () => new Promise(() => {});</script>"
    encoded = json.dumps(responses)
    return f"""
    <script>
      (function() {{
        const responses = {encoded};
        let i = 0;
        window.fetch = async () => {{
          const payload = responses[Math.min(i, responses.length - 1)];
          i += 1;
          return {{ json: async () => payload }};
        }};
      }})();
    </script>
    """

def test_dropdown_populates_on_immediate_success(serve_preview, page: Page):
    """First /scan returns 4 networks → dropdown shows 4 options within 2 s."""
    mock = _make_mock([[
        {"ssid": "HomeWiFi-5G", "rssi": -45, "secured": True},
        {"ssid": "HomeWiFi-2.4", "rssi": -52, "secured": True},
        {"ssid": "Guest", "rssi": -60, "secured": False},
        {"ssid": "Neighbor", "rssi": -70, "secured": True},
    ]])
    url = serve_preview(kid="emory", mock_script=mock)
    page.goto(url)
    dropdown = page.locator("#ssid")
    expect(dropdown.locator("option")).to_have_count(4, timeout=3000)
    # Spot-check one option text.
    expect(dropdown.locator("option")).to_contain_text(
        ["HomeWiFi-5G", "HomeWiFi-2.4", "Guest (open)", "Neighbor"]
    )
```

- [ ] **Step 2: Run the test — expect failure against old JS**

Run:
```bash
cd firmware/assets/captive-portal && python -m pytest tests/test_form_behavior.py::test_dropdown_populates_on_immediate_success -v
```

Expected: **PASS** on old JS. The old one-shot fetch does populate the dropdown from a non-empty first response. This test protects against regressing that behavior.

If it fails: Playwright setup or fixtures are wrong; fix before continuing.

- [ ] **Step 3: Commit**

```bash
git add firmware/assets/captive-portal/tests/test_form_behavior.py
git commit -m "test: Tier 2 — dropdown populates on immediate scan success"
```

---

## Task 6: Write Tier 2 test — polling after initial empty responses

Second behavior test: mock returns `[]` on calls 1 and 2, networks on call 3. Old JS (one-shot) gets the `[]` and gives up. New JS (polling) waits 2 s, polls again, eventually populates.

**Files:**
- Modify: `firmware/assets/captive-portal/tests/test_form_behavior.py` (append test)

- [ ] **Step 1: Append the test**

Add to the bottom of `test_form_behavior.py`:

```python
def test_dropdown_populates_after_polling(serve_preview, page: Page):
    """Two empty responses then networks → dropdown populates within ~6 s.

    At 2 s poll interval: T0=empty, T2=empty, T4=networks → DOM updates.
    """
    mock = _make_mock([
        [],
        [],
        [
            {"ssid": "Home", "rssi": -50, "secured": True},
            {"ssid": "Other", "rssi": -65, "secured": False},
        ],
    ])
    url = serve_preview(kid="emory", mock_script=mock)
    page.goto(url)
    dropdown = page.locator("#ssid")
    # Playwright's 2-count assertion waits up to `timeout` ms for the DOM.
    # 8000 ms covers two 2-second poll cycles + slack.
    expect(dropdown.locator("option")).to_have_count(2, timeout=8000)
    expect(dropdown.locator("option")).to_contain_text(
        ["Home", "Other (open)"]
    )
```

- [ ] **Step 2: Run the test — expect failure against old JS**

Run:
```bash
cd firmware/assets/captive-portal && python -m pytest tests/test_form_behavior.py::test_dropdown_populates_after_polling -v
```

Expected: **FAIL**. Old JS fetches once, gets `[]`, renders "No networks found — try again" as a single option — never retries.

- [ ] **Step 3: Commit the failing test**

```bash
git add firmware/assets/captive-portal/tests/test_form_behavior.py
git commit -m "test: Tier 2 — dropdown populates after polling (red)"
```

---

## Task 7: Write Tier 2 test — timeout shows Refresh button

Mock returns `[]` forever. After 30 s, dropdown should say "No networks found — click Refresh" and a `<button>Refresh networks</button>` must be visible next to the dropdown.

**Files:**
- Modify: `firmware/assets/captive-portal/tests/test_form_behavior.py` (append test)

- [ ] **Step 1: Append the test**

```python
def test_timeout_shows_refresh_button(serve_preview, page: Page):
    """Empty responses for 30 s → "Refresh networks" button appears."""
    mock = _make_mock([[]])  # repeats [] forever (list has 1 entry, mock repeats last)
    url = serve_preview(kid="emory", mock_script=mock)
    page.goto(url)

    refresh = page.get_by_role("button", name="Refresh networks")
    # 32-second timeout to accommodate the 30s TIMEOUT_MS + poll interval + slack.
    expect(refresh).to_be_visible(timeout=32000)

    dropdown = page.locator("#ssid")
    expect(dropdown.locator("option")).to_have_count(1)
    expect(dropdown.locator("option")).to_contain_text(["click Refresh"])
```

- [ ] **Step 2: Run the test — expect failure against old JS**

Run:
```bash
cd firmware/assets/captive-portal && python -m pytest tests/test_form_behavior.py::test_timeout_shows_refresh_button -v
```

Expected: **FAIL**. Old JS has no refresh button.

- [ ] **Step 3: Commit**

```bash
git add firmware/assets/captive-portal/tests/test_form_behavior.py
git commit -m "test: Tier 2 — timeout shows Refresh button (red)"
```

---

## Task 8: Write Tier 2 test — Refresh button restarts polling

After timeout, click the Refresh button; mock is then reconfigured to return networks; dropdown must populate.

**Trick:** switching the mock mid-test requires the mock script to read from a mutable source. Simplest approach: expose a `window.__testNetworks` array that the mock reads, and tweak it from Playwright via `page.evaluate`.

**Files:**
- Modify: `firmware/assets/captive-portal/tests/test_form_behavior.py` (append test + helper)

- [ ] **Step 1: Append a mutable-mock helper and the test**

```python
MUTABLE_MOCK = """
<script>
  window.__testNetworks = [];
  window.fetch = async () => ({ json: async () => window.__testNetworks });
</script>
"""

def test_refresh_button_restarts_polling(serve_preview, page: Page):
    """After timeout retry, changing the mock to networks → dropdown populates."""
    url = serve_preview(kid="emory", mock_script=MUTABLE_MOCK)
    page.goto(url)

    # Wait for timeout path (30 s) to surface the Refresh button.
    refresh = page.get_by_role("button", name="Refresh networks")
    expect(refresh).to_be_visible(timeout=32000)

    # Swap the mock to return networks, then click Refresh.
    page.evaluate(
        "window.__testNetworks = "
        "[{ssid:'Restarted', rssi:-50, secured:true}]"
    )
    refresh.click()

    dropdown = page.locator("#ssid")
    expect(dropdown.locator("option")).to_have_count(1, timeout=5000)
    expect(dropdown.locator("option")).to_contain_text(["Restarted"])
```

- [ ] **Step 2: Run the test — expect failure against old JS**

Run:
```bash
cd firmware/assets/captive-portal && python -m pytest tests/test_form_behavior.py::test_refresh_button_restarts_polling -v
```

Expected: **FAIL**. Old JS has no refresh button, no polling.

- [ ] **Step 3: Commit**

```bash
git add firmware/assets/captive-portal/tests/test_form_behavior.py
git commit -m "test: Tier 2 — Refresh restarts polling (red)"
```

---

## Task 9: Write Tier 2 test — polling stops after success

Mock returns networks immediately. Over 10 s, at most 2 `fetch` calls are made (the initial one + possibly one racing poll that hadn't been scheduled yet). Dropdown stays populated — critically, it is NOT reset to empty by a later poll.

**Files:**
- Modify: `firmware/assets/captive-portal/tests/test_form_behavior.py` (append test)

- [ ] **Step 1: Append the test**

```python
def test_polling_stops_after_success(serve_preview, page: Page):
    """First /scan returns networks; polling stops; dropdown stays populated."""
    counter_mock = """
    <script>
      window.__fetchCount = 0;
      window.fetch = async () => {
        window.__fetchCount += 1;
        return { json: async () => ([
          {ssid: 'Stable', rssi: -50, secured: true},
        ])};
      };
    </script>
    """
    url = serve_preview(kid="emory", mock_script=counter_mock)
    page.goto(url)

    dropdown = page.locator("#ssid")
    expect(dropdown.locator("option")).to_have_count(1, timeout=3000)
    expect(dropdown.locator("option")).to_contain_text(["Stable"])

    # Wait 10 s — several poll intervals. Polling must have stopped.
    page.wait_for_timeout(10000)

    count = page.evaluate("window.__fetchCount")
    assert count <= 2, f"expected ≤2 /scan calls, saw {count} (polling did not stop)"

    # Dropdown still populated (not reset to empty by a late poll).
    expect(dropdown.locator("option")).to_have_count(1)
    expect(dropdown.locator("option")).to_contain_text(["Stable"])
```

- [ ] **Step 2: Run the test — expect PASS on old JS**

Run:
```bash
cd firmware/assets/captive-portal && python -m pytest tests/test_form_behavior.py::test_polling_stops_after_success -v
```

Expected: **PASS**. Old JS fetches exactly once — `__fetchCount == 1`, dropdown has 1 option, stays populated. This test locks in the "don't over-fetch" invariant for both old and new JS.

- [ ] **Step 3: Commit**

```bash
git add firmware/assets/captive-portal/tests/test_form_behavior.py
git commit -m "test: Tier 2 — polling stops after success"
```

---

## Task 10: Confirm full red baseline before implementation

Before implementing the new JS, make one final run of ALL new tests to confirm the expected red pattern. This is the explicit TDD gate.

- [ ] **Step 1: Run the full new test suite**

Run:
```bash
cd firmware/assets/captive-portal && python -m pytest tests/ -v
```

Expected counts:

| Test file | Passing | Failing |
|---|---|---|
| `test_gen_form_html.py` — existing 6 | 6 | 0 |
| `test_gen_form_html.py` — new Tier 1 (6) | 2 | 4 |
| `test_form_behavior.py` — new Tier 2 (5) | 2 | 3 |

**Passing now, expected to still pass after Task 11:**
- `test_no_single_line_comments_in_js`
- `test_generated_js_parses_as_valid_js`
- `test_dropdown_populates_on_immediate_success`
- `test_polling_stops_after_success`

**Failing now, expected to pass after Task 11:**
- `test_polling_interval_is_2000ms`
- `test_polling_timeout_is_30s`
- `test_polling_stops_on_nonempty_result`
- `test_timeout_shows_refresh_button`
- `test_dropdown_populates_after_polling`
- `test_timeout_shows_refresh_button` (Tier 2)
- `test_refresh_button_restarts_polling`

If the actual pattern diverges from this table, stop and investigate before writing new JS.

- [ ] **Step 2: Record the baseline in the session log** (no commit — just verification)

---

## Task 11: Replace one-shot fetch with polling loop in `form.html.template`

The core JS change. Replaces the `<script>` block at the bottom of `form.html.template` with the polling state machine.

**Files:**
- Modify: `firmware/assets/captive-portal/form.html.template` (lines 40-63, `<script>` body)

- [ ] **Step 1: Replace the `<script>` block**

In `firmware/assets/captive-portal/form.html.template`, locate the current block:

```html
  <script>
    // Populate SSID dropdown from /scan once it arrives.
    fetch('/scan').then(r => r.json()).then(nets => {
      const sel = document.getElementById('ssid');
      sel.innerHTML = '';
      const seen = new Set();
      for (const n of nets) {
        if (seen.has(n.ssid)) continue;
        seen.add(n.ssid);
        const opt = document.createElement('option');
        opt.value = n.ssid;
        opt.textContent = n.ssid + (n.secured ? '' : ' (open)');
        sel.appendChild(opt);
      }
      if (sel.children.length === 0) {
        const opt = document.createElement('option');
        opt.value = '';
        opt.textContent = 'No networks found — try again';
        sel.appendChild(opt);
      }
    }).catch(() => {
      const sel = document.getElementById('ssid');
      sel.innerHTML = '<option value="">Scan failed — reload</option>';
    });
  </script>
```

Replace with:

```html
  <script>
    /* Poll /scan every 2s until populated or 30s timeout. Stop on first
       non-empty result — the server calls WiFi.scanDelete() after returning
       results, so a subsequent poll would return [] and erase the dropdown. */
    const POLL_INTERVAL_MS = 2000;
    const TIMEOUT_MS = 30000;
    let startedAt = 0;
    let timerId = null;

    function renderSsidList(nets) {
      const sel = document.getElementById('ssid');
      sel.innerHTML = '';
      const seen = new Set();
      for (const n of nets) {
        if (seen.has(n.ssid)) continue;
        seen.add(n.ssid);
        const opt = document.createElement('option');
        opt.value = n.ssid;
        opt.textContent = n.ssid + (n.secured ? '' : ' (open)');
        sel.appendChild(opt);
      }
    }

    function renderTimeoutRetry() {
      const sel = document.getElementById('ssid');
      sel.innerHTML = '';
      const opt = document.createElement('option');
      opt.value = '';
      opt.textContent = 'No networks found — click Refresh';
      sel.appendChild(opt);
      const btn = document.createElement('button');
      btn.type = 'button';
      btn.textContent = 'Refresh networks';
      btn.onclick = () => { btn.remove(); startPolling(); };
      sel.parentNode.insertBefore(btn, sel.nextSibling);
    }

    function pollScanOnce() {
      fetch('/scan').then(r => r.json()).then(nets => {
        if (nets.length > 0) {
          clearTimeout(timerId);
          timerId = null;
          renderSsidList(nets);
          return;
        }
        if (Date.now() - startedAt >= TIMEOUT_MS) {
          renderTimeoutRetry();
          return;
        }
        timerId = setTimeout(pollScanOnce, POLL_INTERVAL_MS);
      }).catch(() => {
        if (Date.now() - startedAt >= TIMEOUT_MS) {
          renderTimeoutRetry();
          return;
        }
        timerId = setTimeout(pollScanOnce, POLL_INTERVAL_MS);
      });
    }

    function startPolling() {
      startedAt = Date.now();
      pollScanOnce();
    }

    startPolling();
  </script>
```

Note the `/* ... */` block comment at the top — intentional; `//` comments would be consumed after `_collapse_newlines()` joins lines.

- [ ] **Step 2: Run the full pytest suite**

Run:
```bash
cd firmware/assets/captive-portal && python -m pytest tests/ -v
```

Expected: **17 tests pass, 0 fail** (6 existing + 6 new Tier 1 + 5 new Tier 2). If any fail, fix before committing.

- [ ] **Step 3: Commit**

```bash
git add firmware/assets/captive-portal/form.html.template
git commit -m "feat(captive-portal): poll /scan every 2s with 30s timeout + refresh

Replaces the one-shot fetch('/scan') with a polling state machine. Stops
on first non-empty response (critical: server WiFi.scanDelete()s after
serving results, so a second poll would return [] and erase the
dropdown). After 30s of empty/failed responses, shows 'No networks found
— click Refresh' plus a Refresh button that restarts polling.

Tier 1 pytest (6) + Tier 2 Playwright (5) now green."
```

---

## Task 12: Flip `WIFI_AP` to `WIFI_AP_STA`

Single-line edit. The firmware side of the real fix.

**Files:**
- Modify: `firmware/lib/wifi_provision/src/wifi_provision.cpp:105`

- [ ] **Step 1: Make the edit**

Change line 105:

```diff
-    WiFi.mode(WIFI_AP);
+    WiFi.mode(WIFI_AP_STA);
```

Full surrounding context (for reference):

```cpp
static void start_ap() {
    WiFi.mode(WIFI_AP_STA);          // <-- changed from WIFI_AP
    uint64_t mac = ESP.getEfuseMac();
```

- [ ] **Step 2: Build both envs**

Run:
```bash
cd firmware && pio run -e emory && pio run -e nora
```

Expected: both builds succeed. Flash size delta is zero or near-zero (same function, different constant).

- [ ] **Step 3: Run native tests**

Run:
```bash
cd firmware && pio test -e native
```

Expected: **172/172 tests pass**. (The native env does not compile `wifi_provision.cpp` — it's `#ifdef ARDUINO`-wrapped — but we run native tests to catch any incidental breakage.)

- [ ] **Step 4: Commit**

```bash
git add firmware/lib/wifi_provision/src/wifi_provision.cpp
git commit -m "fix(wifi_provision): use WIFI_AP_STA so /scan can find networks

WIFI_AP disables station-mode scanning, which broke the SSID dropdown on
the first-ever bench bring-up. WIFI_AP_STA lets the radio both broadcast
the captive AP and execute WiFi.scanNetworks()."
```

---

## Task 13: Raise `max_connection` from 1 to 4

Second single-line edit. Allows multi-device provisioning.

**Files:**
- Modify: `firmware/lib/wifi_provision/src/wifi_provision.cpp:111`

- [ ] **Step 1: Make the edit**

Change line 111:

```diff
-                /* ssid_hidden = */ 0, /* max_connection = */ 1);
+                /* ssid_hidden = */ 0, /* max_connection = */ 4);
```

- [ ] **Step 2: Build both envs**

Run:
```bash
cd firmware && pio run -e emory && pio run -e nora
```

Expected: both succeed, flash delta zero.

- [ ] **Step 3: Commit**

```bash
git add firmware/lib/wifi_provision/src/wifi_provision.cpp
git commit -m "fix(wifi_provision): allow up to 4 AP clients

max_connection=1 blocked the 'switch from phone to laptop if the first
device misbehaves' troubleshooting workflow. 4 covers real-world
multi-device provisioning (laptop + phone + 2 spares)."
```

---

## Task 14: Append hardware checks #8, #9, #10

Manual verification steps to run against a real ESP32 after flashing. Confirms the WIFI_AP_STA + max_connection fixes work on physical hardware (no automated test covers this).

**Files:**
- Modify: `firmware/test/hardware_checks/wifi_provision_checks.md`

- [ ] **Step 1: Append hardware checks**

Append to the end of `firmware/test/hardware_checks/wifi_provision_checks.md`:

```markdown

## 8. Multi-device connection (max_connection=4 regression)

- [ ] Flash the latest firmware: `cd firmware && pio run -e emory -t upload`
- [ ] Connect laptop to `WordClock-Setup-XXXX`.
- [ ] Without disconnecting laptop, connect phone to the same SSID.
- [ ] Expected: both devices connected. Form loads on both at `http://192.168.4.1`.

## 9. Scan dropdown populates (WIFI_AP_STA regression)

- [ ] Erase NVS + flash: `cd firmware && pio run -e emory -t erase && pio run -e emory -t upload`
- [ ] Connect laptop (or phone) to `WordClock-Setup-XXXX`.
- [ ] Open `http://192.168.4.1` in a browser.
- [ ] Expected: within 30 s, SSID dropdown shows nearby 2.4 GHz networks.
- [ ] Expected: dropdown stays populated — does NOT regress to empty / "No networks found"
      after displaying networks (a regression of the stop-on-success polling rule).

## 10. Timeout retry path (polling regression)

Run in a location where no 2.4 GHz networks are visible (rare in residential
settings), or simulate by powering down your home router temporarily.

- [ ] Connect a device to `WordClock-Setup-XXXX` and open the form.
- [ ] Wait 30 s.
- [ ] Expected: dropdown shows "No networks found — click Refresh" + a visible
      Refresh button.
- [ ] Click Refresh.
- [ ] Expected: polling restarts (visible as new /scan requests on the ESP32
      serial monitor if you're watching). If networks become available during
      retry, dropdown populates.
```

- [ ] **Step 2: Commit**

```bash
git add firmware/test/hardware_checks/wifi_provision_checks.md
git commit -m "docs: add hardware checks for multi-device + scan-poll paths"
```

---

## Task 15: Flash + run the new hardware checks

End-to-end verification on real hardware. Both firmware edits + the JS change together must produce a working captive portal provisioning experience.

- [ ] **Step 1: Erase NVS and flash Emory firmware**

Run:
```bash
cd firmware && pio run -e emory -t erase && pio run -e emory -t upload
```

Expected: upload succeeds. ESP32 boots into captive portal (no saved credentials).

- [ ] **Step 2: Walk through hardware check #9 (scan populates)**

Per the checklist added in Task 14 §9: connect a device, open `http://192.168.4.1`, verify dropdown populates within 30 s and stays populated.

If the dropdown stays stuck on "Scanning for networks…" or regresses to empty:
- Check serial monitor for scan-related errors (`pio device monitor`).
- Re-verify Tasks 11 and 12 were saved + flashed (git log should show the commits).

- [ ] **Step 3: Walk through hardware check #8 (multi-device)**

Per the checklist added in Task 14 §8: connect laptop, then phone to the same AP. Both must connect.

- [ ] **Step 4: Walk through hardware check #10 (timeout retry)**

Optional but recommended. Per §10: force an empty scan environment, confirm Refresh button appears + restarts polling.

- [ ] **Step 5: Complete the end-to-end captive-portal flow**

From the existing `wifi_provision_checks.md` §3–§7: pick your home SSID from the populated dropdown, submit form, press Audio button, verify the clock disconnects from the AP and connects to home WiFi.

Expected: full provisioning flow works.

- [ ] **Step 6: If anything fails, capture serial logs and stop**

If any hardware step fails, do NOT mark this task complete. Capture the serial output and file as a follow-up.

---

## Task 16: Update TODO.md + final doc sweep

Close the loop: mark the defect resolved in the live working list, and verify no dangling references to the old behavior remain in docs.

**Files:**
- Modify: `TODO.md` (status table if needed, add a "Shipped 2026-04-20" bullet under a suitable section)

- [ ] **Step 1: Check TODO.md for any tracking of this defect**

Run:
```bash
grep -n "captive portal\|wifi_provision\|scan" TODO.md
```

If a tracking bullet exists, mark it `[x]` with a note referencing this plan. If no tracking bullet exists, add one to the relevant section:

```markdown
- [x] **Captive portal scan fix (2026-04-20)** — WIFI_AP → WIFI_AP_STA,
      max_connection 1 → 4, /scan polling + 30 s timeout + Refresh button.
      Implements `docs/superpowers/specs/2026-04-20-captive-portal-scan-fix-design.md`.
```

- [ ] **Step 2: Run all pytest + native tests one final time**

Run:
```bash
cd firmware/assets/captive-portal && python -m pytest tests/ -v
cd firmware && pio test -e native
```

Expected: 17 Python tests pass + 172 native tests pass.

- [ ] **Step 3: Commit TODO update**

```bash
git add TODO.md
git commit -m "docs(todo): mark captive portal scan fix complete"
```

- [ ] **Step 4: Confirm full plan completion**

`git log --oneline -20` should show the commit chain:
1. `test: add Playwright dev deps...`
2. `test: parameterize preview mock...`
3. `test: add conftest fixtures...`
4. `test: add Tier 1 structural pytest... (red)`
5-9. Tier 2 test commits
10. `feat(captive-portal): poll /scan every 2s...`
11. `fix(wifi_provision): use WIFI_AP_STA...`
12. `fix(wifi_provision): allow up to 4 AP clients`
13. `docs: add hardware checks...`
14. `docs(todo): mark captive portal scan fix complete`

Clean, atomic, each commit green.

---

## Self-review checklist (executed during plan authoring — kept here as context for implementers)

- [x] **Spec coverage:** Every change in `2026-04-20-captive-portal-scan-fix-design.md` has a task (Change 1 → Task 12, Change 2 → Task 13, Change 3 → Task 11, Tier 1 → Task 4, Tier 2 → Tasks 5-9, hardware checks → Task 14).
- [x] **No placeholders:** Every code step has complete code. Every verification step has exact command + expected output.
- [x] **Type consistency:** `POLL_INTERVAL_MS`, `TIMEOUT_MS`, `renderSsidList`, `renderTimeoutRetry`, `pollScanOnce`, `startPolling` names used consistently across the JS and all Tier 1 tests that reference them.
- [x] **Red-green TDD cycles:** Tasks 4-9 write tests, Task 10 confirms red baseline, Task 11 flips to green. Tasks 12-13 covered by hardware checks in Task 15 (no automated red-green possible for hardware mode changes).

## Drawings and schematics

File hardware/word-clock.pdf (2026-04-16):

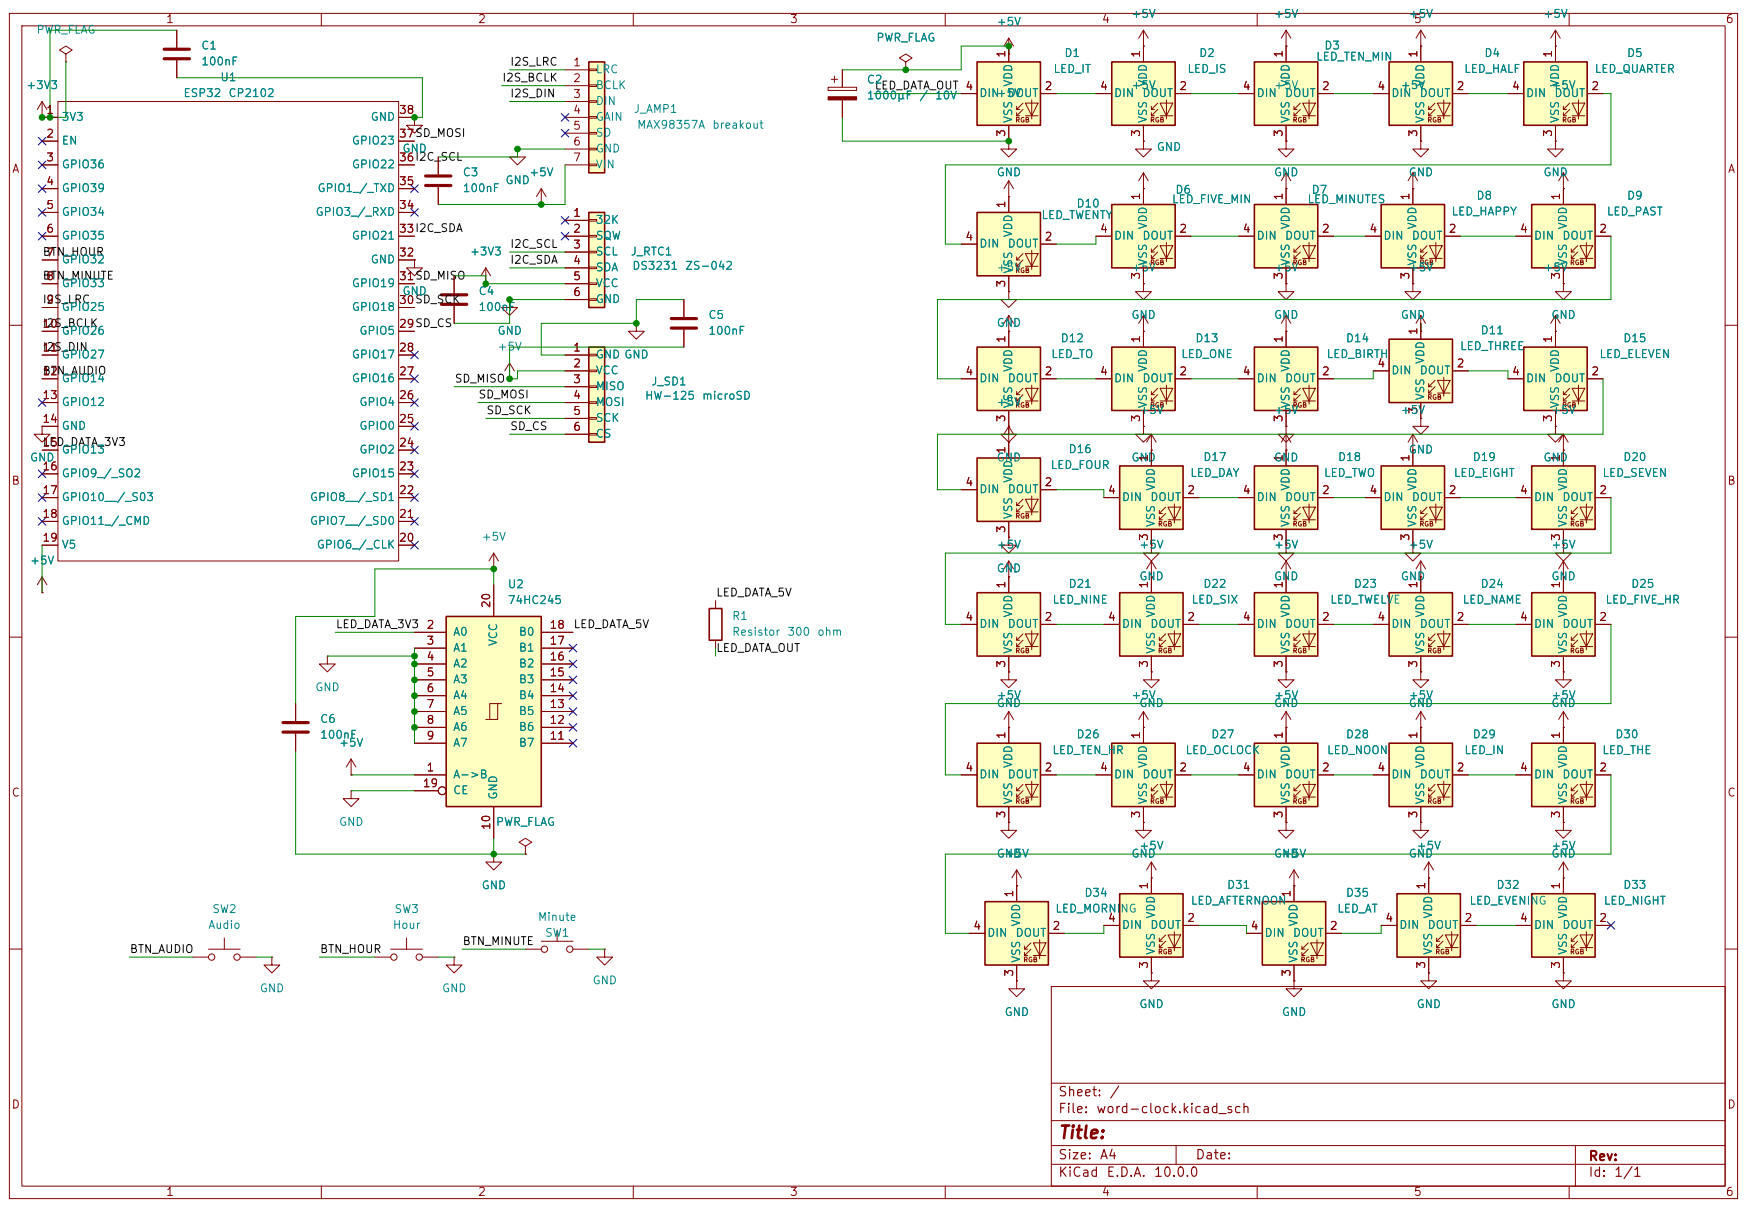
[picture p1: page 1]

Size: A4 | Rev:
KiCad E.D.A. 10.0.0 | Id: 1/1

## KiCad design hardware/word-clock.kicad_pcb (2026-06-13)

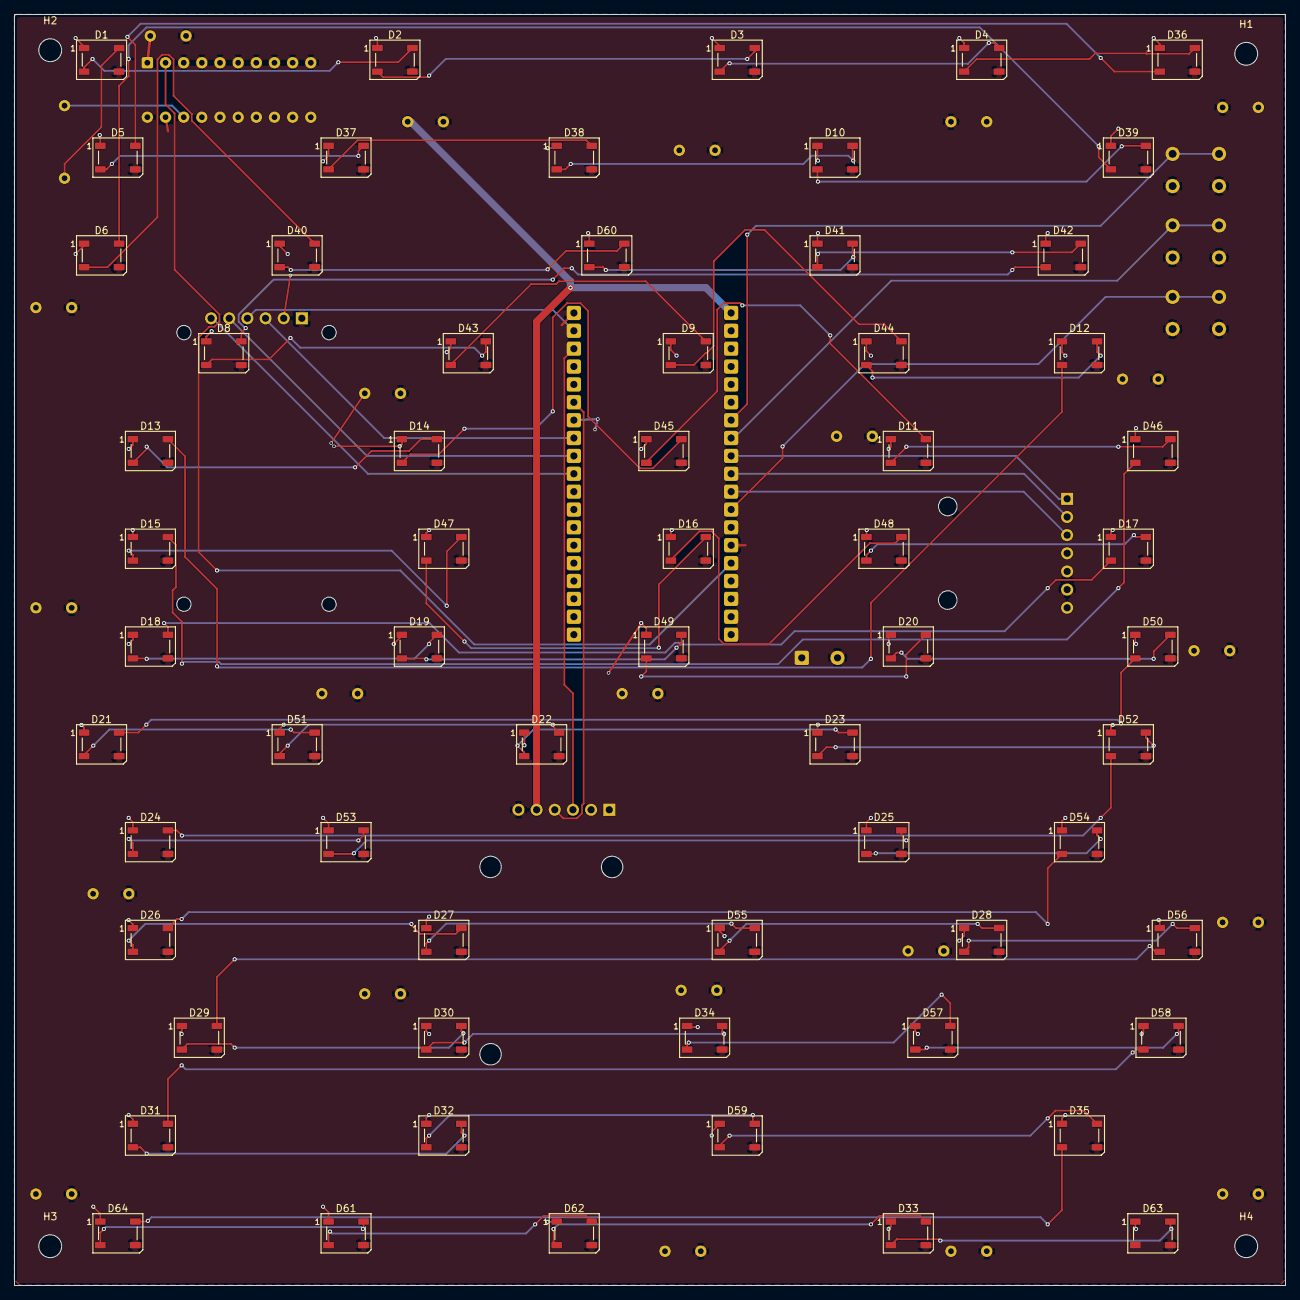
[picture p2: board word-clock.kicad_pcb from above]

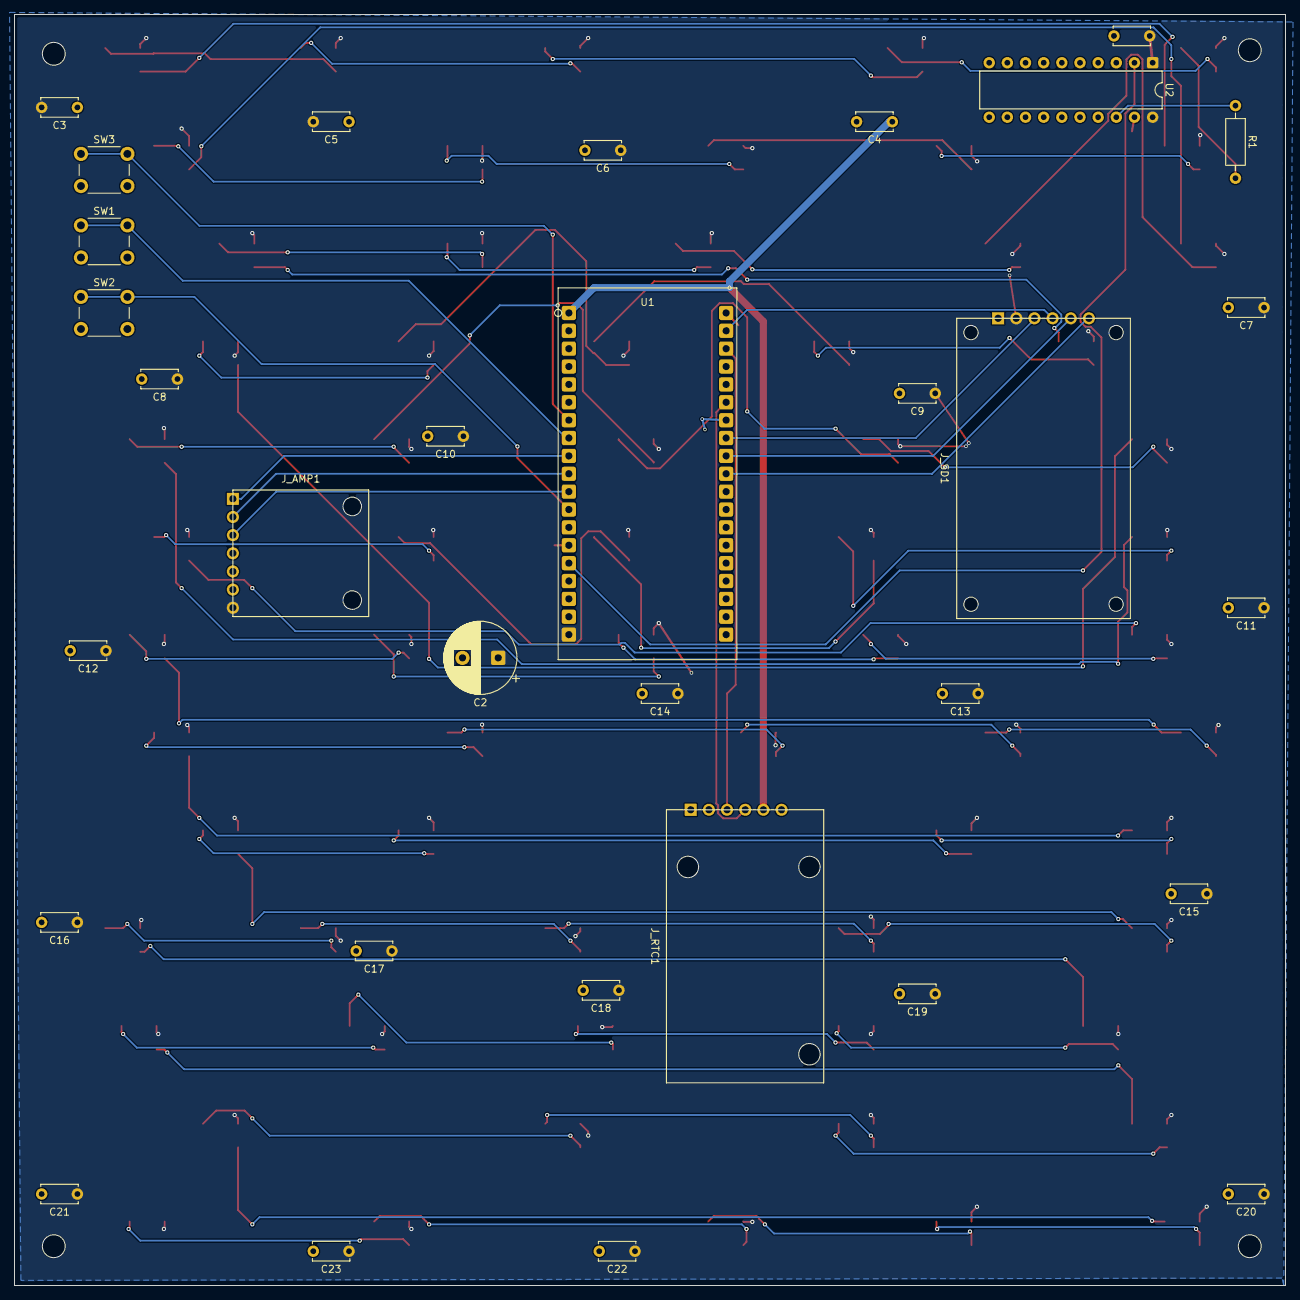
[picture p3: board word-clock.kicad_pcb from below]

Board: 2 copper layers, 177.8 x 177.8 mm, 99 parts (32 on the bottom side), 80 nets.

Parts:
C1, C3, C4, C5, C6, C7, C8, C9, C10, C11, C12, C13, C14, C15, C16, C17, C18, C19, C20, C21, C22, C23: 100nF; C_Disc_D5.0mm_W2.5mm_P5.00mm
C2: 1000µF / 10V; CP_Radial_D10.0mm_P5.00mm
D1: LED_IT; LED_WS2812B_PLCC4_5.0x5.0mm_P3.2mm
D2: LED_IS; LED_WS2812B_PLCC4_5.0x5.0mm_P3.2mm
D3: LED_TEN_MIN; LED_WS2812B_PLCC4_5.0x5.0mm_P3.2mm
D4: LED_HALF; LED_WS2812B_PLCC4_5.0x5.0mm_P3.2mm
D5: LED_QUARTER; LED_WS2812B_PLCC4_5.0x5.0mm_P3.2mm
D6: LED_FIVE_MIN; LED_WS2812B_PLCC4_5.0x5.0mm_P3.2mm
D8: LED_HAPPY; LED_WS2812B_PLCC4_5.0x5.0mm_P3.2mm
D9: LED_PAST; LED_WS2812B_PLCC4_5.0x5.0mm_P3.2mm
D10: LED_TWENTY; LED_WS2812B_PLCC4_5.0x5.0mm_P3.2mm
D11: LED_THREE; LED_WS2812B_PLCC4_5.0x5.0mm_P3.2mm
D12: LED_TO; LED_WS2812B_PLCC4_5.0x5.0mm_P3.2mm
D13: LED_ONE; LED_WS2812B_PLCC4_5.0x5.0mm_P3.2mm
D14: LED_BIRTH; LED_WS2812B_PLCC4_5.0x5.0mm_P3.2mm
D15: LED_ELEVEN; LED_WS2812B_PLCC4_5.0x5.0mm_P3.2mm
D16: LED_FOUR; LED_WS2812B_PLCC4_5.0x5.0mm_P3.2mm
D17: LED_DAY; LED_WS2812B_PLCC4_5.0x5.0mm_P3.2mm
D18: LED_TWO; LED_WS2812B_PLCC4_5.0x5.0mm_P3.2mm
D19: LED_EIGHT; LED_WS2812B_PLCC4_5.0x5.0mm_P3.2mm
D20: LED_SEVEN; LED_WS2812B_PLCC4_5.0x5.0mm_P3.2mm
D21: LED_NINE; LED_WS2812B_PLCC4_5.0x5.0mm_P3.2mm
D22: LED_SIX; LED_WS2812B_PLCC4_5.0x5.0mm_P3.2mm
D23: LED_TWELVE; LED_WS2812B_PLCC4_5.0x5.0mm_P3.2mm
D24: LED_NAME; LED_WS2812B_PLCC4_5.0x5.0mm_P3.2mm
D25: LED_FIVE_HR; LED_WS2812B_PLCC4_5.0x5.0mm_P3.2mm
D26: LED_TEN_HR; LED_WS2812B_PLCC4_5.0x5.0mm_P3.2mm
D27: LED_OCLOCK; LED_WS2812B_PLCC4_5.0x5.0mm_P3.2mm
D28: LED_NOON; LED_WS2812B_PLCC4_5.0x5.0mm_P3.2mm
D29: LED_IN; LED_WS2812B_PLCC4_5.0x5.0mm_P3.2mm
D30: LED_THE; LED_WS2812B_PLCC4_5.0x5.0mm_P3.2mm
D31: LED_AFTERNOON; LED_WS2812B_PLCC4_5.0x5.0mm_P3.2mm
D32: LED_AFTERNOON_1; LED_WS2812B_PLCC4_5.0x5.0mm_P3.2mm
D33: LED_NIGHT; LED_WS2812B_PLCC4_5.0x5.0mm_P3.2mm
D34: LED_MORNING; LED_WS2812B_PLCC4_5.0x5.0mm_P3.2mm
D35: LED_AT; LED_WS2812B_PLCC4_5.0x5.0mm_P3.2mm
D36: LED_HALF_1; LED_WS2812B_PLCC4_5.0x5.0mm_P3.2mm
D37: LED_QUARTER_1; LED_WS2812B_PLCC4_5.0x5.0mm_P3.2mm
D38: LED_QUARTER_2; LED_WS2812B_PLCC4_5.0x5.0mm_P3.2mm
D39: LED_TWENTY_1; LED_WS2812B_PLCC4_5.0x5.0mm_P3.2mm
D40: LED_FIVE_MIN_1; LED_WS2812B_PLCC4_5.0x5.0mm_P3.2mm
D41: LED_MINUTES_1; LED_WS2812B_PLCC4_5.0x5.0mm_P3.2mm
D42: LED_MINUTES_2; LED_WS2812B_PLCC4_5.0x5.0mm_P3.2mm
D43: LED_HAPPY_1; LED_WS2812B_PLCC4_5.0x5.0mm_P3.2mm
D44: LED_PAST_1; LED_WS2812B_PLCC4_5.0x5.0mm_P3.2mm
D45: LED_BIRTH_1; LED_WS2812B_PLCC4_5.0x5.0mm_P3.2mm
D46: LED_THREE_1; LED_WS2812B_PLCC4_5.0x5.0mm_P3.2mm
D47: LED_ELEVEN_1; LED_WS2812B_PLCC4_5.0x5.0mm_P3.2mm
D48: LED_FOUR_1; LED_WS2812B_PLCC4_5.0x5.0mm_P3.2mm
D49: LED_EIGHT_1; LED_WS2812B_PLCC4_5.0x5.0mm_P3.2mm
D50: LED_SEVEN_1; LED_WS2812B_PLCC4_5.0x5.0mm_P3.2mm
D51: LED_NINE_1; LED_WS2812B_PLCC4_5.0x5.0mm_P3.2mm
D52: LED_TWELVE_1; LED_WS2812B_PLCC4_5.0x5.0mm_P3.2mm
D53: LED_NAME_1; LED_WS2812B_PLCC4_5.0x5.0mm_P3.2mm
D54: LED_FIVE_HR_1; LED_WS2812B_PLCC4_5.0x5.0mm_P3.2mm
D55: LED_OCLOCK_1; LED_WS2812B_PLCC4_5.0x5.0mm_P3.2mm
D56: LED_NOON_1; LED_WS2812B_PLCC4_5.0x5.0mm_P3.2mm
D57: LED_MORNING_1; LED_WS2812B_PLCC4_5.0x5.0mm_P3.2mm
D58: LED_MORNING_2; LED_WS2812B_PLCC4_5.0x5.0mm_P3.2mm
D59: LED_AFTERNOON_2; LED_WS2812B_PLCC4_5.0x5.0mm_P3.2mm
D60: LED_MINUTES; LED_WS2812B_PLCC4_5.0x5.0mm_P3.2mm
D61: LED_EVENING_1; LED_WS2812B_PLCC4_5.0x5.0mm_P3.2mm
D62: LED_EVENING_2; LED_WS2812B_PLCC4_5.0x5.0mm_P3.2mm
D63: LED_NIGHT_1; LED_WS2812B_PLCC4_5.0x5.0mm_P3.2mm
D64: LED_EVENING; LED_WS2812B_PLCC4_5.0x5.0mm_P3.2mm
H1, H2, H3, H4: MountingHole_3.2mm_M3
J_AMP1: MAX98357A breakout; Daughtercard_AMP_MAX98357A
J_RTC1: DS3231 ZS-042; Daughtercard_RTC_DS3231
J_SD1: HW-125 microSD; Daughtercard_SD_HW125
R1: Resistor 300 ohm; R_Axial_DIN0207_L6.3mm_D2.5mm_P10.16mm_Horizontal
SW1: Minute; SW_PUSH_6mm
SW2: Audio; SW_PUSH_6mm
SW3: Hour; SW_PUSH_6mm
U1: ESP32 CP2102; ESP32_38Pin
U2: 74HCT245; DIP-20_W7.62mm

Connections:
+3V3: C4.1, J_RTC1.2 (VCC_5), U1.1 (3V3)
+5V: C1.1, C2.1, C3.2, C5.2, C6.1, C7.1, C8.1, C9.1, C10.1, C11.1, C12.1, C13.1, C14.1, C15.1, C16.1, C17.1, C18.1, C19.1, C20.1, C21.1, C22.1, C23.1, D1.1 (VDD), D2.1 (VDD), D3.1 (VDD), D4.1 (VDD), D5.1 (VDD), D6.1 (VDD), D8.1 (VDD), D9.1 (VDD), D10.1 (VDD), D11.1 (VDD), D12.1 (VDD), D13.1 (VDD), D14.1 (VDD), D15.1 (VDD), D16.1 (VDD), D17.1 (VDD), D18.1 (VDD), D19.1 (VDD), D20.1 (VDD), D21.1 (VDD), D22.1 (VDD), D23.1 (VDD), D24.1 (VDD), D25.1 (VDD), D26.1 (VDD), D27.1 (VDD), D28.1 (VDD), D29.1 (VDD), D30.1 (VDD), D31.1 (VDD), D32.1 (VDD), D33.1 (VDD), D34.1 (VDD), D35.1 (VDD), D36.1 (VDD), D37.1 (VDD), D38.1 (VDD), D39.1 (VDD), D40.1 (VDD), D41.1 (VDD), D42.1 (VDD), D43.1 (VDD), D44.1 (VDD), D45.1 (VDD), D46.1 (VDD), D47.1 (VDD), D48.1 (VDD), D49.1 (VDD), D50.1 (VDD), D51.1 (VDD), D52.1 (VDD), D53.1 (VDD), D54.1 (VDD), D55.1 (VDD), D56.1 (VDD), D57.1 (VDD), D58.1 (VDD), D59.1 (VDD), D60.1 (VDD), D61.1 (VDD), D62.1 (VDD), D63.1 (VDD), D64.1 (VDD), J_AMP1.7 (VIN), J_SD1.5 (VCC_2), U1.19 (V5), U2.1 (A->B), U2.20 (VCC)
/BTN_AUDIO: SW2.1, U1.12 (GPIO14)
/BTN_HOUR: SW3.1, U1.7 (GPIO32)
/BTN_MINUTE: SW1.1, U1.8 (GPIO33)
/I2C_SCL: J_RTC1.4 (SCL_3), U1.36 (GPIO22)
/I2C_SDA: J_RTC1.3 (SDA_4), U1.33 (GPIO21)
/I2S_BCLK: J_AMP1.2 (BCLK), U1.10 (GPIO26)
/I2S_DIN: J_AMP1.3 (DIN), U1.11 (GPIO27)
/I2S_LRC: J_AMP1.1 (LRC), U1.9 (GPIO25)
/LED_DATA_3V3: U1.15 (GPIO13), U2.2 (A0)
/LED_DATA_5V: R1.1, U2.18 (B0)
/LED_DATA_OUT: D1.4 (DIN), R1.2
/SD_CS: J_SD1.1 (CS_6), U1.29 (GPIO5)
/SD_MISO: J_SD1.4 (MISO_3), U1.31 (GPIO19)
/SD_MOSI: J_SD1.3 (MOSI_4), U1.37 (GPIO23)
/SD_SCK: J_SD1.2 (SCK_5), U1.30 (GPIO18)
GND: C1.2, C2.2, C3.1, C4.2, C5.1, C6.2, C7.2, C8.2, C9.2, C10.2, C11.2, C12.2, C13.2, C14.2, C15.2, C16.2, C17.2, C18.2, C19.2, C20.2, C21.2, C22.2, C23.2, D1.3 (VSS), D2.3 (VSS), D3.3 (VSS), D4.3 (VSS), D5.3 (VSS), D6.3 (VSS), D8.3 (VSS), D9.3 (VSS), D10.3 (VSS), D11.3 (VSS), D12.3 (VSS), D13.3 (VSS), D14.3 (VSS), D15.3 (VSS), D16.3 (VSS), D17.3 (VSS), D18.3 (VSS), D19.3 (VSS), D20.3 (VSS), D21.3 (VSS), D22.3 (VSS), D23.3 (VSS), D24.3 (VSS), D25.3 (VSS), D26.3 (VSS), D27.3 (VSS), D28.3 (VSS), D29.3 (VSS), D30.3 (VSS), D31.3 (VSS), D32.3 (VSS), D33.3 (VSS), D34.3 (VSS), D35.3 (VSS), D36.3 (VSS), D37.3 (VSS), D38.3 (VSS), D39.3 (VSS), D40.3 (VSS), D41.3 (VSS), D42.3 (VSS), D43.3 (VSS), D44.3 (VSS), D45.3 (VSS), D46.3 (VSS), D47.3 (VSS), D48.3 (VSS), D49.3 (VSS), D50.3 (VSS), D51.3 (VSS), D52.3 (VSS), D53.3 (VSS), D54.3 (VSS), D55.3 (VSS), D56.3 (VSS), D57.3 (VSS), D58.3 (VSS), D59.3 (VSS), D60.3 (VSS), D61.3 (VSS), D62.3 (VSS), D63.3 (VSS), D64.3 (VSS), J_AMP1.6 (GND), J_RTC1.1 (GND_6), J_SD1.6 (GND_1), SW1.2, SW2.2, SW3.2, U1.14 (GND), U1.32 (GND), U1.38 (GND), U2.3 (A1), U2.4 (A2), U2.5 (A3), U2.6 (A4), U2.7 (A5), U2.8 (A6), U2.9 (A7), U2.10 (GND), U2.19 (CE)
unnamed: D1.2 (DOUT), D2.4 (DIN)
unnamed: D2.2 (DOUT), D3.4 (DIN)
unnamed: D3.2 (DOUT), D4.4 (DIN)
unnamed: D10.4 (DIN), D38.2 (DOUT)
unnamed: D10.2 (DOUT), D39.4 (DIN)
unnamed: D11.4 (DIN), D45.2 (DOUT)
unnamed: D11.2 (DOUT), D46.4 (DIN)
unnamed: D12.4 (DIN), D44.2 (DOUT)
unnamed: D12.2 (DOUT), D13.4 (DIN)
unnamed: D13.2 (DOUT), D14.4 (DIN)
unnamed: D14.2 (DOUT), D45.4 (DIN)
unnamed: D15.4 (DIN), D46.2 (DOUT)
unnamed: D15.2 (DOUT), D47.4 (DIN)
unnamed: D16.4 (DIN), D47.2 (DOUT)
unnamed: D16.2 (DOUT), D48.4 (DIN)
unnamed: D17.4 (DIN), D48.2 (DOUT)
unnamed: D17.2 (DOUT), D18.4 (DIN)
unnamed: D18.2 (DOUT), D19.4 (DIN)
unnamed: D19.2 (DOUT), D49.4 (DIN)
unnamed: D20.4 (DIN), D49.2 (DOUT)
unnamed: D20.2 (DOUT), D50.4 (DIN)
unnamed: D21.4 (DIN), D50.2 (DOUT)
unnamed: D21.2 (DOUT), D51.4 (DIN)
unnamed: D22.4 (DIN), D51.2 (DOUT)
unnamed: D22.2 (DOUT), D23.4 (DIN)
unnamed: D23.2 (DOUT), D52.4 (DIN)
unnamed: D24.4 (DIN), D52.2 (DOUT)
unnamed: D24.2 (DOUT), D53.4 (DIN)
unnamed: D25.4 (DIN), D53.2 (DOUT)
unnamed: D25.2 (DOUT), D54.4 (DIN)
unnamed: D26.4 (DIN), D54.2 (DOUT)
unnamed: D26.2 (DOUT), D27.4 (DIN)
unnamed: D27.2 (DOUT), D55.4 (DIN)
unnamed: D28.4 (DIN), D55.2 (DOUT)
unnamed: D28.2 (DOUT), D56.4 (DIN)
unnamed: D29.4 (DIN), D56.2 (DOUT)
unnamed: D29.2 (DOUT), D30.4 (DIN)
unnamed: D30.2 (DOUT), D34.4 (DIN)
unnamed: D31.4 (DIN), D58.2 (DOUT)
unnamed: D31.2 (DOUT), D32.4 (DIN)
unnamed: D32.2 (DOUT), D59.4 (DIN)
unnamed: D33.4 (DIN), D62.2 (DOUT)
unnamed: D33.2 (DOUT), D63.4 (DIN)
unnamed: D34.2 (DOUT), D57.4 (DIN)
unnamed: D35.4 (DIN), D59.2 (DOUT)
unnamed: D35.2 (DOUT), D64.4 (DIN)
unnamed: D4.2 (DOUT), D36.4 (DIN)
unnamed: D5.4 (DIN), D36.2 (DOUT)
unnamed: D5.2 (DOUT), D37.4 (DIN)
unnamed: D37.2 (DOUT), D38.4 (DIN)
unnamed: D6.4 (DIN), D39.2 (DOUT)
unnamed: D6.2 (DOUT), D40.4 (DIN)
unnamed: D40.2 (DOUT), D60.4 (DIN)
unnamed: D41.4 (DIN), D60.2 (DOUT)
unnamed: D41.2 (DOUT), D42.4 (DIN)
unnamed: D8.4 (DIN), D42.2 (DOUT)
unnamed: D8.2 (DOUT), D43.4 (DIN)
unnamed: D9.4 (DIN), D43.2 (DOUT)
unnamed: D9.2 (DOUT), D44.4 (DIN)
unnamed: D57.2 (DOUT), D58.4 (DIN)
unnamed: D61.4 (DIN), D64.2 (DOUT)
unnamed: D61.2 (DOUT), D62.4 (DIN)

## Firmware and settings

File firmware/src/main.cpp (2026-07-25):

// firmware/src/main.cpp
#include <Arduino.h>
#include "audio.h"
#include "buttons.h"
#include "display.h"
#include "display/renderer.h"
#include "ntp.h"
#include "rtc.h"
#include "wifi_provision.h"

#if defined(BENCH_BACKDOOR_SSID) || defined(BENCH_SIM)
#include <SD.h>                       // bench 'l' command: list SD root
#endif
#ifdef BENCH_BACKDOOR_SSID
// TEMP bench-only block — remove before final assembly. Injects WiFi
// credentials directly into NVS (same atomic write the captive portal
// uses) so bench iteration doesn't need the phone flow, and adds a
// serial command channel ('h'/'m'/'a') that mirrors the button events.
// Credentials arrive via -D build flags (pulled from the macOS keychain
// at build time); nothing secret lives in this file or in git.
// Build with -D BENCH_SIM=1 alone to get the serial sim + frame
// telemetry without the credential inject (board must already be
// provisioned).
#include "wifi_provision/form_parser.h"
namespace wc::wifi_provision::nvs_store {
    bool has_credentials();
    bool write(const FormBody& body);
}
#endif

static void handle_button_event(wc::buttons::Event e);

void setup() {
    Serial.begin(115200);
    Serial.printf("word-clock booting for target: %s\n", CLOCK_NAME);
    Serial.flush();  // TEMP boot breadcrumbs — remove after bench debug

#ifdef BENCH_BACKDOOR_SSID
    if (!wc::wifi_provision::nvs_store::has_credentials()) {
        wc::wifi_provision::FormBody creds;
        creds.ssid = BENCH_BACKDOOR_SSID;
        creds.pw   = BENCH_BACKDOOR_PASS;
        creds.tz   = "PST8PDT,M3.2.0,M11.1.0";
        bool ok = wc::wifi_provision::nvs_store::write(creds);
        Serial.printf("[bench] backdoor credential inject (%s): %s\n",
                      BENCH_BACKDOOR_SSID, ok ? "OK" : "FAILED");
        Serial.flush();
    } else {
        Serial.println("[bench] NVS already has credentials; backdoor idle");
        Serial.flush();
    }
#endif

    wc::wifi_provision::begin();   // runs setenv/tzset on warm boot
    Serial.println("[boot] wifi_provision::begin done"); Serial.flush();
    wc::rtc::begin();              // AFTER wifi_provision — load-bearing
                                   // so TZ is set before first now()
    Serial.println("[boot] rtc::begin done"); Serial.flush();
    wc::ntp::begin();              // AFTER wifi_provision; warm-boot
                                   // resume reads NVS-stored last-sync
    Serial.println("[boot] ntp::begin done"); Serial.flush();
    wc::display::begin();
    Serial.println("[boot] display::begin done"); Serial.flush();

    wc::buttons::begin(handle_button_event);
    Serial.println("[boot] buttons::begin done"); Serial.flush();
    wc::audio::begin({CLOCK_BIRTH_MONTH, CLOCK_BIRTH_DAY,
                      CLOCK_BIRTH_HOUR,  CLOCK_BIRTH_MINUTE});
    Serial.println("[boot] audio::begin done — setup complete"); Serial.flush();
}

static void handle_button_event(wc::buttons::Event e) {
    using BE = wc::buttons::Event;
    using WS = wc::wifi_provision::State;
    switch (e) {
        case BE::HourTick:
            wc::rtc::advance_hour();
            break;
        case BE::MinuteTick:
            wc::rtc::advance_minute();
            break;
        case BE::AudioPressed:
            if (wc::wifi_provision::state() == WS::AwaitingConfirmation) {
                wc::wifi_provision::confirm_audio();
            } else if (wc::audio::is_playing()) {
                wc::audio::stop();
            } else {
                wc::audio::play();
            }
            break;
        case BE::ResetCombo:
            Serial.println("[buttons] ResetCombo — resetting to captive portal");
            wc::wifi_provision::reset_to_captive();
            break;
    }
}

void loop() {
#ifdef BENCH_BACKDOOR_SSID
#define BENCH_SIM 1
#endif
#ifdef BENCH_SIM
    // TEMP: serial button simulation — 'h' hour, 'm' minute, 'a' audio,
    // 'X' reset-to-captive (wipes NVS + restarts — bench only).
    // Same dispatch as the physical switches; ResetCombo deliberately
    // not exposed (it wipes NVS).
    while (Serial.available()) {
        char c = (char)Serial.read();
        using BE = wc::buttons::Event;
        if      (c == 'h') { Serial.println("[bench] sim HourTick");     handle_button_event(BE::HourTick); }
        else if (c == 'm') { Serial.println("[bench] sim MinuteTick");   handle_button_event(BE::MinuteTick); }
        else if (c == 'a') { Serial.println("[bench] sim AudioPressed"); handle_button_event(BE::AudioPressed); }
        else if (c == 'r') {
            // Restore DS3231 from the NTP-true system clock (button ticks
            // above only skew the DS3231, never the system clock).
            wc::rtc::set_from_epoch((uint32_t)time(nullptr));
            Serial.println("[bench] DS3231 restored from system clock");
        }
        else if (c == 'X') {
            Serial.println("[bench] reset_to_captive (NVS wipe + restart)");
            wc::wifi_provision::reset_to_captive();
        }
        else if (c == 'l') {
            // List SD root: name + size. Audio owns the mount; SD is the
            // Arduino global, safe to read between playback pumps.
            File root = SD.open("/");
            if (!root) {
                Serial.println("[bench] SD root open failed");
            } else {
                Serial.println("[bench] SD root listing:");
                for (File f = root.openNextFile(); f;
                     f = root.openNextFile()) {
                    Serial.printf("[bench]   %-16s %8u bytes%s\n",
                                  f.name(), (unsigned)f.size(),
                                  f.isDirectory() ? " <dir>" : "");
                    f.close();
                }
                root.close();
                Serial.println("[bench] end of listing");
            }
        }
        else if (c == 'b') {
            // Play birth.wav on demand (does not stamp the NVS birthday
            // guard) — audible verification after an SD reload.
            Serial.println("[bench] play birth.wav");
            wc::audio::play_birthday_message();
        }
    }
#endif
    wc::wifi_provision::loop();
    wc::buttons::loop();
    wc::ntp::loop();               // sync scheduler; no-op when not Online
    wc::audio::loop();             // pump I²S when Playing; auto-fire check when Idle

    // Throttle display rendering to ~30 Hz. At full loop speed (~1 kHz,
    // given the delay(1) below) the display was re-rendering 1000× per
    // second — pure waste, plus saturating the ESP32 enough that the
    // UART serial output became garbled during bench-tests. 30 Hz is
    // plenty for the only animated element (birthday rainbow, 60 s
    // period) and comfortable for button/audio CPU budget.
    static uint32_t last_render_ms = 0;
    const uint32_t now = millis();
    if (now - last_render_ms >= 33) {
        last_render_ms = now;

        // Render the clock face whenever we have trustworthy time — i.e.,
        // at least one successful NTP sync has happened on this device
        // (seconds_since_last_sync() != UINT32_MAX). That signal also
        // implies wifi_provision::begin() ran setenv/tzset, so
        // localtime_r() inside rtc::now() returns fields in the user's
        // zone. We deliberately DO NOT gate on state() == Online:
        // the parent spec §Time sync promises the clock free-runs on the
        // DS3231 during WiFi drops / reconnects / captive-portal re-entry.
        //
        // Blank falls through only when there is no trustworthy time:
        // never provisioned (NVS last_sync == 0 — first-ever boot or a
        // post-reset-to-captive wipe, where TZ is unset too), or the
        // DS3231 lost power so rtc::begin() declined to seed the system
        // clock. A warm boot with a good coin cell seeds time(nullptr)
        // from the DS3231 in rtc::begin(), so the face shows (stale,
        // amber-tinted) DS3231 time immediately — even with WiFi down —
        // instead of going dark.
        uint32_t sync_age = wc::wifi_provision::seconds_since_last_sync();
        if (sync_age != UINT32_MAX) {
            // rtc::now() is a blocking I²C read and the face only changes
            // per minute, so cache it and re-read at ~1 Hz rather than on
            // every 33 ms render tick. The rainbow animation uses now_ms
            // (millis) and still advances every frame.
            static wc::rtc::DateTime cached_dt{};
            static uint32_t last_rtc_ms = 0;
            if (last_rtc_ms == 0 || now - last_rtc_ms >= 1000) {
                last_rtc_ms = now;
                cached_dt = wc::rtc::now();
            }
            const wc::rtc::DateTime& dt = cached_dt;
            wc::display::RenderInput in{};
            in.year   = dt.year;
            in.month  = dt.month;
            in.day    = dt.day;
            in.hour   = dt.hour;
            in.minute = dt.minute;
            in.now_ms = now;
            in.seconds_since_sync = sync_age;
            in.birthday = {CLOCK_BIRTH_MONTH, CLOCK_BIRTH_DAY,
                           CLOCK_BIRTH_HOUR,  CLOCK_BIRTH_MINUTE};
            wc::display::Frame frame = wc::display::render(in);
#ifdef BENCH_SIM
            // TEMP: log the lit-LED set whenever it changes so the face
            // can be verified over serial without eyes on the board.
            {
                static uint64_t last_sig = 0;
                uint64_t sig = 0;
                int lit = 0;
                for (int i = 0; i < (int)frame.size(); i++) {
                    if (frame[i].r | frame[i].g | frame[i].b) {
                        sig ^= 0x9E3779B97F4A7C15ull * (uint64_t)(i + 1);
                        lit++;
                    }
                }
                sig ^= (uint64_t)lit << 56;
                if (sig != last_sig) {
                    last_sig = sig;
                    Serial.printf("[bench] frame %02u:%02u lit=%d idx=",
                                  in.hour, in.minute, lit);
                    for (int i = 0; i < (int)frame.size(); i++)
                        if (frame[i].r | frame[i].g | frame[i].b)
                            Serial.printf("%d,", i);
                    Serial.println();
                }
            }
#endif
            wc::display::show(frame);
        } else {
            // Pre-first-sync: blank. Captive portal is running here;
            // displaying UTC (or DS3231 lost-power garbage) would be
            // more confusing than a dark face while Dad provisions.
            wc::display::show(wc::display::Frame{});
        }
    }

    delay(1);  // yield to IDLE for watchdog + WiFi
}

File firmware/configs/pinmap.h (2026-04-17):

// firmware/configs/pinmap.h
//
// Shared GPIO pin assignments for every Phase 2 firmware module.
// Source of truth: docs/hardware/pinout.md §Firmware constants.
//
// The `configs/` directory is on the ESP32 envs' -I include path via
// `[esp32-base] build_flags = -I configs` in platformio.ini, so any
// Arduino-env source can `#include "pinmap.h"`. Native/pure-logic code
// never includes this header — it doesn't touch hardware.
#pragma once

// WS2812B LED strip
#define PIN_LED_DATA     13

// DS3231 RTC (I²C default pins)
#define PIN_I2C_SDA      21
#define PIN_I2C_SCL      22

// microSD card (VSPI)
#define PIN_SD_CS         5
#define PIN_SD_MOSI      23
#define PIN_SD_MISO      19
#define PIN_SD_CLK       18

// MAX98357A I²S amplifier
#define PIN_I2S_BCLK     26
#define PIN_I2S_LRC      25
#define PIN_I2S_DIN      27

// Tact switches (INPUT_PULLUP, other leg to GND)
#define PIN_BUTTON_HOUR   32
#define PIN_BUTTON_MINUTE 33
#define PIN_BUTTON_AUDIO  14

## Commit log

2026-04-15 dakaneye/ci firmware (#1)
    * chore: scaffold public-repo baseline files
    * docs: conventions, implementation plan, and 3d printer decision spec
    * feat: scaffold platformio project with emory and nora envs
    * ci: build both firmware envs and run native tests on PR
    * fix(firmware): unset board for native env to avoid esp32dev resolution
    * fix(firmware): isolate native env from arduino deps and add placeholder test
    [main.cpp]
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2026-04-15 fix(firmware): treat all AM hours as morning, not just 05:00-11:59
    [test_time_to_words.cpp]
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2026-04-16 fix(firmware): relocate AT to row 11 for reading order; row-major led numbering
2026-04-16 docs: single rework guide for led reorder + AT fix + finish pcb
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2026-04-16 fix(docs): rewrite rework guide - no schematic rearrangement, wire by value name
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2026-04-16 fix(enclosure): box-joint fingers stay at strip edge, slots cut inward
    Previous geometry had fingers extending BEYOND the strip body
    (to X=198.4 and X=-6.4), which would have produced an invalid
    cut file (paths outside the declared sheet). Correct box-joint
    construction has slots cut INTO the body and fingers at the
    nominal strip edge. Added regression test that asserts no path
    coordinate exceeds [0, FRAME_LENGTH_MM].
2026-04-16 refactor(enclosure): deduplicate frame + drop cardboard test
    Emory and Nora frames are byte-identical (render_frame_svg takes no
    kid parameter — geometry is the same). Merged to one frame.svg;
    the kid-specific distinction is the wood material selected when
    uploading to Ponoko, not the SVG content.
    Cardboard test variant removed — the test didn't de-risk the actual
    failure modes (hardwood grain, kerf, scorching) because cardboard
    laser behavior is different. Ponoko's design checker is sufficient
    validation.
2026-04-16 fix(enclosure): union overlapping glyph subpaths for clean cut outlines
    Jost Bold builds letters from overlapping primitives (E = stem + 3 bars,
    H = 2 stems + crossbar). fontTools emits each primitive as a separate
    subpath. For fill-based rendering the overlaps blend invisibly — but
    for laser cutting, each subpath becomes an independent cut, fragmenting
    the letter into pieces.
    New path_ops module does winding-aware boolean union:
    CCW subpaths (outer rings) are unioned together
    CW subpaths (counters) are unioned separately
    Final shape = outer_union.difference(hole_union)
    This produces clean letter outlines with counters as proper holes,
    matching what font fill rendering shows. Bezie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
2026-04-16 fix(enclosure): strut length scales with counter; winding detection is adaptive
    Two bugs in previous strut implementation:
    1. Fixed 20mm bridge length obliterated letter readability — strut
    sliced through the entire letter, not just the ring at the counter.
    Fix: derive bridge length from counter bbox dimension so it spans
    only what's needed to cross the ring.
    2. Fraunces (CFF outlines) uses OPPOSITE winding from Jost (TrueType):
    outer contours are CW instead of CCW. Fixed-winding detection
    classified Fraunces outers as holes and vice versa, so no struts
    were added and the glyphs may have been incorrectly unioned. Fix:
    detect each glyph's outer-winding convention from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
2026-04-16 fix(enclosure): single struts on R/P/D per spec (was over-zealous)
    User spec had singular strut for R ('strut along the left vertical
    line'), P ('same as R'), D ('like R'). Previous commit used 2
    struts at y=0.25 and y=0.75 which over-subscribed. Pulled back to
    1 strut at y=0.5 (middle of counter) to match the original
    description and reduce visual weight.
    Also: added cairosvg-based local SVG-to-PNG rendering workflow
    (/tmp/svg_review/*.png) so future strut / font tweaks can be
    reviewed without round-tripping through Ponoko.
2026-04-16 fix(enclosure): drop strut width to 1mm per Chelsea precedent
    User successfully cut 1mm struts on their Chelsea clock (different
    laser cutter). Ponoko's published hardwood min-feature is 3mm but
    the actual cuttability at 1mm is likely fine on their laser too —
    cardboard test cut now worthwhile to verify before committing the
    ~$140 hardwood order.
    Visual result: struts are now proportionate to letter stroke
    thickness (Jost Bold ~1.5mm strokes; Fraunces Medium ~0.6mm).
    Readability restored without losing counter retention.
2026-04-16 fix(enclosure): multiple strut bugs — interior positions, arrow effect, sliver holes
    Found via self-review using cairosvg local rendering:
    1. A's H strut at x_frac=0.3 was INTERIOR (entirely inside counter) — had
    zero effect on the cut. The letter was only getting connected via the
    V strut which caused the 'arrow' effect. Moved H to x_frac=0 boundary.
    2. A's V strut at bottom of counter was non-structural: upper counter
    island can't connect to outside-A wood through the below-crossbar area
    because that's also part of the letter polygon (= aperture = gets cut).
    Removed — H at left boundary alone is structurally sufficient.
    3. G had the same interior-position bug (x_fra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
2026-04-16 fix(enclosure): asymmetric bridge — body_margin 3mm / counter_margin 1.5mm
    Split the bridge extension into two named margins:
    body_margin (3mm): how far the strut punches into the letter stroke.
    Must exceed stroke thickness (~1.5-2mm on Jost Bold stems) so the
    preserved wood reaches outside-letter face. Previous 2mm didn't
    punch through Jost stems cleanly on R/P/B/D.
    counter_margin (1.5mm): how far it extends into the counter. Kept
    small so the strut doesn't reach interior features like G's
    inward crossbar (which caused a 'splash' notch on Fraunces G).
2026-04-16 fix(enclosure): B, 6/9 splash, and Fraunces font artifacts
    Three fixes after iterative self-review via cairosvg rendering:
    1. Jost B was getting ZERO struts. Its self-intersecting single
    subpath turned into a GeometryCollection after make_valid(). The
    pre-existing filter 'geom_type not in (Polygon, MultiPolygon)'
    silently skipped it, producing 0 holes. Normalized the post-
    make_valid result via _extract_polygons(), which recursively
    flattens GeometryCollection / MultiPolygon to Polygons.
    2. 6 and 9: V struts at y_frac=0/1 produced a visible 'splash' — a
    long vertical slot from the counter to the letter edge. Switched
    both to H struts at left (x_frac=0, y_frac=0.5), m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
2026-04-16 fix(enclosure): aspect filter for Jost B + simplify for Fraunces serifs
    1. Jost B's crossbar region produced a spurious wide-aspect hole (278×118,
    aspect 2.4) alongside the 2 real counters (~1.1 aspect). Added aspect-
    ratio filter: skip holes with aspect > 2.0. Real counters are always
    close to square/round; highly elongated shapes are polygon-op artifacts.
    2. Increased bezier curve flattening from 16 to 64 steps. Fraunces' fine
    serif curves were producing visible angular artifacts at junctions.
    Still well under laser-cut precision chord error.
    3. Added buffer(0) + simplify() pass after union to remove sub-laser-
    precision spikes from bezier flattening. Tolerance = 0.05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
2026-04-16 fix(enclosure): preserve beziers on non-strut letters + buffer(0) for B
    Two issues were causing bezier-splash artifacts in the rendered faces:
    1. Every glyph went through flatten → shapely union → reserialize, which
    turned Fraunces's serif curves into zigzag polylines. Added a fast path
    that returns the raw path untouched when the letter has no strut rule
    and is a single subpath — covers ~half the Fraunces alphabet.
    2. Self-intersecting paths (Jost B packs outer + 2 counters into one
    path via TrueType winding) were being repaired with make_valid, which
    collapses the counters into the outer. buffer(0) correctly produces
    a Polygon with interior rings; fall back to mak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
2026-04-16 fix(hardware): remove cermant usb-c breakout, power via esp32 micro-usb
    Removes J_USB1 from the schematic and PCB. The user-facing USB-C port on
    the back panel will now be provided by a panel-mount USB-C-female-to-
    micro-USB-male pigtail plugged directly into the ESP32 module's native
    micro-USB connector. The CP2102 bridge on the module handles both power
    and firmware flashing — one port, one hole in the back panel, no PCB
    data-routing rework needed.
    PWR_FLAG on +5V re-attached to the module's 5V pin to satisfy ERC.
    Downstream docs updated:
    - pinout.md Power/Input line now describes the new path.
    - phase-2-parts-list.md marks the old USB-C breakout as superseded on the
    final PCB (still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
    [word-clock.kicad_pcb, word-clock.kicad_sch]
2026-04-16 feat(enclosure): pcb ↔ face alignment overlay + regression tests
    Adds a render_overlay module that produces a 1:1 US Letter PDF showing the
    letter grid, letter labels (from grid.cpp), PCB outline, mounting holes,
    and actual LED centers (read directly from word-clock.kicad_pcb, not the
    CSV intermediary — so it cannot go stale). Blue ideal-word-center dots
    pair with red LED crosshairs so the documented (−1.5, −0.5) mm placement
    offset is visible at every LED.
    Five pytest cases pin the alignment invariants so future KiCad edits that
    break grid geometry, drop LEDs, move them outside the grid, or shift the
    known offset will fail the suite rather than surface during assembly.
    48/48 tests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
2026-04-16 docs(hardware): bottom-side component heights + standoff budget
    Table of every bottom-side footprint with estimated heights from package
    datasheets + common daughterboard / header standards. Tallest feature is
    the MAX98357A screw-terminal variant at ~19 mm. Recommended back-panel
    standoff: 20 mm, leaving ~18 mm of depth for the light-channel honeycomb
    inside the 48 mm frame — comfortably above the ≥14 mm LED-spacing minimum
    for uniform diffusion.
    Confidence [MED] on the daughterboard heights; re-verify with calipers
    when the parts arrive and tighten the depth budget if the screw-terminal
    MAX98357A was over-estimated.
2026-04-16 docs: lock "back panel removable" as a hard requirement
    Back panel must be fully removable without damaging the wood, repeatably
    over the clock's 40+ year service life. Forcing function is the DS3231
    CR2032 coin cell — 5-10 year life means 4-8 replacements per unit, bare
    minimum. Glue, nails, and other one-way fasteners are ruled out.
    Recommended attachment: M3 brass threaded inserts in the frame interior
    + countersunk brass machine screws through the panel. Unlimited removal
    cycles, no stripping, wood-tone aesthetic. TODO.md documents the
    alternative options considered (magnets, direct wood screws, rabbet) and
    why each was rejected.
2026-04-16 docs: daughterboard orientation + sd slot on back panel
    Two adjacent serviceability concerns for long-lived battery / SD access:
    1. DS3231 + HW-125 breakouts hang into the PCB↔back-panel air gap. If
    installed backwards, the CR2032 holder and SD slot end up pressed
    against the main PCB — trapped. Adding silkscreen markers next to
    J_RTC1 and J_SD1 on the main PCB so correct orientation is obvious
    during hand assembly.
    2. Audio updates (SD card swaps) happen more often than CR2032 swaps.
    Adding a small rectangular microSD cutout to the back panel SVG so
    cards can be changed without removing the whole panel. Battery access
    still goes through the fully-removed panel (ra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
2026-04-19 fix(firmware): clock face free-runs on RTC during WiFi drops
    Parent spec §Time sync promises "No WiFi: free-runs on DS3231.
    Drift is low (seconds per week) — acceptable." The previous main.cpp
    gated ALL display rendering on wifi_provision::state() == Online,
    which meant a router reboot or captive-portal re-entry blanked the
    clock face entirely for 30-300 s of reconnect backoff. Visibly
    violates the spec.
    Replace the Online gate with a "have we ever synced" gate via
    wifi_provision::seconds_since_last_sync(). That signal implies
    setenv/tzset has run (wifi_provision loads stored TZ on every boot
    when creds exist), so localtime_r() inside rtc::now() returns fields
    in the user's zone — whet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
    [main.cpp]
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2026-04-20 chore: serial_capture helper + bump validation timeout to 60s
    Two bench-bring-up quality-of-life improvements:
    1. Add firmware/scripts/serial_capture.py — live-stream ESP32 serial
    output with configurable duration, optional RTS reset, NVS-noise
    filtering, and auto port detection. Replaces the ad-hoc inline
    Python one-liners I was writing in shell each time.
    2. Bump VALIDATING_TIMEOUT_MS from 30s to 60s. Bench-observed
    intermittent timeouts on 2026-04-20 where the first-try STA
    handshake took >30s on a mildly congested 2.4 GHz band. Retry
    usually succeeded, but the user shouldn't need a retry. 60s adds
    safety margin with no downside on fast networks.
    [serial_capture.py]
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2026-04-21 perf(main): throttle display render to ~30 Hz
    At full loop speed (~1 kHz given the trailing delay(1)) the display was
    re-rendering 1000 times per second — pure waste. Also saturated the
    ESP32 enough that UART serial output became garbled during bench-tests
    (the settimeofday fix commit lit the display, which immediately made
    the render loop run constantly).
    30 Hz is plenty for the only animated element (birthday rainbow, 60 s
    period) and comfortable for button/audio CPU budget. Throttled via a
    static last-render timestamp + 33ms threshold.
    Verified on hardware — display still animates smoothly, serial output
    legible, audio playback crisp.
    [main.cpp]
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2026-04-21 fix(hardware): swap J_RTC1 and J_SD1 to right-angle female sockets
    DS3231 (HW-084) and HW-125 modules ship with right-angle pins that
    don't fit into vertical through-hole sockets without bending. Swap the
    PCB footprints from PinHeader_1x06_P2.54mm_Vertical to
    PinSocket_1x06_P2.54mm_Horizontal so the daughterboards plug directly
    in with the modules lying parallel to the main PCB.
    Pad global positions preserved in both footprints so existing routing
    is unchanged. J_SD1 keeps rot=180 with Y-mirrored coords (body extends
    east into clear space); J_RTC1 uses rot=0 with un-mirrored coords
    (body extends west, away from ESP32 at +X).
    Also gitignore *.xlsx and word-clock-gerbers-*.zip so generated P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
    [word-clock.kicad_pcb, word-clock.kicad_sch]
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2026-05-02 chore: session updates — hardware decisions + audio playlist design
    Hardware design decisions captured this session, plus tooling for the
    3D-printed light channel and a bench-test sketch for diffuser-stack
    bleed validation. Audio playlist spec + plan added for the upcoming
    firmware change.
    Documentation:
    - TODO.md: cable port (drill 6→16 mm + grommet + P-clip), back-panel
    attachment (M3 wood screws into frame wall, abandoning hex-spacer
    plan), light-channel envelope locked at frame-interior measurement,
    no-foam decision, Emory frame angle correction strategy
    - assembly-plan.md: rewrite Phase D (face sub-assembly), Phase F
    (back panel internals), Phase G (closeout); Phase C remov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
    [main.cpp]
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2026-05-06 test(hardware): all-on chain walker for full-strip brightness check
    Replace the single-LED R/G/B/off cycle with all-35-LEDs solid red so
    the bench check can verify full-chain visibility, brightness, and
    even illumination across the face — the 1-LED variant is a wiring
    sanity check and didn't surface chain or brightness issues that only
    appear under aggregate load.
    [main.cpp]
2026-05-06 test(hardware): softap-only sketch for WiFi-radio bring-up isolation
    Minimal sketch (just Serial.begin + WiFi.softAP + a 1 Hz tick) to
    isolate the WiFi radio from every other peripheral during bring-up.
    Used during a brownout/reset-loop investigation to confirm that the
    chip stays alive when WiFi is initialized in isolation, ruling out
    RF-induced misbehavior and pointing to the real cause (TASK_WDT
    firing on a busy loop without delay(1)).
    Useful as a future bring-up step between 01_blink and the full
    emory firmware: if 08_softap_only stays clean but emory garbles,
    the issue is downstream of WiFi radio init, not the radio itself.
    [main.cpp]
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2026-06-13 chore(hardware): track regenerated 63-LED master BOM
    The master BOM (hardware/word-clock.csv) that CLAUDE.md names the source
    of truth was gitignored and stale (35-LED topology, empty part columns).
    Replace it with a current as-built BOM regenerated from the 63-LED KiCad
    source: 63 WS2812B-V6 LEDs (D7 unused), 22x 100nF + 1x 1000uF, R1, the
    three daughtercard modules, 3 buttons, ESP32, and U2 74HCT245. LCSC is
    filled for the JLC-placed LED (C52917433); hand-soldered parts are noted
    as such with sourcing. Drop the ignore line so it lives in git.
    [word-clock.csv]
2026-06-14 docs(hardware): correct pre-arrival prep notes
    Follow-ups from the pre-arrival readiness check:
    - word-clock.csv + pinout.md: the DS3231 trickle-charge resistor is KEPT,
    not removed (decision 2026-04-20 — inert at 3.3V VCC, mitigated by the
    5-year CR2032 cadence). Corrects a wrong "remove it" note.
    - assembly-plan.md: mark the light-channel honeycomb as printed (it was
    still listed deferred), with a dry-fit-before-assembly note.
    - TODO.md: add the THT board passives (74HCT245, 44x 100nF, 1000uF, 300R)
    to "Still to buy" — they were never purchased and gate the first bench
    check.
    [word-clock.csv]
2026-06-15 fix(rtc): seed system clock from DS3231 at boot
    ntp::loop() set the ESP32 system clock via settimeofday() only after a
    live NTP sync, and nothing seeded it from the battery-backed DS3231 at
    boot. So time(nullptr) stayed boot-relative until the first sync, and
    wifi_provision::seconds_since_last_sync() (time(nullptr) vs the NVS
    last_sync stamp) returned UINT32_MAX. main.cpp gates all rendering on
    that signal, so a warm boot while WiFi was unavailable blanked the face
    permanently — despite correct DS3231 time — and the ntp warm-boot resume
    branch was unreachable (every reboot re-synced immediately).
    Seed time(nullptr) from the DS3231 in rtc::begin(), guarded by
    lostPower() + DateTime::isVa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
    [main.cpp]
2026-06-15 fix(audio): harden adapter + throttle blocking RTC reads
    Review findings in the audio adapter and main loop (clusters 2 + 3):
    Robustness:
    - Latch i2s_ok from i2s_install() and gate play_lullaby + auto-fire on
    it, so a dead I2S no longer "fires" the birthday silently.
    - Stamp the NVS birthday year only AFTER birth.wav actually opens
    (state_ == Playing), so a missing/corrupt file or dead I2S no longer
    burns the birthday for the year — it retries until it really plays.
    - Retry SD.begin() on a 30 s cadence instead of latching audio off
    forever after a boot-time mount failure.
    - Clamp the pump to the WAV data chunk (ParseResult::data_size_bytes)
    so trailing RIFF chunks are not played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
    [main.cpp]
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2026-07-13 fix(tools): verify restore on sd loader failure paths
    Load-phase exceptions were propagating past the finally block that
    restored flash, skipping boot_check() and the narrated success/failure
    report entirely. Restructure so a load failure is captured, the restore
    always runs when the loader was flashed, boot_check() always follows a
    successful restore write, and the original error plus restore/boot
    outcome are narrated before a nonzero exit. A failed restore write now
    exits with a distinct code (2) and prints the recovery command without
    an unhelpful traceback. Also fixes httpd.shutdown() not running if
    Clock construction raised, and drops the unused FIRMWARE constant.
    [sd_load.py]
2026-07-13 fix(tools): verify ok-got payloads and survive interrupts
    Extend parse_line to surface the got={name,size,crc} payload on "OK
    got" replies so transfer() can reject stale/mismatched OK lines from
    the clone CP2102's replay behavior instead of accepting any OK as
    success. Catch BaseException in the load-phase handler so Ctrl-C
    still triggers the restore + boot-check path instead of leaving the
    clock on the loader firmware. Widen the READY wait window to 35s and
    guard the --restore-only path with a narrated failure exit.
    [sd_load.py, sd_load_core.py, test_sd_load_core.py]
2026-07-13 fix(tools): harden sd loader per adversarial review
    Review findings from the full /review-code pass, all verified against
    the code before fixing:
    - treat the loader upload itself as flash-dirtying: a failed or
    interrupted upload now routes through the automatic restore instead
    of re-raising with a partially-written chip and no recovery hint
    - verify every flash backup before trusting it (exact flash size +
    ESP32 bootloader magic at 0x1000), on capture and on --restore-only;
    a truncated dump can no longer be written back
    - one sd_load per port: flock lockfile prevents two concurrent runs
    from interleaving backup/restore and restoring the wrong image
    - extract the replay-safe serial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
    [bench_acceptance.py, main.cpp, sd_load.py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]
2026-07-25 fix(core): period suffix follows announced hour in to-phrasing
    At 11:40 the clock read TWENTY MINUTES TO TWELVE IN THE MORNING: the
    period-of-day suffix classified the current hour while the phrase
    announced the next one. The suffix now classifies the announced hour
    at its :00 instant, so approaching noon reads TO TWELVE NOON,
    approaching midnight TO TWELVE AT NIGHT, and the afternoon/evening
    and evening/night boundaries follow the spoken hour. Goldens
    regenerated (11:35-59, 16:35-59, 20:35-59); design spec codifies
    the rule.
    [test_time_to_words.cpp]
2026-07-25 fix(tools): canonicalize and normalize staged wavs
    afconvert inserts a FLLR padding chunk between fmt and data; the
    firmware's strict parser rejects it as BadDataMagic, so every loaded
    file played as silence while all CRCs matched. Staging now rewrites
    each WAV to the canonical 44-byte layout and validate_wav enforces
    data at offset 36 — exactly as strict as the firmware parser.
    Staging also peak-normalizes to -1 dBFS (never attenuates): voice
    memos land at unpredictable levels and the clock has no volume
    control.
    [sd_load.py, sd_load_core.py, test_sd_load_core.py]
2026-07-25 feat(audio): button plays birth.wav on the birthday
    On the kid's birthday (month+day, time synced at least once) the
    Audio button plays the birthday message instead of the lullaby
    playlist. New Idle-gated PlayBirthdayRequested event mirrors the
    lullaby request; routing never touches the NVS year stamp, so button
    plays neither burn nor block the birth-minute auto-fire, and an
    unsynced RTC falls back to lullabies. play_lullaby() renamed to
    play() to match its routing role. SD.h include now follows BENCH_SIM
    so telemetry builds without the credential backdoor.
    [main.cpp]
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
